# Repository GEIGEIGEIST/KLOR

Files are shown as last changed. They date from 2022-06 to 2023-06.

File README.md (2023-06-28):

<picture>
  <source media="(prefers-color-scheme: dark)" srcset="/docs/images/klor-font-logo-dark.svg">
  <source media="(prefers-color-scheme: light)" srcset="/docs/images/klor-font-logo-bright.svg">
  KLOR logo font
</picture>

# KLOR SPLIT KEYBOARD

KLOR is a 36-42 key column-staggered split keyboard. It supports a per-key RGB matrix, encoders, OLED displays, haptic feedback, speakers, a Pixart Paw3204 trackball, the [SplitKB tenting puck](https://splitkb.com/products/tenting-puck), and four different layouts, through break-off parts.

***

## LAYOUTS

KLOR layouts

***

## IMAGES

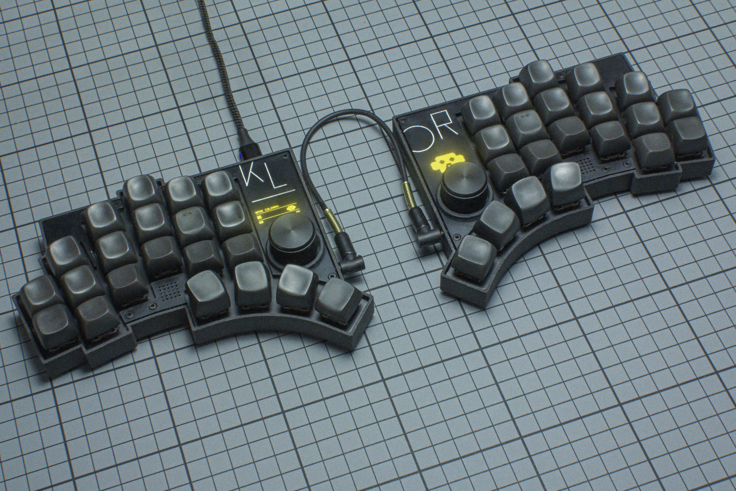
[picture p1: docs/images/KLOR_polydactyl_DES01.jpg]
KLOR polydactyl


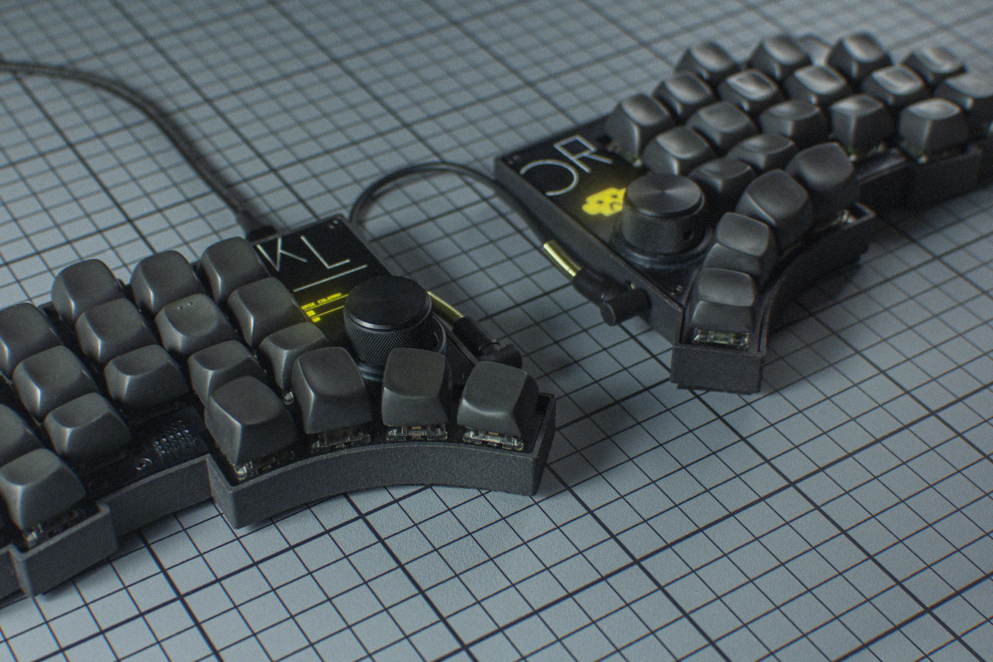
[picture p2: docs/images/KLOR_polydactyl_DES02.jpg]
KLOR polydactyl


▲ KLOR polydactyl with 3DP case and DES keycaps.

***

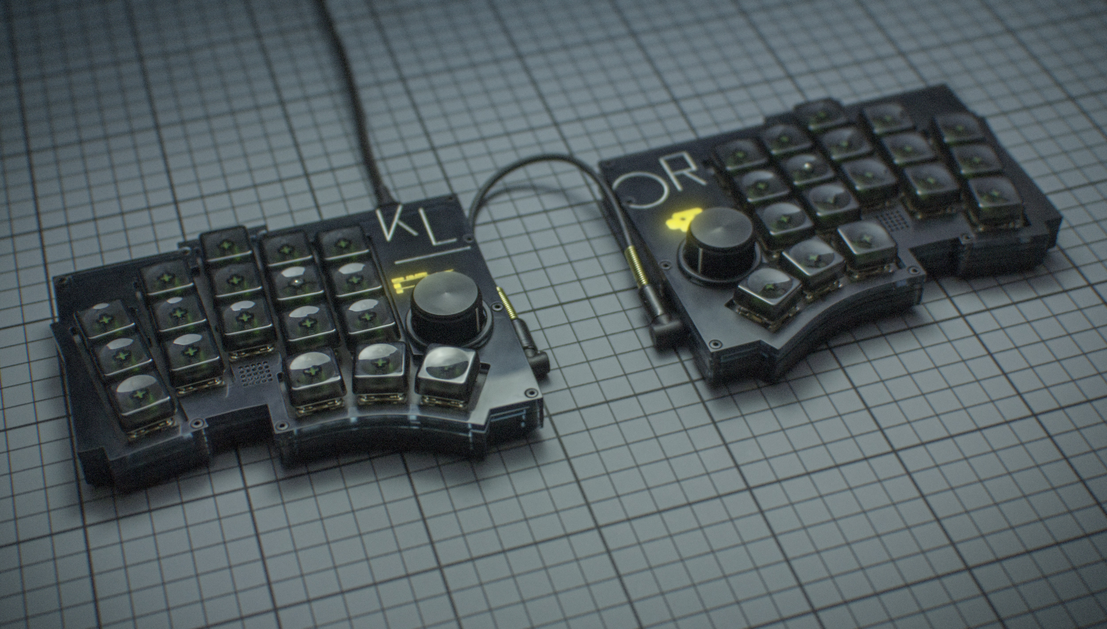
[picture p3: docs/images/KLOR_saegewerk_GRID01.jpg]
KLOR saegewerk


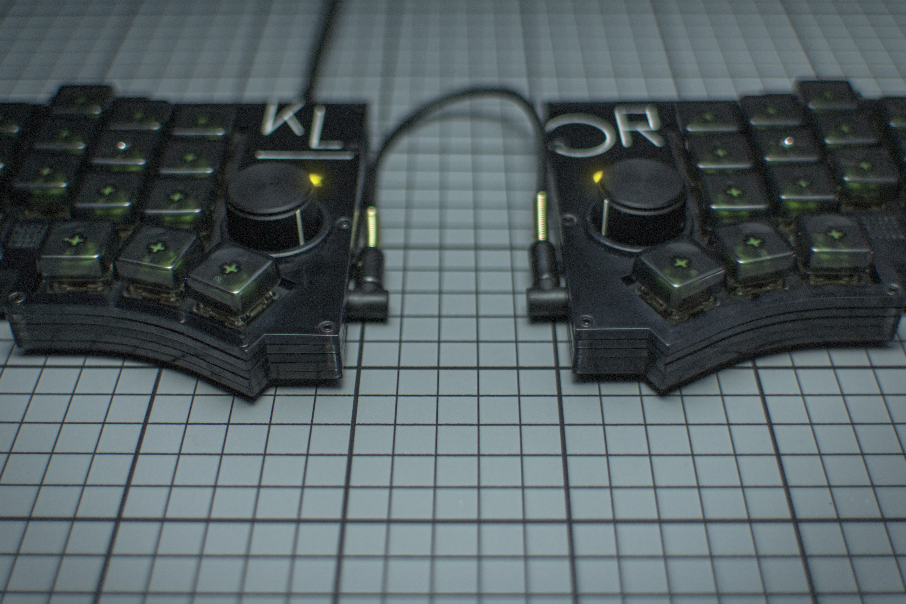
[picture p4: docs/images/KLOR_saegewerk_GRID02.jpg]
KLOR saegewerk


▲ KLOR saegewerk with stacked acrylic case and GRID keycaps.

***

## PCB 

[Here](/PCB/) you can find the KiCad files and Gerbers for the KLOR. 

***

## CASE

[Here](/case/) are the case files for the KLOR. There is an acrylic case and a 3D printed case (which uses acrylic too) for every layout.

***

## SWITCHPLATE

In every case directory you'll find the matching switchplates as **.dxf**, **.svg**, **.stl**, and a **.zip**-file, containing gerber files for a FR4 plate.

***

## KNOB

You can use pretty much any knob, which works with the EC11 encoder, but [here](/knob/) you can find one, I designed for the KLOR.

***

## BUILD GUIDE

Here you can find the build guides for the KLOR.\
[KLOR build guide 3DP case](/docs/buildguide_3DP.md) (QMK)\
[KLOR build guide stacked acrylic case](/docs/buildguide_acrylic.md) (QMK)\
[KLOR BLE build guide 3DP case](/docs/buildguide_3DP_ble.md) (ZMK)\
[KLOR BLE build guide stacked acrylic case](/docs/buildguide_acrylic_ble.md) (ZMK)

***

## FIRMWARE

[QMK config](https://github.com/GEIGEIGEIST/qmk-config-klor) (supports OLED, encoders, LEDs, haptic feedback and speakers)\
[ZMK config](https://github.com/GEIGEIGEIST/zmk-config-klor) (supports OLED, encoder, LEDs and Bluetooth)\
[KMK config](https://github.com/moritz-john/kmk-config-klor) (supports OLED, encoders, LEDs and speakers) made by [Moritz John](https://github.com/moritz-john)\
Thanks to [Manna Harbour](https://github.com/manna-harbour) you can find KLOR in [Miryoku ZMK](https://github.com/manna-harbour/miryoku_zmk)

***

## CHOC/KS27 VERSION

[Sadek Baroudi](https://github.com/sadekbaroudi) did an amazing job in creating a version of the KLOR which supports KS-27 and Choc V1 switches. Including a special case for it.\
[KLOR Sadek KS-27 and Choc V1 mod](https://github.com/sadekbaroudi/KLOR)

***

## CREDITS

The KLORs hardware is based on the [Sofle](https://github.com/josefadamcik/SofleKeyboard) by [Josef Adamcik](https://github.com/josefadamcik).\
Other inspirations are 
- [Kyria](https://splitkb.com/products/kyria-pcb-kit) by [Thomas Baart](https://github.com/splitkb)
- [Yacc46](https://github.com/1m38/keyboards/tree/main/yacc46) by [1m38](https://github.com/1m38)
- [Elephant42](https://github.com/illness072/elephant42) by [illness072](https://github.com/illness072)
- [Torn](https://github.com/rtitmuss/torn) by [Richard Titmuss](https://github.com/rtitmuss)
- [Claw44](https://github.com/yfuku/claw44) by [yfuku](https://github.com/yfuku)

I used the Pimoroni Haptic Buzz Footprint from the [Buzzard](https://github.com/crehmann/Buzzard) by [Christoph Rehmann](https://github.com/crehmann).

***

People who helped me create this board and fix stuff
- [KarlK90](https://github.com/KarlK90)
- [MangoIV](https://github.com/MangoIV)
- [OxCB](https://github.com/0xCB-dev)
- [MicroFortnight](https://github.com/microfortnight)
- [dreipunkteinsvier](https://github.com/dreipunkteinsvier)

If you build a KLOR I would be pretty happy to see some pictures. And if you want to leave me a tip you can do this [here](https://ko-fi.com/geigeigeist) (but please don't feel pressured)

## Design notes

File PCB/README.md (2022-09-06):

# KLOR PCB FILES

## MANUFACTURING
If you want to get the PCB made you need to download the [ZIP](/PCB/klor1_3/KLOR_1-3_gerbers.zip/) and upload it to the website of the manufacture ([JLCPCB](https://jlcpcb.com/) or [PCBway](https://www.pcbway.com/) for example).

- download [the ZIP file](/PCB/klor1_3/KLOR_1-3_gerbers.zip/)
- upload the ZIP file
- sometimes the Gerber preview from JLCPCB can't display the PCB, even when the files are fine. In this case use this dimensions: 159.8 mm* 118 mm
- PCB Thickness 1.6mm
- 2 layers
- PCB Qty as much as you like. But be aware, that you need 2 PCBs for one keyboard
- PCB Color Black
- No impedance control
- Surface Finish HASL(with lead) if you want the easiest soldering experience or LeadFree HASL.
- Remove Order Number Yes

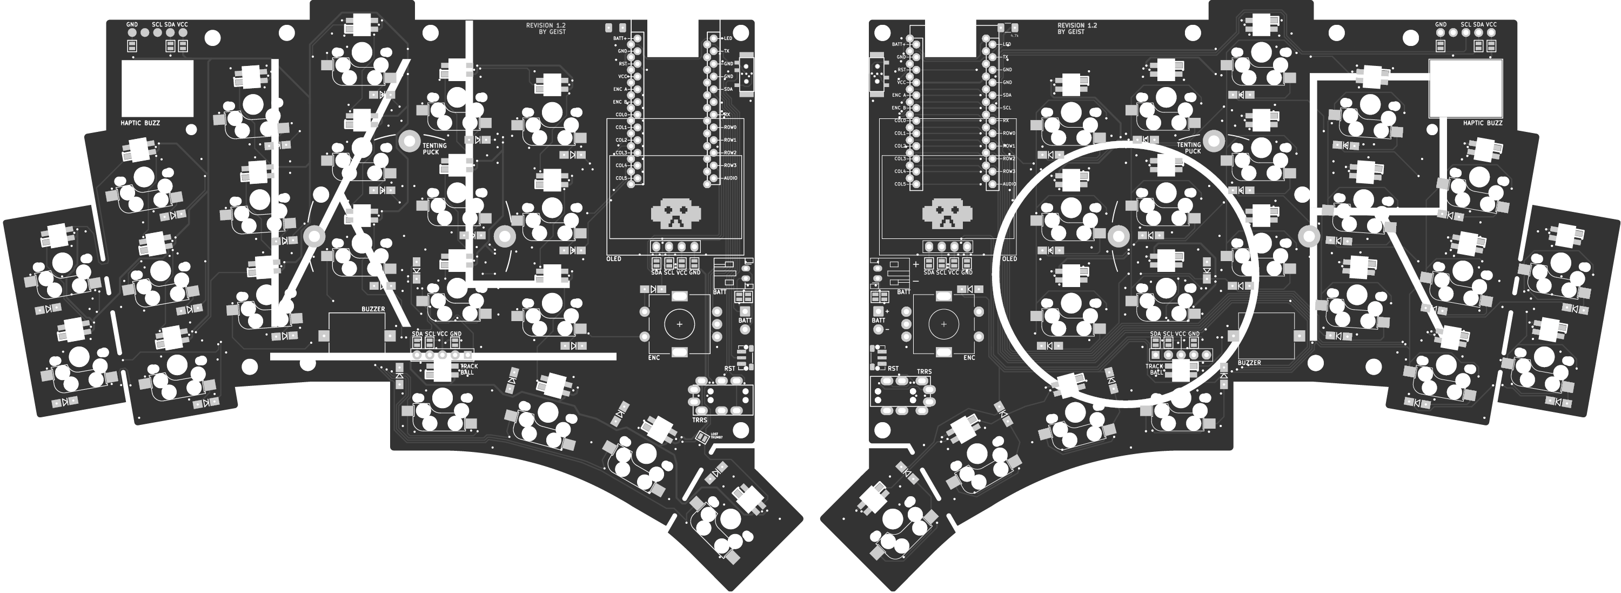
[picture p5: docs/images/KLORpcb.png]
KLOR pcb


## CHECK TRACES OR PINOUT

If you only want to check the traces or see what is connected to which pin you can take a look at these graphics.

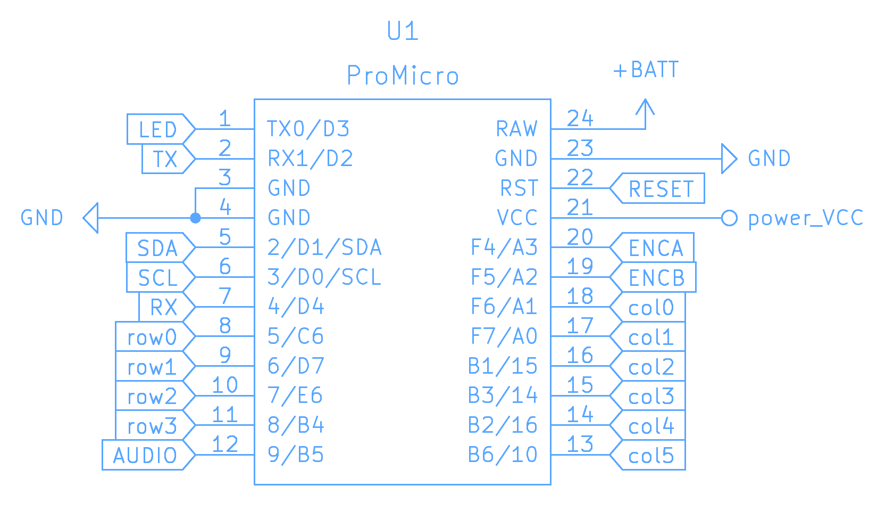
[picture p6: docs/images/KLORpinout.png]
KLOR pinout

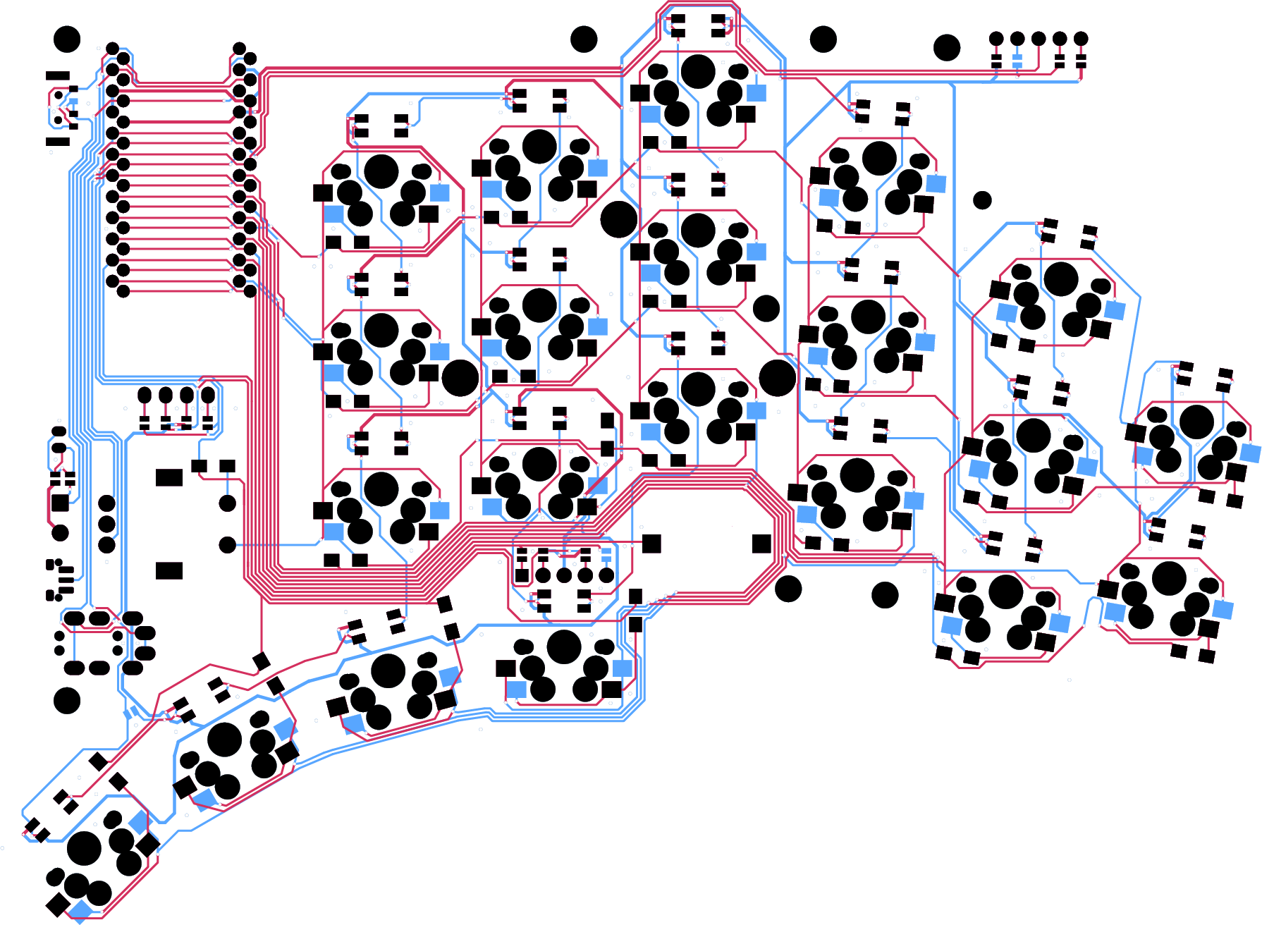
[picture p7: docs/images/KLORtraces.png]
KLOR traces

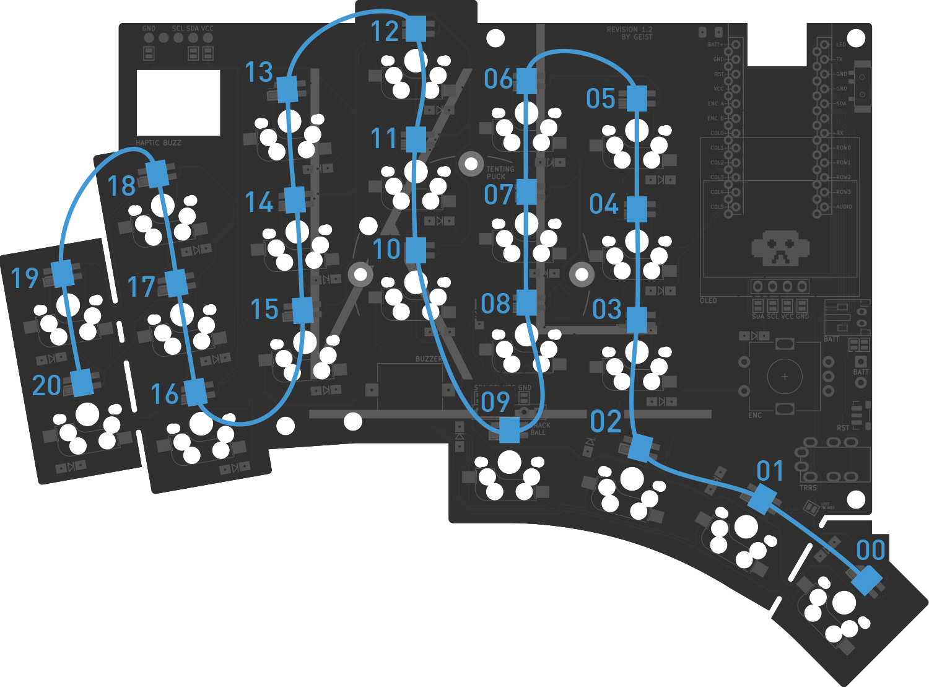
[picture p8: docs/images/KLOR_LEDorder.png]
KLOR LED order


## TAKE A DEEPER LOOK OR MODIFY 

You can download the project if you need to take a deeper look or modify something. You need the Open Source software [KiCad](https://www.kicad.org/) to open it.

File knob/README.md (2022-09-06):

# KLOR KNOB

This is the EC11 encoder knob for the KLOR. You should be able to print it in FDM, but for best results consider to print it in SLA or MJF.\
I can recommend to get it printed at [JLCPCB](https://jlcpcb.com/)

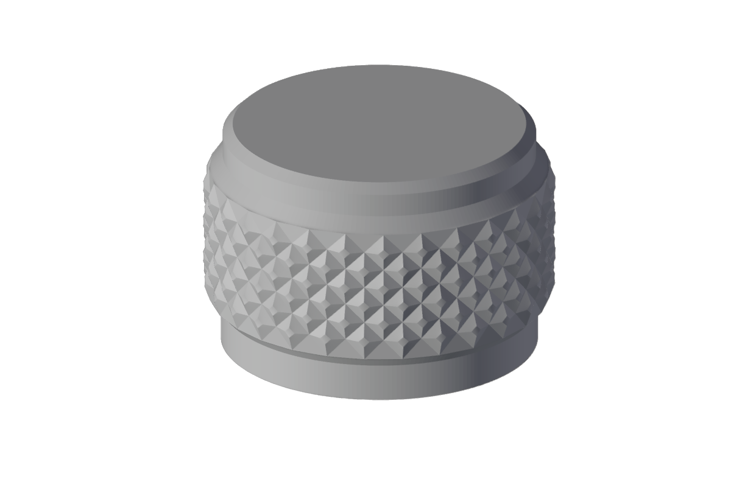
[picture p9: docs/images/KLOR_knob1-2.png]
KLOTZ knob


Here you can see it printed in black resin (left) and MJF nylon (right).

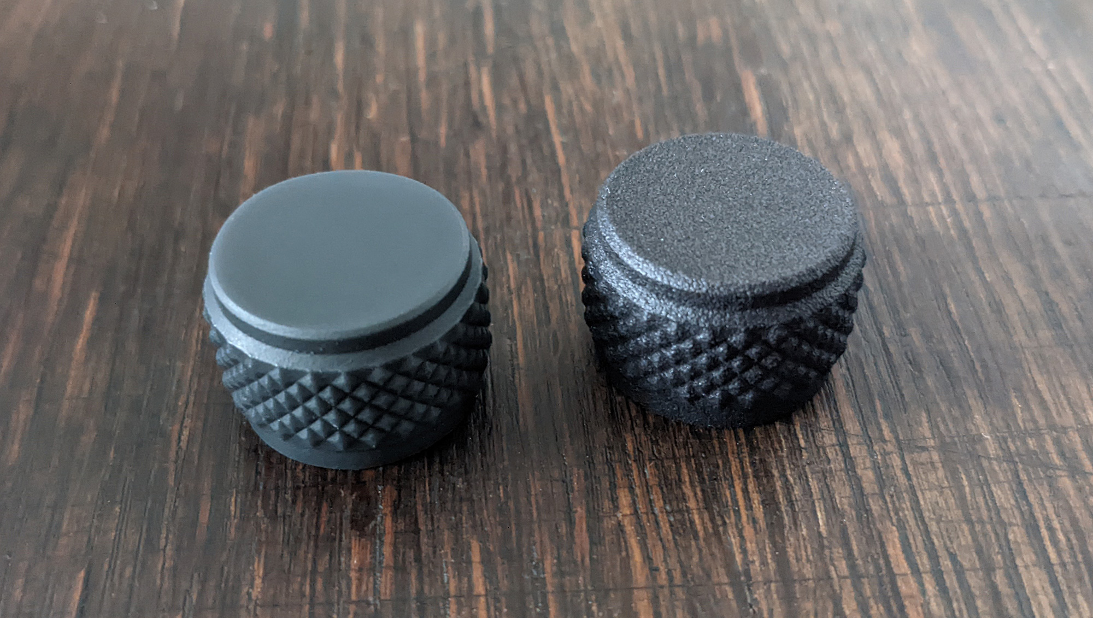
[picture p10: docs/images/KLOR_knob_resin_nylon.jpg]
KLOTZ knob materials


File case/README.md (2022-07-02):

# KLOR CASE FILES

First you need to decide if you plan to use a stacked acrylic case or a 3D printed case (which also contains acrylic parts).\
You can click on the image left for the acrylic case and on the image right for the 3D printed case.

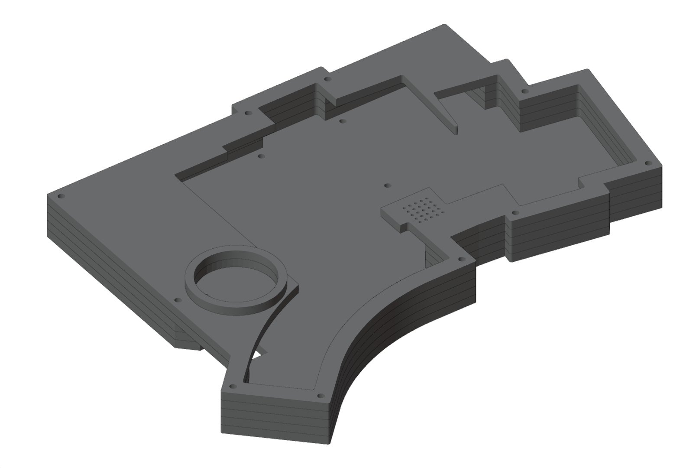
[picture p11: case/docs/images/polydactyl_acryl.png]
stacked acrylic case
[](/case/acrylic/)
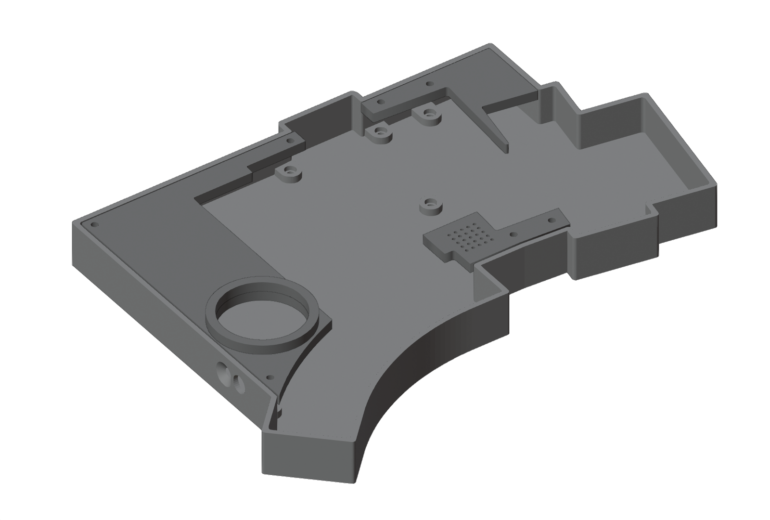
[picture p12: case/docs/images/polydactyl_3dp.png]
3D printed case
[](/case/3DP/)

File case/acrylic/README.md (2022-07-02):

# KLOR ACRYLIC CASE FILES

Next you need to decide which layout you want to use. 

[polydactyl](/case/acrylic/polydactyl/)
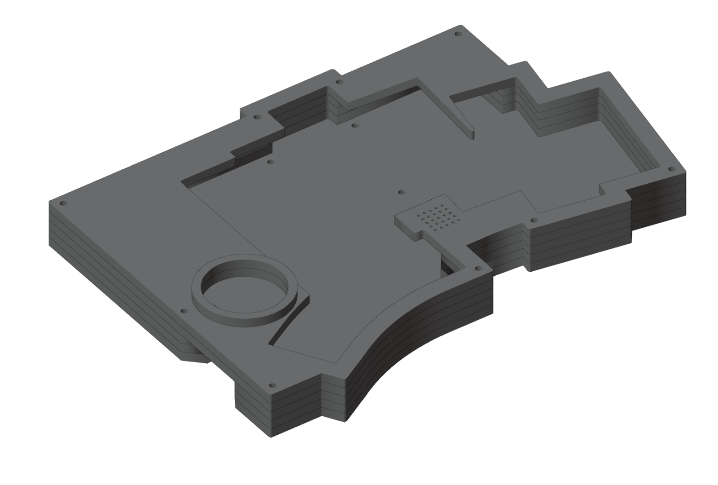
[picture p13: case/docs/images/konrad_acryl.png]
konrad
[](/case/acrylic/konrad/)
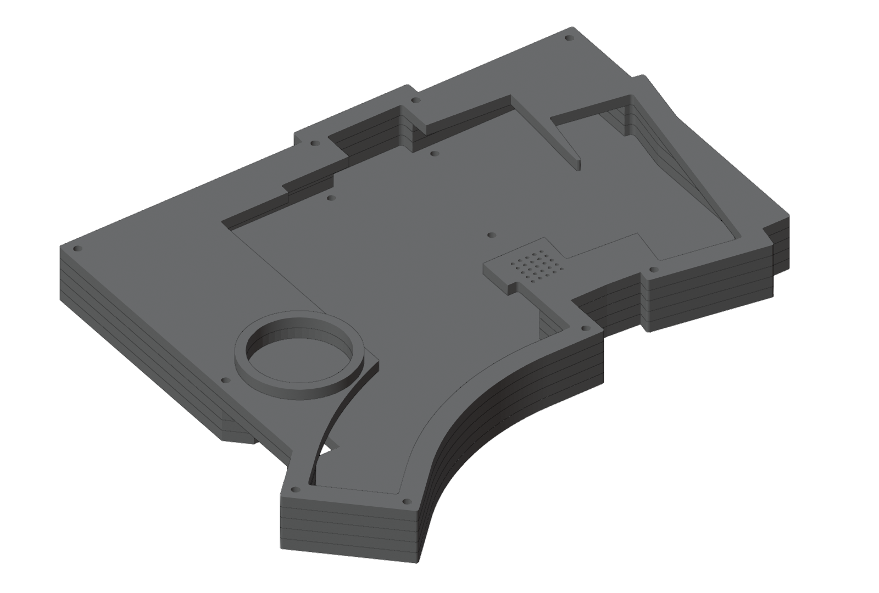
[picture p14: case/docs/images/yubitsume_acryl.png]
yubitsume
[](/case/acrylic/yubitsume/)
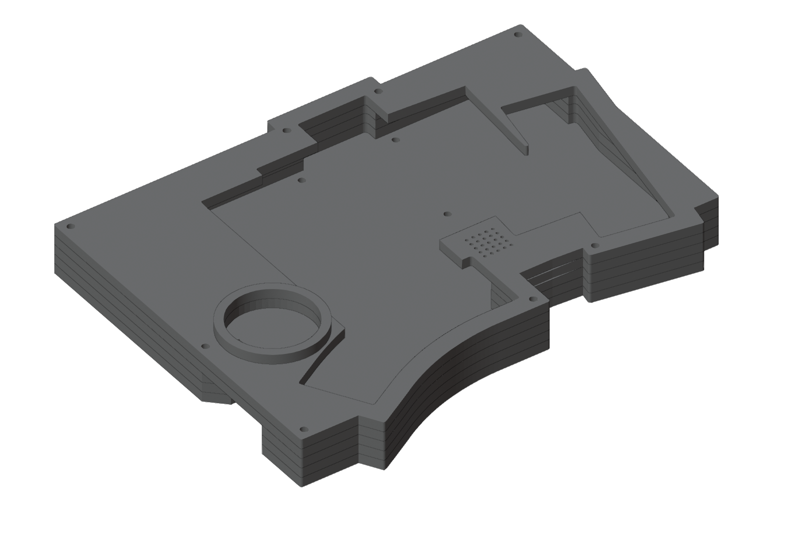
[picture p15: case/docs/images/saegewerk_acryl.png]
saegewerk
[](/case/acrylic/saegewerk/)

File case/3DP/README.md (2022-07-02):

# KLOR 3DP CASE FILES

Next you need to decide which layout you want to use. 

[polydactyl](/case/3DP/polydactyl/)
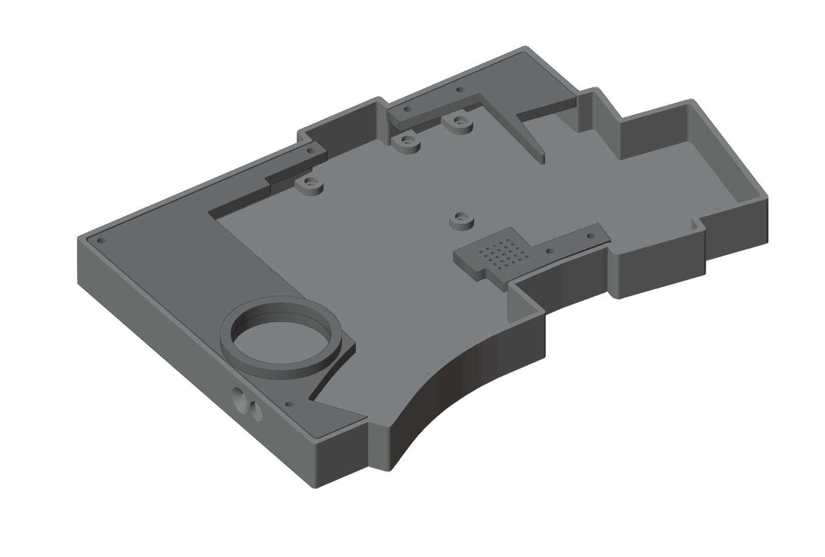
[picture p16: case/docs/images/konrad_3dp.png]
konrad
[](/case/3DP/konrad/)
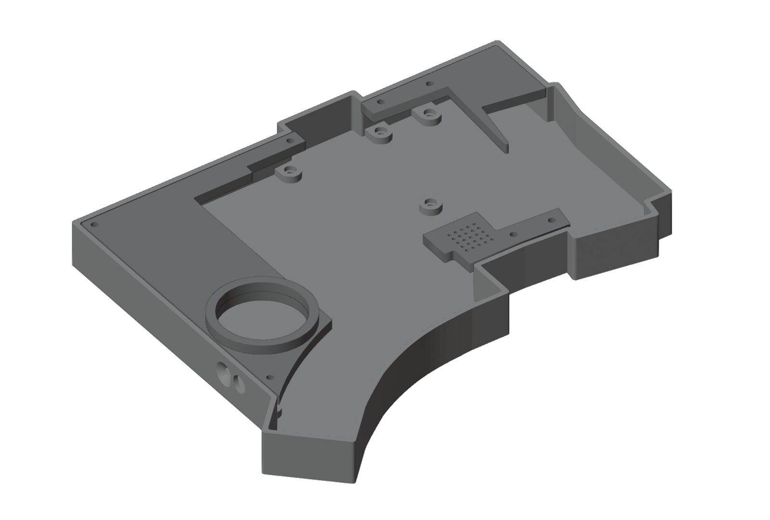
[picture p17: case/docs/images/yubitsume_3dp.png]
yubitsume
[](/case/3DP/yubitsume/)
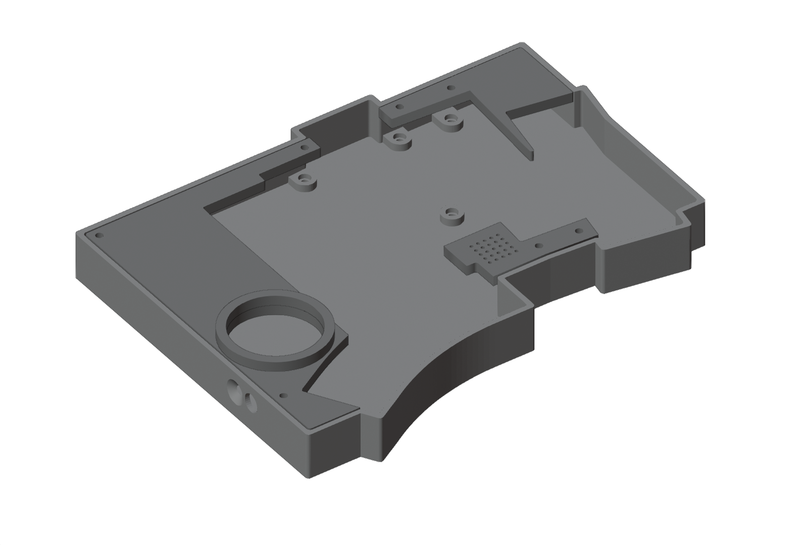
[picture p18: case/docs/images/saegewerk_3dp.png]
saegewerk
[](/case/3DP/saegewerk/)

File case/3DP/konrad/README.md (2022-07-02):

# KLOR KONRAD 3DP CASE FILES 

If you want to use the KLOR wireless (through ZMK) you need to choose the bluetooth case. If you plan on using it wired (through QMK) you should choose the regular case. The differences are a cutout for a JST connector in the bottom plate and another one for the ON/OFF switch in the side of the case.\

> **Note**
> You need a switchplate and the acrylic parts, no matter what case you choose.

[konrad](/case/3DP/konrad/regular/)
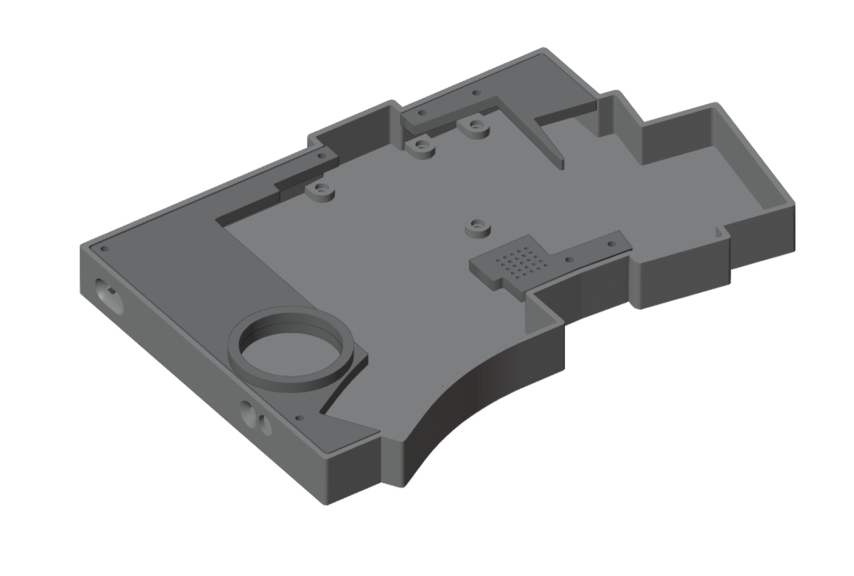
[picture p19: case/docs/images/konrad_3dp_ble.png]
konrad bluetooth
[](/case/3DP/konrad/bluetooth/)

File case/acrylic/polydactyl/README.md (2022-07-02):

# KLOR POLYDACTYL ACRYLIC CASE FILES 

If you want to use the KLOR wireless (through ZMK) you need to choose the bluetooth case. If you plan on using it wired (through QMK) you should choose the regular case. The differences are a cutout for a JST connector in the bottom plate and another one for the ON/OFF switch in the side of the case.\

> **Note**
> You need a switchplate, no matter what case you choose.

[polydactyl](/case/acrylic/polydactyl/regular/)
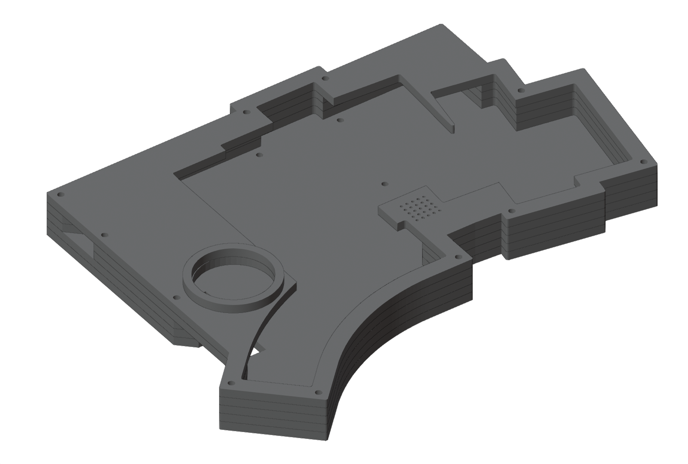
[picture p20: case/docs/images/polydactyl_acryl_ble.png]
polydactyl bluetooth
[](/case/acrylic/polydactyl/bluetooth/)

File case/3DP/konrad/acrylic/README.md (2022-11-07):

# KLOR KONRAD 3DP CASE ACRYLIC PARTS

You should choose a dark smokey acrylic glass like 7C83 from Plexiglass to hide the OLED, while you can still see it's light shine through the top layer.\
The thickness of the acrylic should be 3mm.\

acrylic case parts

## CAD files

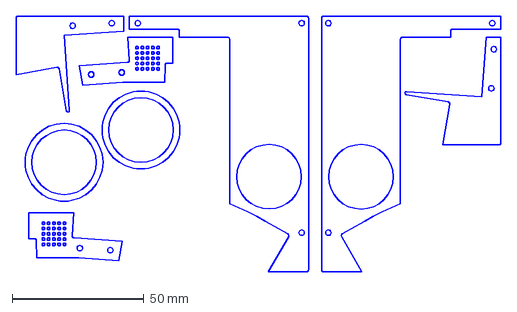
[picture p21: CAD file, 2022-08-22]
case/3DP/konrad/acrylic/KLOR_konrad_3DPcase_acrylic.dxf
183.7 x 96.8 mm

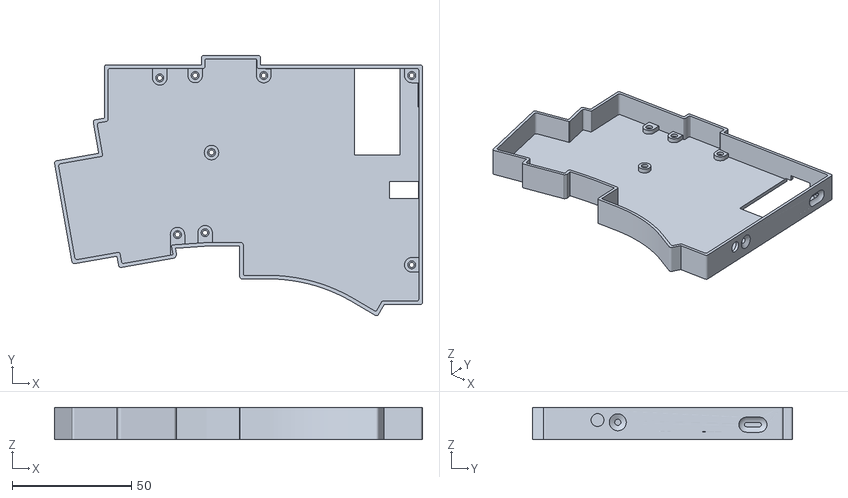
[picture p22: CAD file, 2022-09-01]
case/3DP/konrad/bluetooth/KLOR_konrad_case_ble_L.stl
154.3 x 109.2 x 13.6

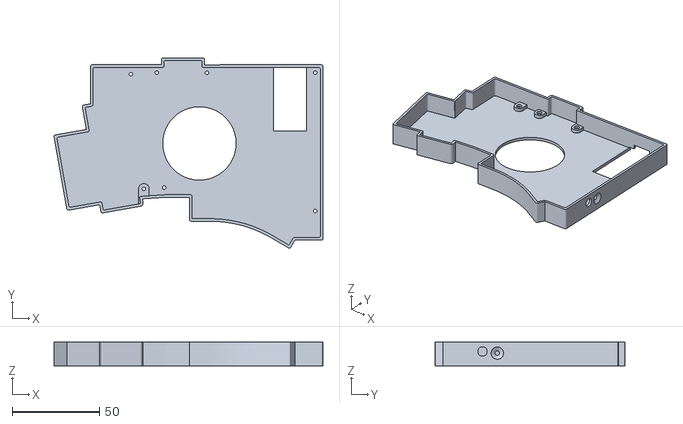
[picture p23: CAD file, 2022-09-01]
case/3DP/konrad/regular/KLOR_konrad_case_puck_L.stl
154.3 x 109.2 x 13.6

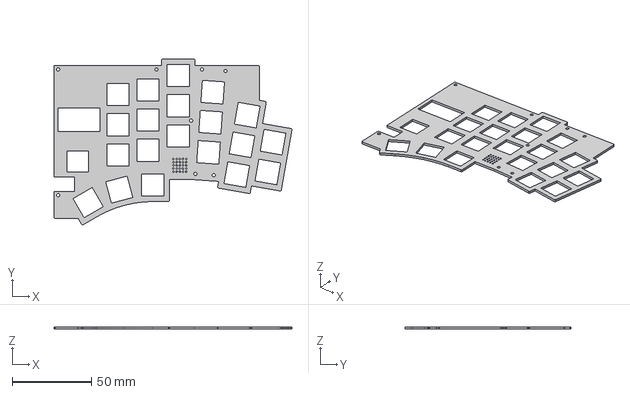
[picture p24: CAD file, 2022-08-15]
case/3DP/konrad/switchplate/KLOR_konrad_3DP_switchplate.step
150.3 x 104.8 x 1.50 mm

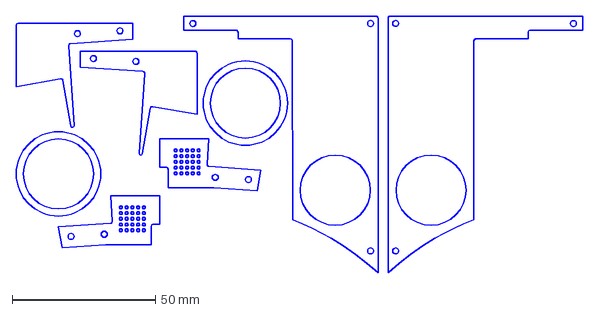
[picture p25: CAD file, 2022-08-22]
case/3DP/polydactyl/acrylic/KLOR_polydactyl_3DPcase_acrylic.dxf
197.8 x 89.7 mm

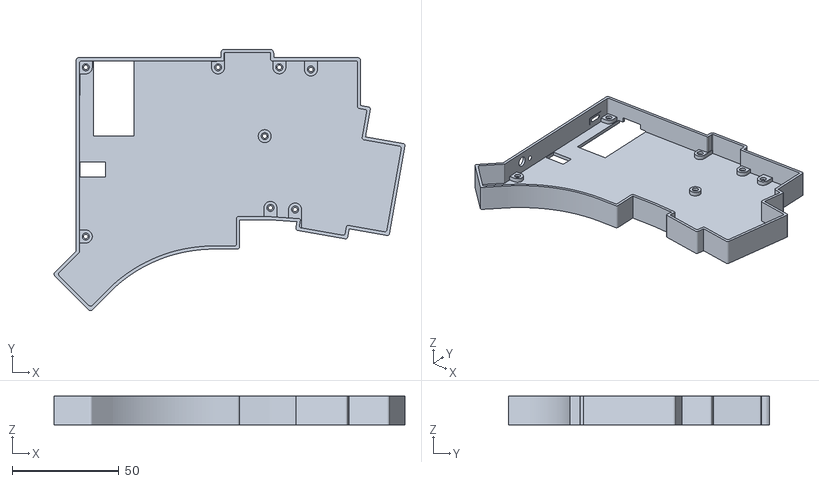
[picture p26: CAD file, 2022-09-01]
case/3DP/polydactyl/bluetooth/KLOR_polydactyl_case_ble_R.stl
164.7 x 122.7 x 13.6

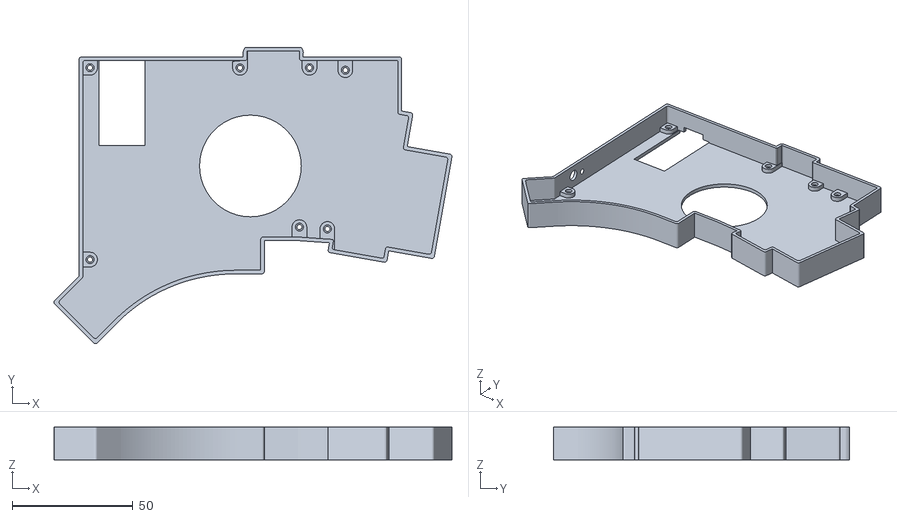
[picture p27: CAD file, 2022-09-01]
case/3DP/polydactyl/regular/KLOR_polydactyl_case_puck_R.stl
164.7 x 122.7 x 13.6

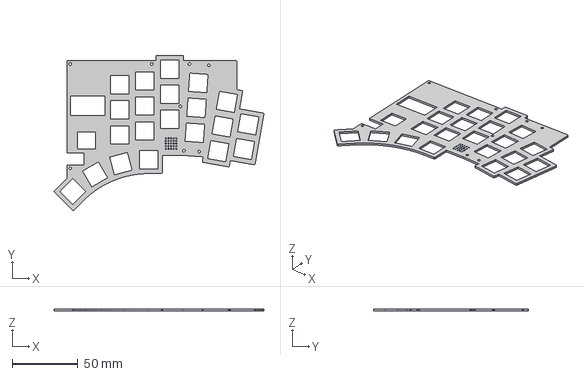
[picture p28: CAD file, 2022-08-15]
case/3DP/polydactyl/switchplate/KLOR_polydactyl_3DP_switchplate.step
160.0 x 118.2 x 1.50 mm

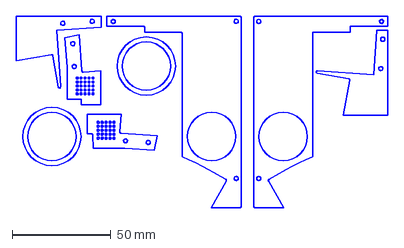
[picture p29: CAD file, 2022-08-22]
case/3DP/saegewerk/acrylic/KLOR_saegewerk_3DPcase_acrylic.dxf
188.1 x 96.8 mm

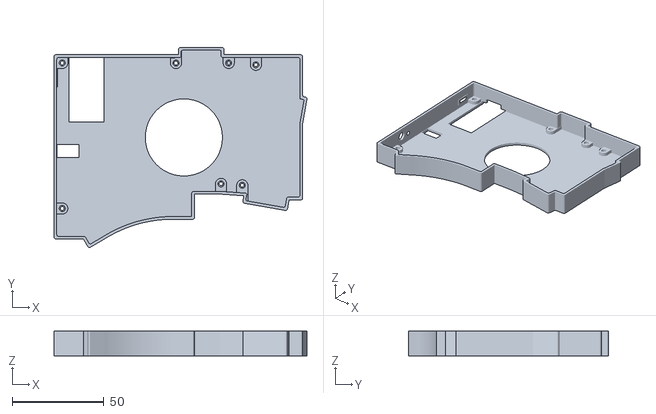
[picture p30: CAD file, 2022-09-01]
case/3DP/saegewerk/bluetooth/KLOR_saegewerk_case_puck_ble_R.stl
138.1 x 109.2 x 13.6

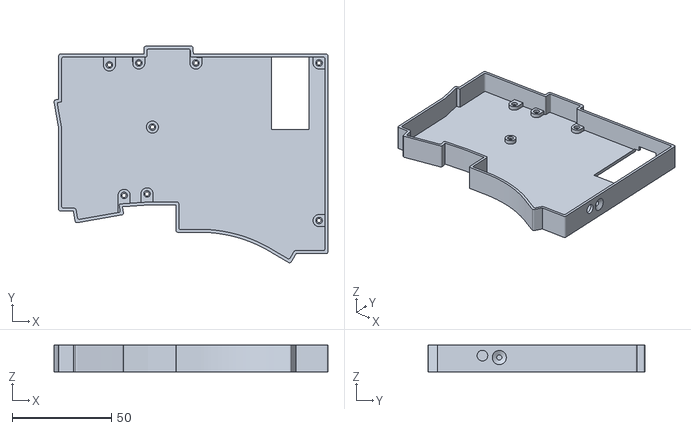
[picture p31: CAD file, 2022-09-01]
case/3DP/saegewerk/regular/KLOR_saegewerk_case_L.stl
138.1 x 109.2 x 13.6

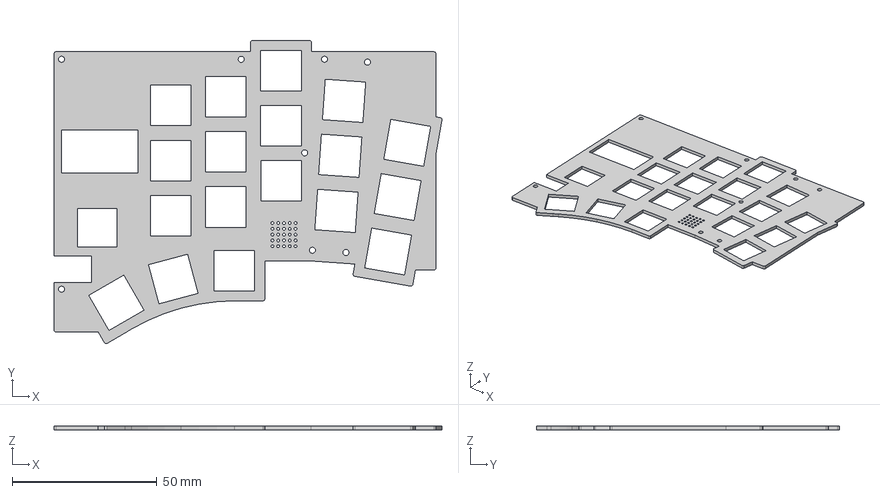
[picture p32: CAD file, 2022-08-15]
case/3DP/saegewerk/switchplate/KLOR_saegewerk_3DP_switchplate.step
134.0 x 104.8 x 1.50 mm

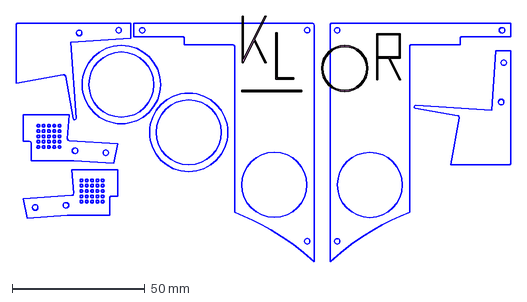
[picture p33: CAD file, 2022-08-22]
case/3DP/yubitsume/acrylic/KLOR_yubitsume_3DPcase_acrylic_logotype.dxf
186.0 x 92.4 mm

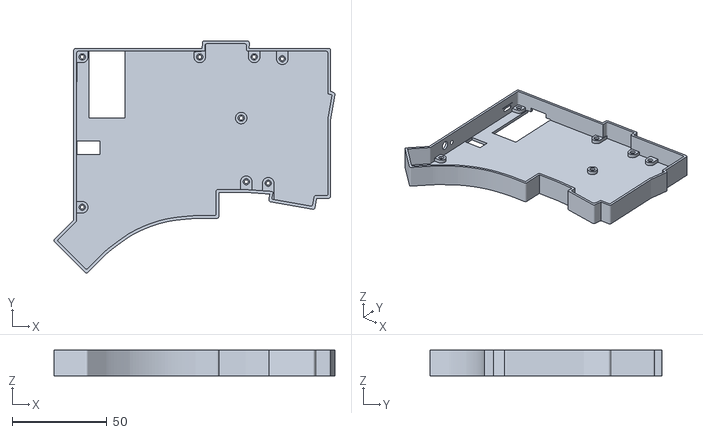
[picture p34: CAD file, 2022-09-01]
case/3DP/yubitsume/bluetooth/KLOR_yubitsume_case_ble_R.stl
148.4 x 122.7 x 13.6

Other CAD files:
case/3DP/yubitsume/regular/KLOR_yubitsume_case_R.stl
case/3DP/yubitsume/switchplate/KLOR_yubitsume_3DP_switchplate.step
case/acrylic/konrad/switchplate/KLOR_konrad_acrylic_case_switchplate.step
case/acrylic/polydactyl/switchplate/KLOR_polydactyl_acrylic_case_switchplate.step
case/3DP/konrad/acrylic/KLOR_konrad_3DPcase_acrylic_logotype.dxf
case/3DP/konrad/bluetooth/KLOR_konrad_case_ble_R.stl
case/3DP/konrad/bluetooth/KLOR_konrad_case_ble_puck_L.stl
case/3DP/konrad/bluetooth/KLOR_konrad_case_ble_puck_R.stl
case/3DP/konrad/regular/KLOR_konrad_case_L.stl
case/3DP/konrad/regular/KLOR_konrad_case_R.stl
case/3DP/konrad/regular/KLOR_konrad_case_puck_R.stl
case/3DP/konrad/switchplate/KLOR_konrad_3DP_switchplate.dxf
case/3DP/konrad/switchplate/KLOR_konrad_3DP_switchplate.stl
case/3DP/polydactyl/acrylic/KLOR_polydactyl_3DPcase_acrylic_logotype.dxf
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

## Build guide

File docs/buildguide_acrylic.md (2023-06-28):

# KLOR BUILD GUIDE (STACKED ACRYLIC CASE) [WIP]

## PART LIST

### REQUIRED PARTS

| Part name | Count | Remarks | 
| :--- | :---: | :--- |
| KLOR PCB | 02 | You can find the files for it [here](/PCB/) |
| ProMicro | 02 | Alternatively, you can use another controller with a similar pinout like the Elite-C, Puchi-C, KB2040 dda. |
| MX Key switch | 42 | 40 switches for Konrad / 38 switches for Yubitsume / 36 switches for Saegewerk |
| switch socket | 42 | 40 sockets for Konrad / 38 sockets for Yubitsume / 36 sockets for Saegewerk |
| diodes 1N4148W| 44 | These are surface mount diodes in SOD123 package. 42 for Konrad / 40 for Yubitsume / 38 for Saegewerk |
| 1u MX keycaps | 42 | 40 keycaps for Konrad / 38 keycaps for Yubitsume / 36 keycaps for Saegewerk |
| OLED module | 02 | SSD1306 128x64 pixel OLED Displays |
| reset button  | 02 | Alps SKRTLAE010 |
| TRRS jack | 02 | MJ-4PP-9 or PJ320A |
| TRRS cable | 01 | Alternatively, you can use a TRS cable for [half-duplex](https://github.com/qmk/qmk_firmware/blob/master/docs/serial_driver.md#usart-half-duplex)|
| EC11 encoder  | 02 | You can use any EC11 encoder, but it will look better if you use a short one, like the EC11N1524402 |
| encoder knob  | 02 | The design works best with a 2,2cm encoder knob. I'd recommend kilo international knobs with a number starting with 90. You could also use the [knob](/knob/) I designed for the KLOR, based on the kilo knob. 
| USB cable | 01 | For connecting the keyboard to your PC |

### OPTIONAL PARTS

| Part name | Count | Remarks | 
| :--- | :---: | :--- |
| MCU sockets | 04 | For socketing your MCU. Highly recommended |
| MCU pins | 48 | In combination with the MCU sockets |
| SK6812 Mini LED (not Mini-E) 3535 size | 42 | 40 LEDs for Konrad / 38 LEDs for Yubitsume / 36 LEDs for Saegewerk |
| [Haptic Feedback Module](https://shop.pimoroni.com/products/drv2605l-linear-actuator-haptic-breakout) | 01 | Pimoroni Haptic Buzz |
| speaker | 01 | Mallory AST1109MLTRQ or Keliking KLJ-1102 |
| [trackball](https://bit-trade-one.co.jp/selfmadekb/adtb7m/) | 01 | Pixart PAW3204OA. Available at [Yushakobo](https://shop.yushakobo.jp/products/adtb7m) |
| [level converter](https://github.com/sekigon-gonnoc/LevelConverterForTrackballModule) | 01 | Needed to use the trackball. You can get it from [Yushakobo](https://shop.yushakobo.jp/products/a0800tl-01-1/) |
| [tenting puck](https://splitkb.com/products/tenting-puck)| 02 | SplitKB Tenting Puck |

### ACRYLIC CASE PARTS

| Part name | Count | Remarks | 
| :--- | :---: | :--- |
| acrylic parts | 02 | Find the case files [here](/case/acrylic/) |
| switch plate | 02 | 1.5mm switch plate |
| 9mm M2 standoffs | 22 | Up to 22 9mm round standoffs for the actual case (check the appropriate puzzle guide) |
| 7mm M2 standoffs | 12 | 7mm round standoffs for holding the PCB in place |
| 6mm M2 screws | 56 | Up to 56 regular 6mm M2 screws (check the appropriate puzzle guide) |
| 5mm M2 wafer head screws | 12 | These screws need a flat head to fit under the acrylic top layer |

## INTRODUCTION

Here is an overview of where and on which side each component needs to be soldered (click on the image to see a larger version).

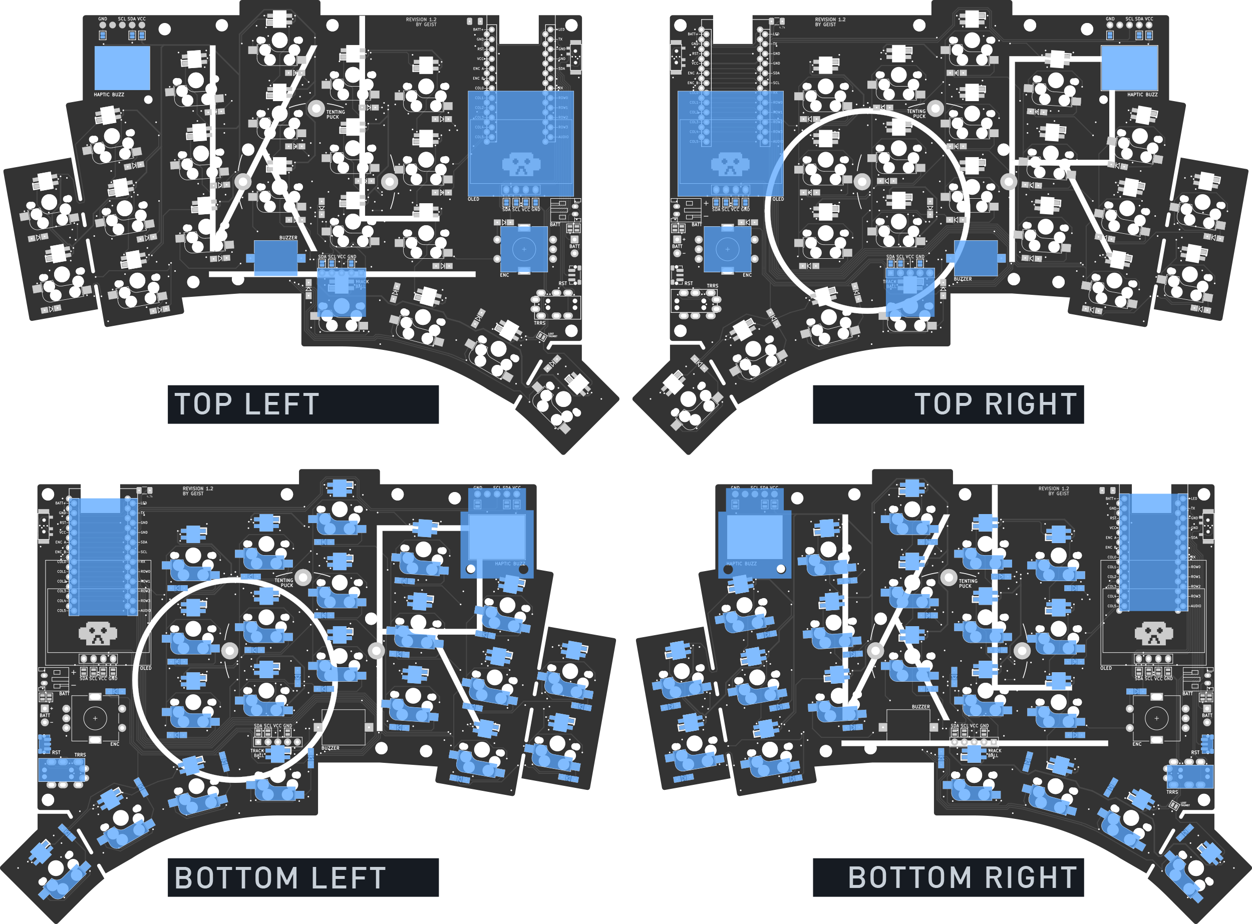
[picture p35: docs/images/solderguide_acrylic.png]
KLOR solder guide


To see what component needs to sit where you can take a look at the [interactive HTML BOM](https://htmlpreview.github.io/?https://github.com/GEIGEIGEIST/KLOR/blob/main/docs/klor_rev1-3_ibom.html).

> **Warning**
> This interactive HTML BOM does show where each component is located, but please still refer to the soldering guide above to see if a component needs to go on the top or bottom of the PCB.

Be aware that for the 3D-printed case, some components need to be soldered on the opposite side.\
Some people mark the top and bottom with tape to keep track of which side is which, as the PCB is reversible.\
Begin with the flat components and progress to the higher ones, ending with the OLEDs and the encoders.

***

## BREAK OFF PARTS (optional)

If you choose a layout [other than](/README.md#layouts) Polydactyl you should remove the unnecessary parts. Use a flush cutter to snip through the support sections. You can also use a boxcutter to carve in grooves, which makes it easier to break on the right spot. 

> **Warning**
> Be very careful with this step, since there is a risk to break the PCB. Probably it would be best to begin with this step, to avoid losing already soldered parts.

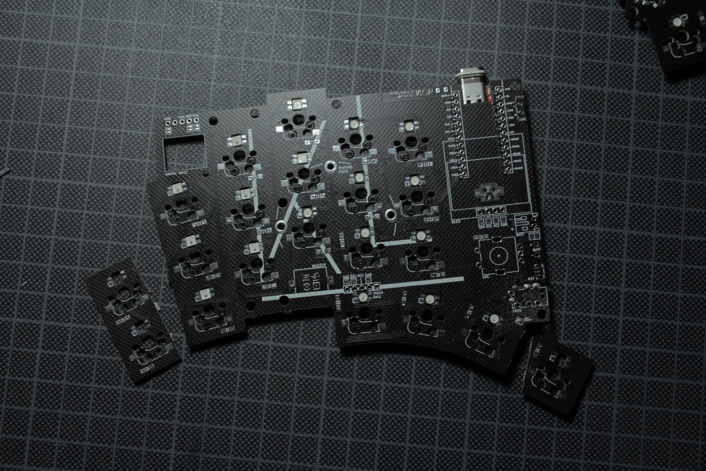
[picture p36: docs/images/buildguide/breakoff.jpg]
break off parts


You can use a file to smooth out the edges, but you should wear a mask while doing this since the FR4 dust is considered to be toxic.

***

## MICROCONTROLLER

> **Warning**
> First flash the microcontroller to make sure it works, before soldering it in.

Unlike most other boards here the microcontroller needs to be mounted on the bottom, with the components facing upwards (to the PCB).\
Feel free to use the included header pins, but it's highly recommended to use MillMax low-profile sockets.\
Place the sockets in the marked spots on the bottom side of the PCB.

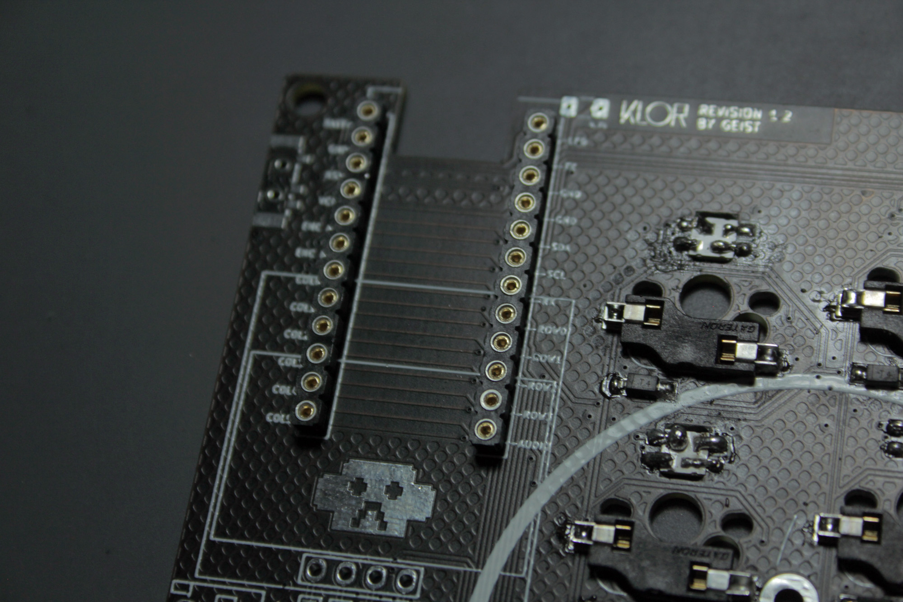
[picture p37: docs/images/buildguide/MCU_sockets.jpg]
MCU sockets


You can keep them in place by using masking tape.

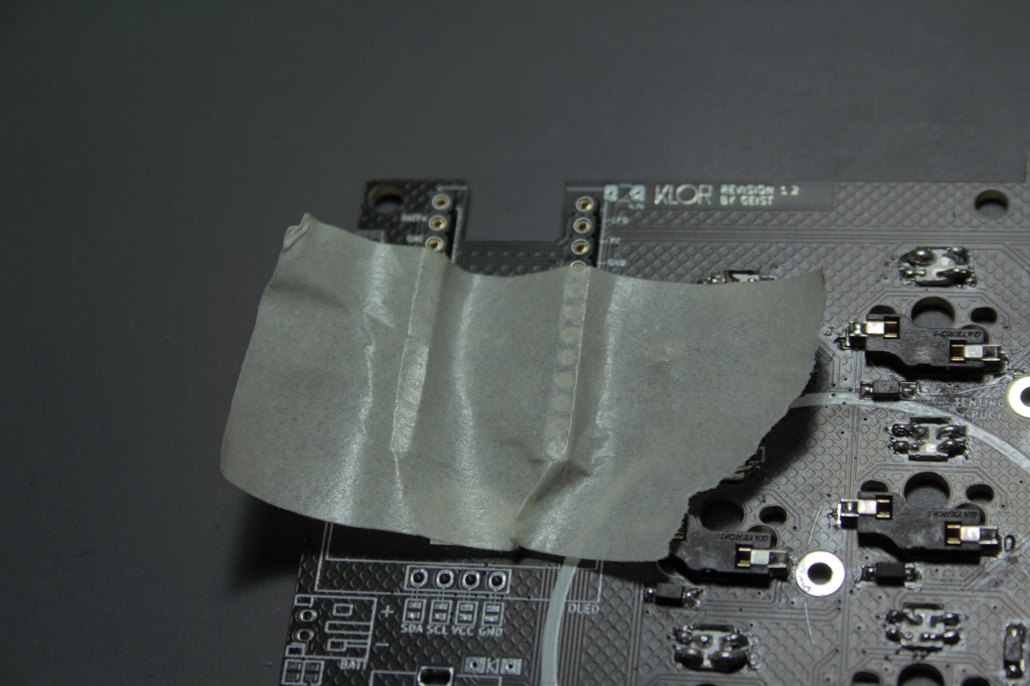
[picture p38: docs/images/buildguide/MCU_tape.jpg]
sockets taped


Then you can flip the board to solder in the sockets from the top.
Flip it again and insert the pins into the sockets.

> **Note**
> Use tweezers to insert them. Don't apply too much force, you will feel them snapping in. After that, you can carefully apply some pressure, using a flat object to make sure they're fully seated. 

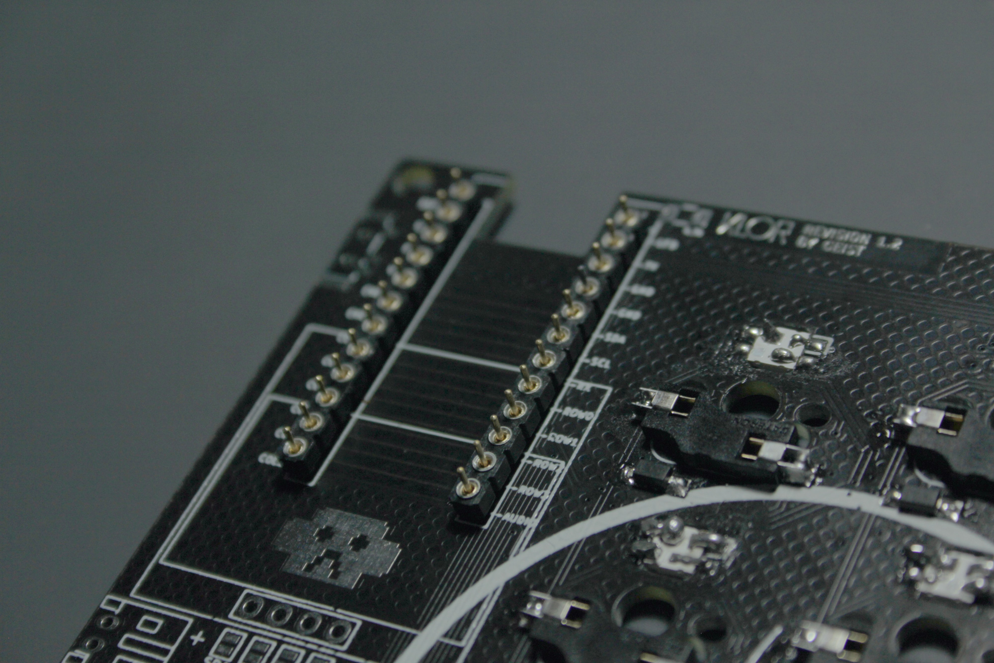
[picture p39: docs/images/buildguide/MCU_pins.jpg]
MCU pins


Now place your microcontroller on the pins (components facing the PCB) and solder it to them.\
You can use flush cutters to trim the header pins.

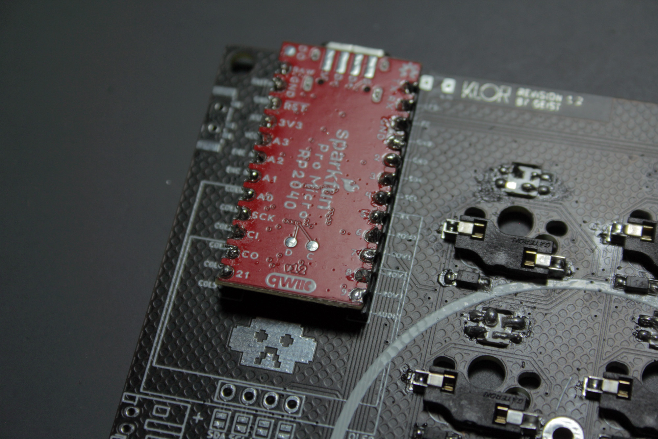
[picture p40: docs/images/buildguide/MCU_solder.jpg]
MCU solder


> **Warning**
> When trimming with flush cutters wear eye protection or hold your hand close above the pins. Otherwise, sharp metal pins flying around might hurt you.

***

## LEDS (optional)

> **Note**
> If you use a layout with three thumbs, instead of four, you need to bridge the 'lost thumb?' jumper below the TRRS sockets on the primary and secondary PCB, since the led chain lost its beginning. 

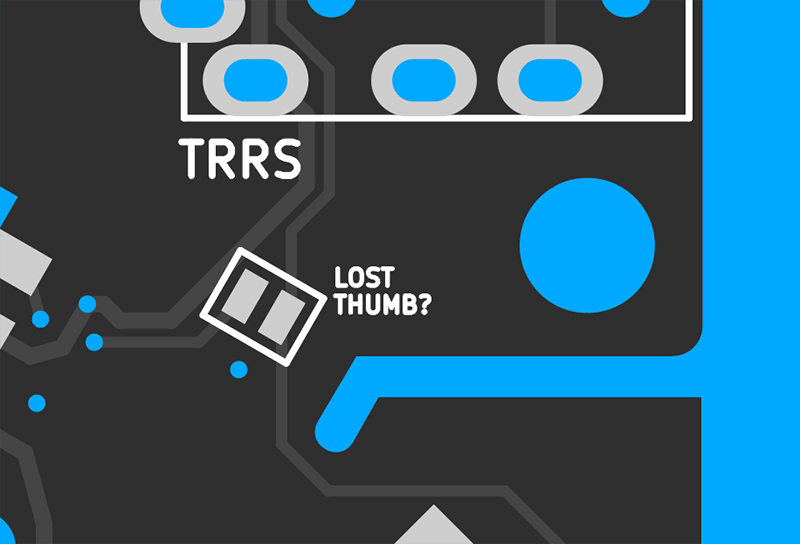
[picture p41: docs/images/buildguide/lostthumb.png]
Lost thumb jumper


LEDs are very heat sensitive. So it's a good idea to solder the pads on the PCB bottom first and then insert the LED.

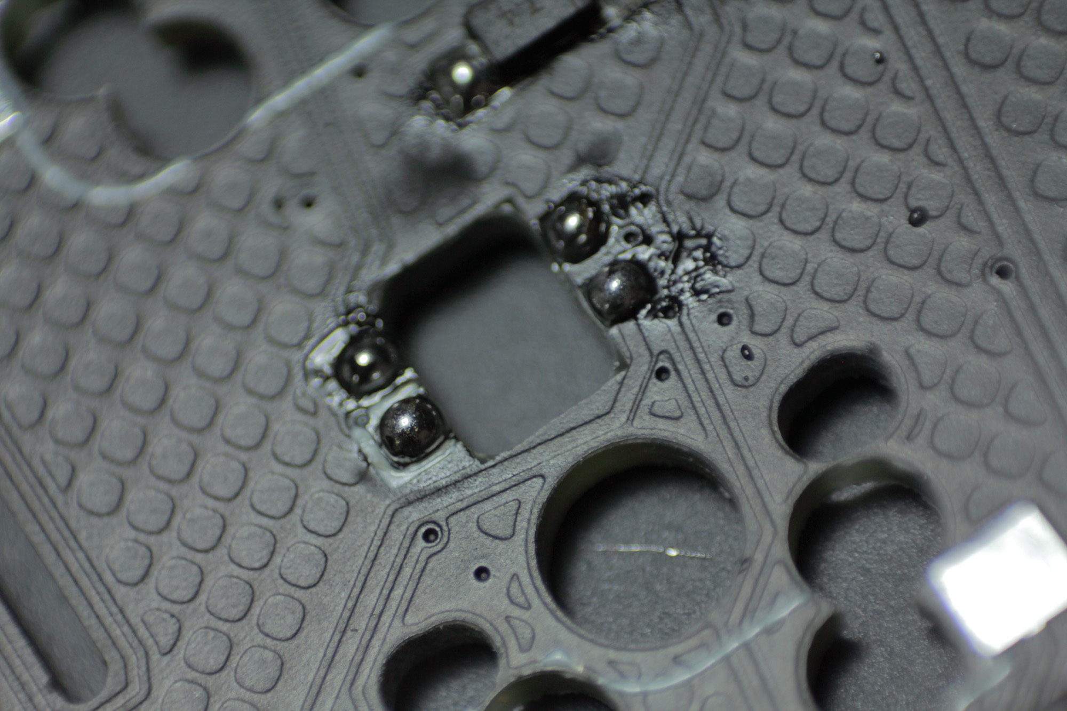
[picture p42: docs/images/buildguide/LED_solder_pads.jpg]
LED solder pads


While the bottom of the PCB is facing you, insert the LEDs in the holes. The lens should face the table.

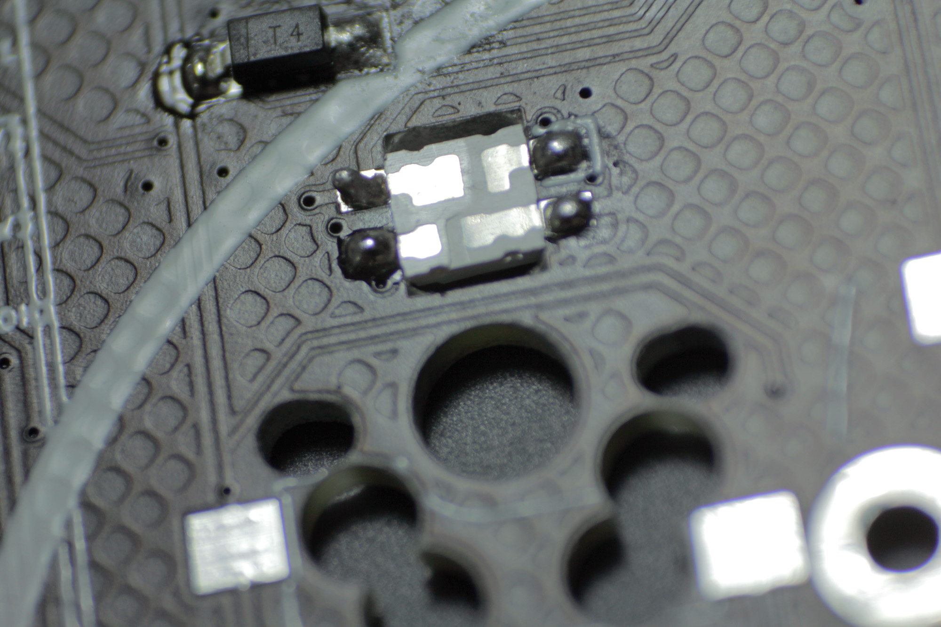
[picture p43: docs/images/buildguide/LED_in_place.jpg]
LED in place


This image depicts the correct orientation.\
The L-shaped pad on the LED needs to be connected to the square-marked pad.

LED orientation1

> **Note**
> While the orientation is uniform within one half, it differs between left and right.

> **Warning**
> It's recommended to solder the LEDs in at 220º, since they're pretty heat sensitive. Personally, I had a hard time keeping it below 270º. So my advice would be while soldering the first pad on every LED, try to be really quick. Then solder the second pad on every LED, starting with the first LED. This way they can cool down in the meantime.

Make sure the solder always builds a strong connection between the pad on the LED and the pad on the PCB. 

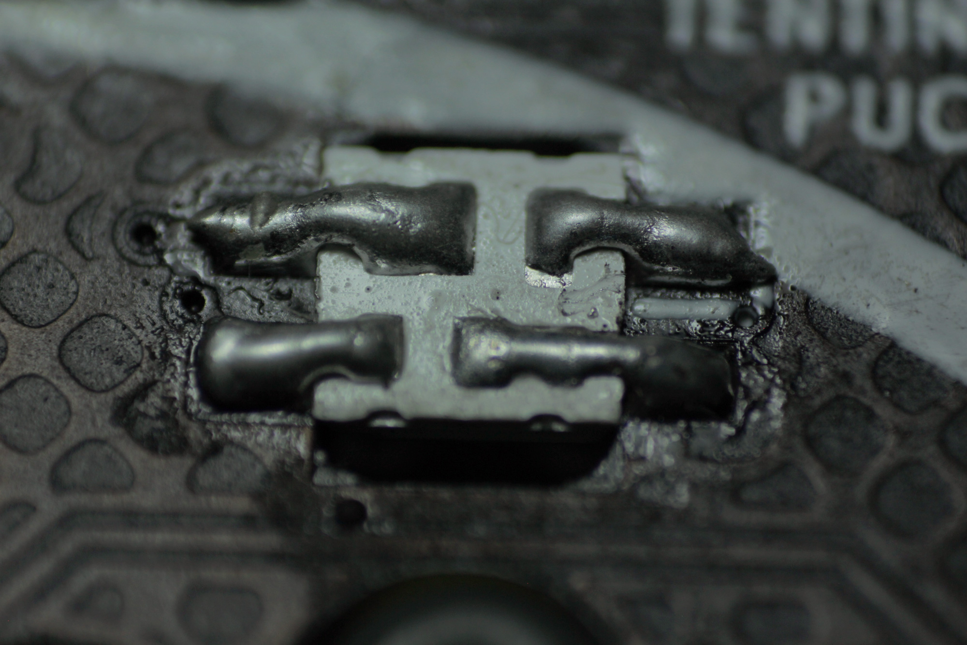
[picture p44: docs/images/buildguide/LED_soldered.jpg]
LED connection


The advantage of soldering in the microcontroller first is that you can occasionally check if all the LEDs work before continuing. 

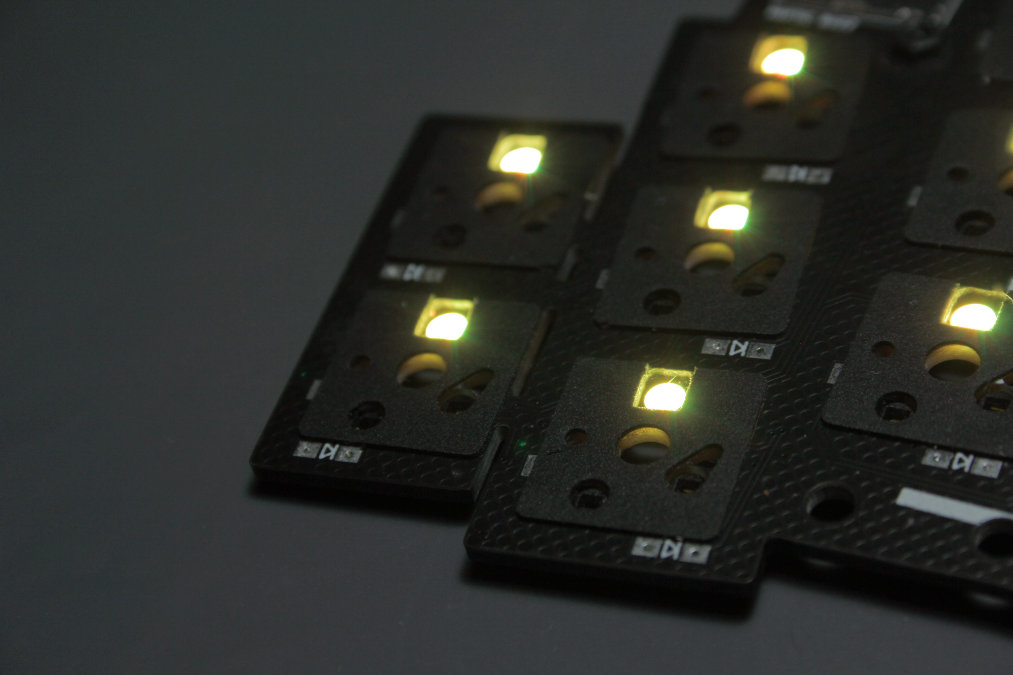
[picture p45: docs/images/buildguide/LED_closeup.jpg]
KLOR LED working


This graphic shows the order in which the LEDs are chained together.

KLOR LED order

***

## DIODES

The diodes need to be soldered on the bottom of the PCB. Pay attention to their orientation:  They have a small line on one side, which should be on the side the arrow on the PCB is facing to.

<p align="center">
<picture>
  <source media="(prefers-color-scheme: dark)" srcset="/docs/images/buildguide/diodes_dark.svg">
  <source media="(prefers-color-scheme: light)" srcset="/docs/images/buildguide/diodes_bright.svg">
  diode orientation
</picture>
</p>

Apply a small amount of solder on one pad.

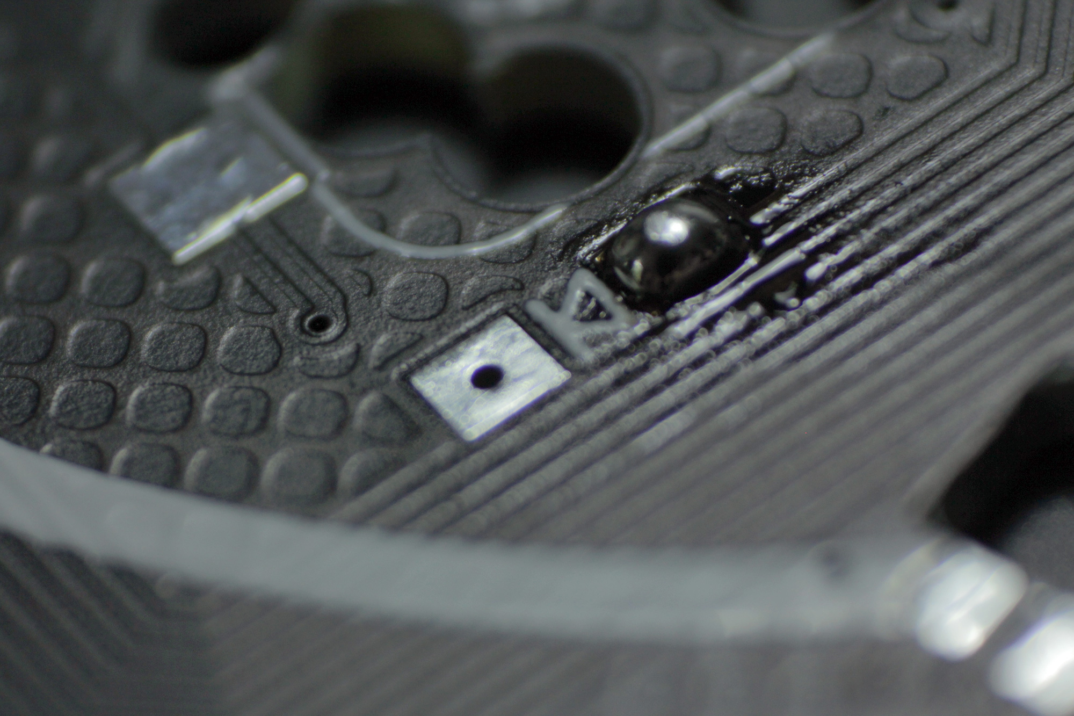
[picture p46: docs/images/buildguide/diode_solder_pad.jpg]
Solder on one pad


Then use tweezers to place the diode on the pads and reheat the solder to secure the diode.

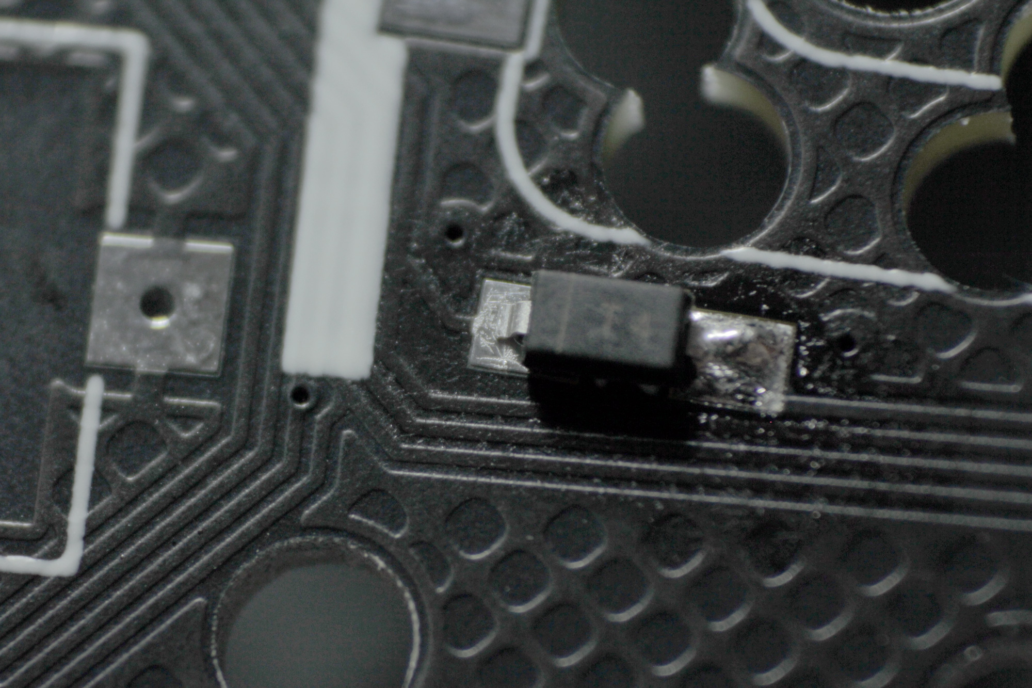
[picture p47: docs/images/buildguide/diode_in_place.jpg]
Solder diode


Now you can solder the second pad.

***

## SWITCH SOCKETS

Here you can apply the same technique as used for the diodes: Apply some solder on one of the pads first.

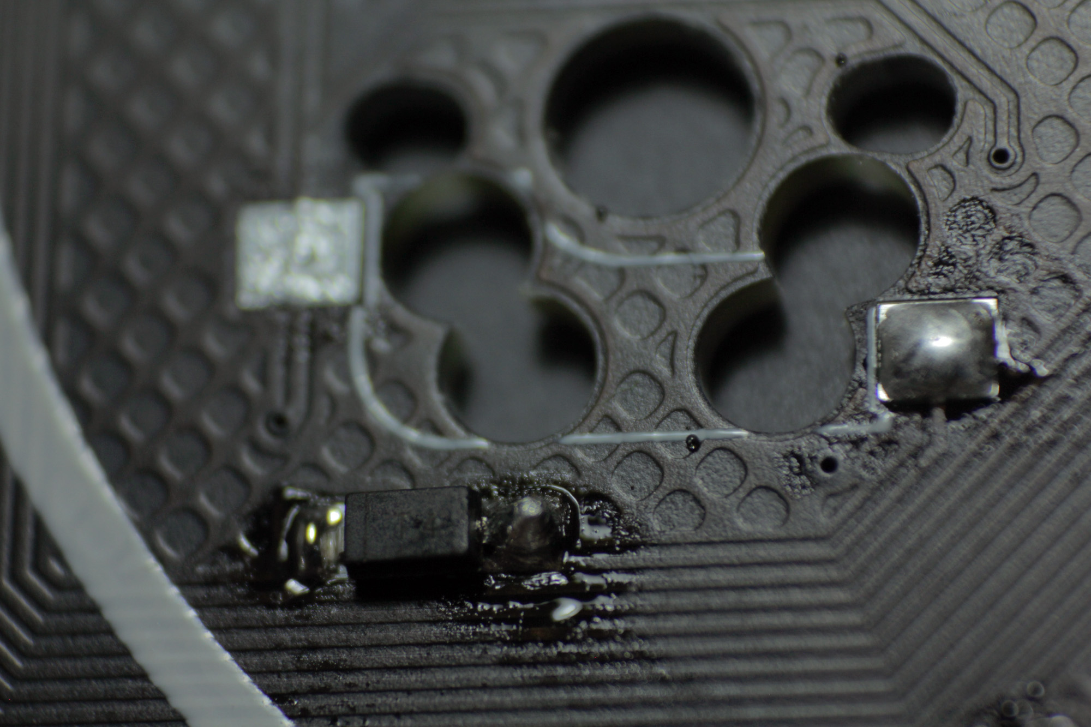
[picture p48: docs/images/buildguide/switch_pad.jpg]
switch sockets pad


Then place the switch socket in the silk screen markings and reheat the solder. Apply some pressure with a pair of tweezers to make sure the socket is fully seated.\
Now solder the second pad.

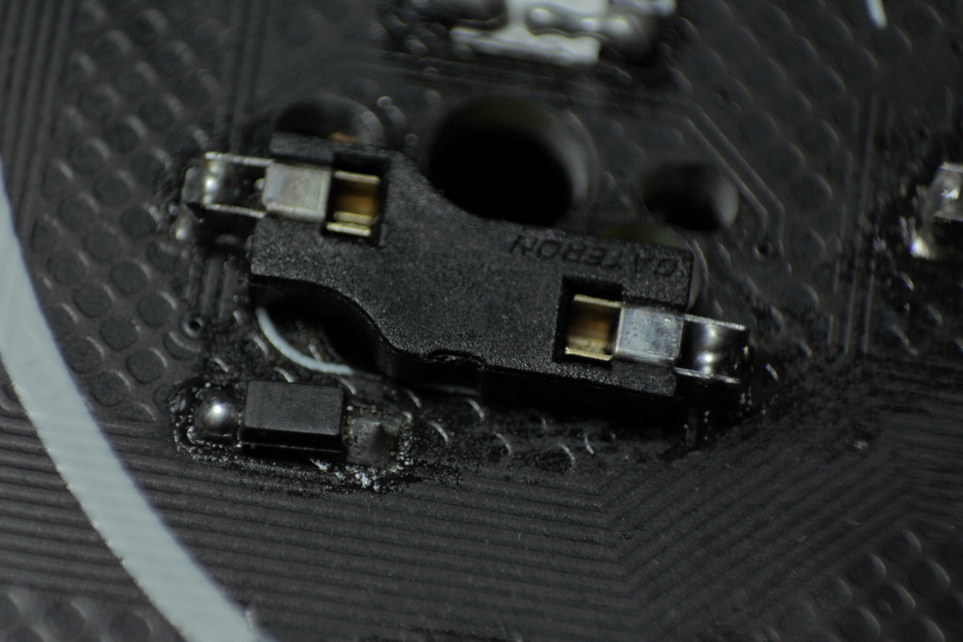
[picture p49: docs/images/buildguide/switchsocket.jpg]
switch socket soldered


***

## RESET SWITCHES

The reset switches are a bit fiddly to solder. It helps to apply a really thin film of solder to the outer pads first. Then hold the switch in place with tweezers and solder the big pads on the left and right of the switch (they do not fulfill any electrical purpose, but serve to hold the switches in place). If the switch is seated correctly flip the PCB and solder the pads in the middle from below.

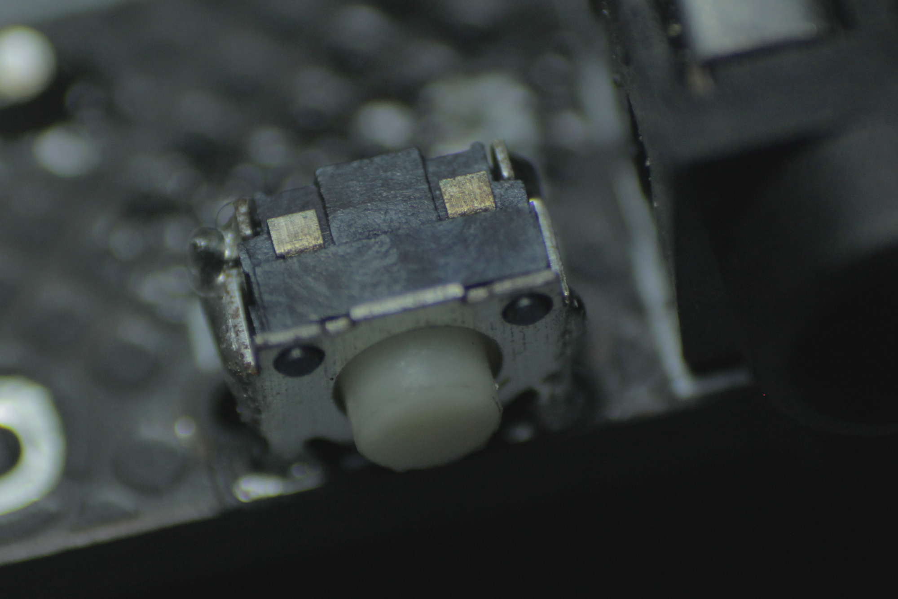
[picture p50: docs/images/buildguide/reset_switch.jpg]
reset switch


***

## TRRS JACKS

Install the TRRS jack on the bottom side of the PCB. The place where you should insert it is marked with a white line.
You may want to use some masking tape to hold it in place since you need to solder it on the bottom.

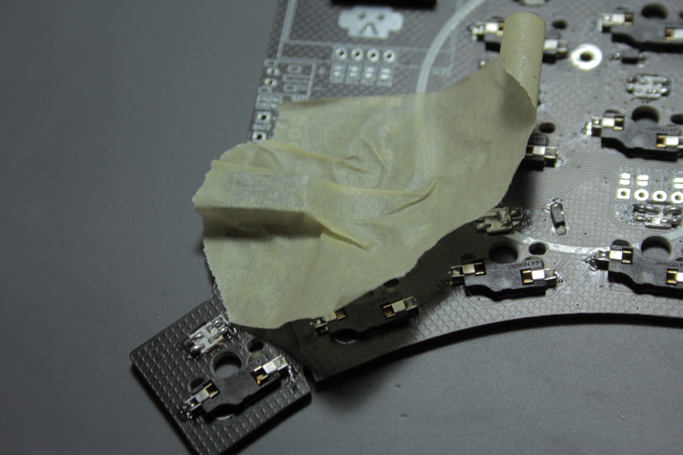
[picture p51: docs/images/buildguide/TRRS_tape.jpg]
TRRS jack taped


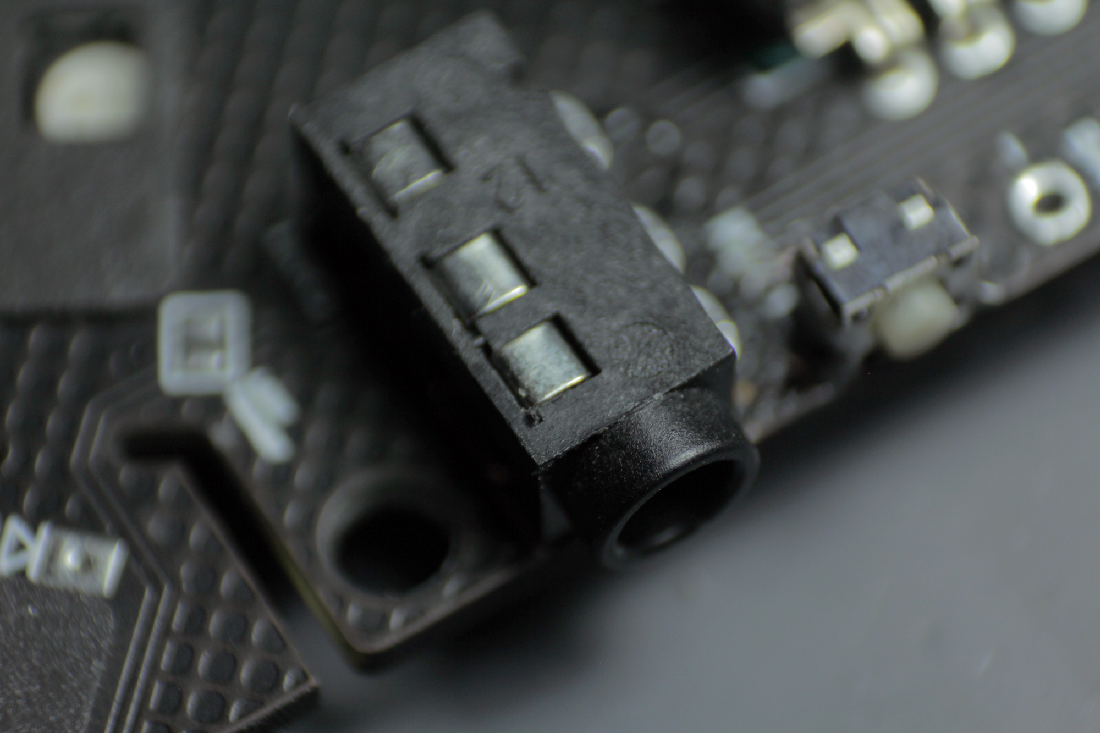
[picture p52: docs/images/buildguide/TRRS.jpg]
TRRS jack soldered


***

## HAPTIC FEEDBACK (optional)

> **Note**
> Currently, haptic feedback only works on the primary side of your keyboard, which is a limitation of QMK.

Apply some solder to the jumpers on the top to bridge them.

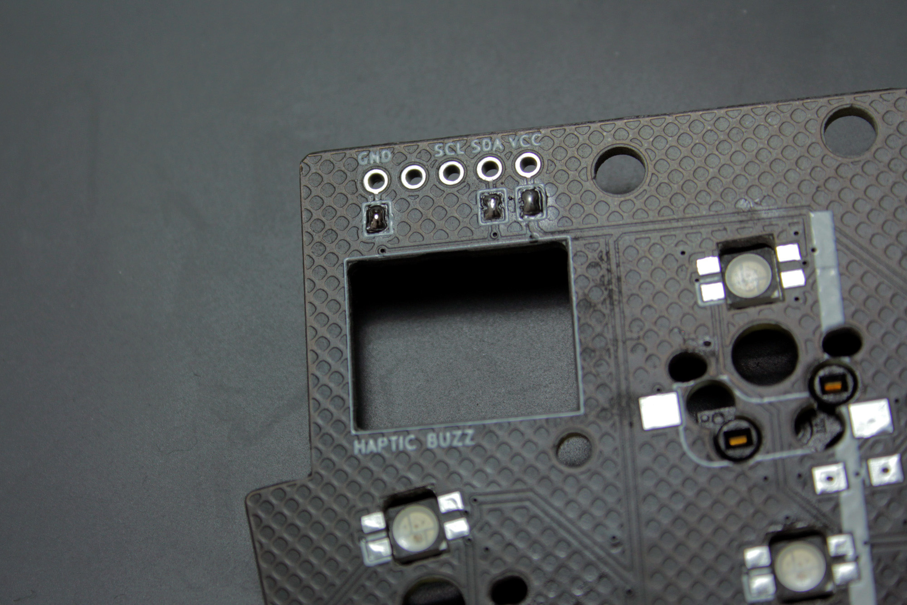
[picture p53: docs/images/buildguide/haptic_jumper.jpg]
haptic feedback Jumper


Insert the module from below with the motor facing upwards. Then insert the pin headers from below.

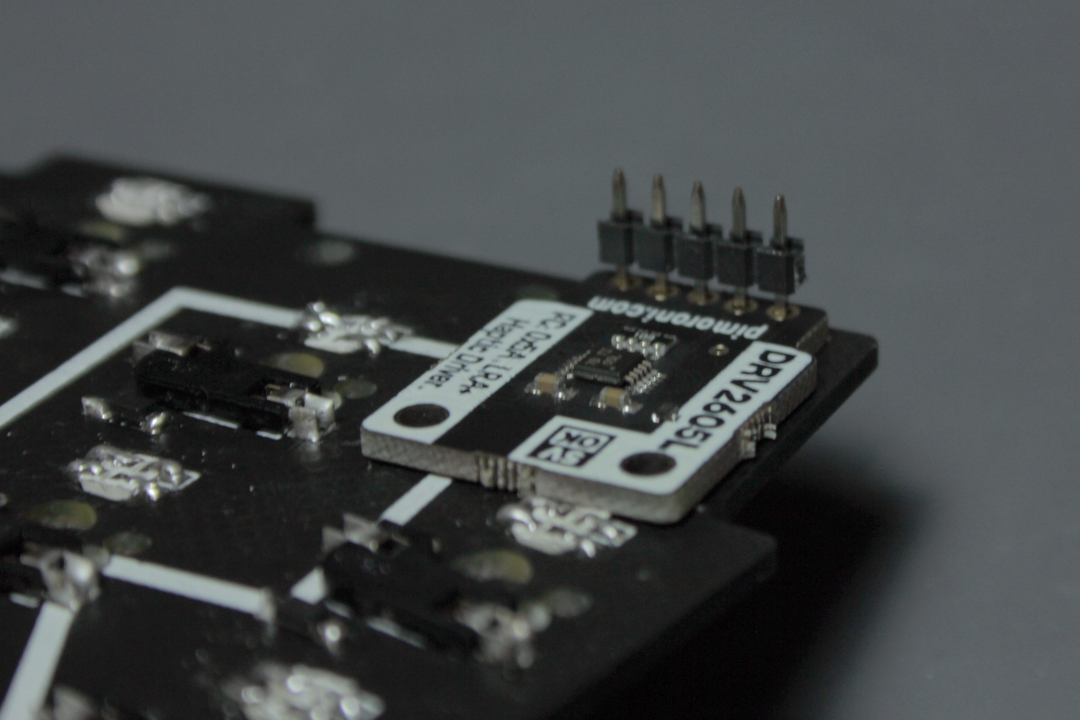
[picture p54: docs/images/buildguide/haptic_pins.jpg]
haptic feedback pins


Now you can solder the pins and use a flush cutter to snap off the excess. Remember to hold your hand above them or wear eye protection while doing so.

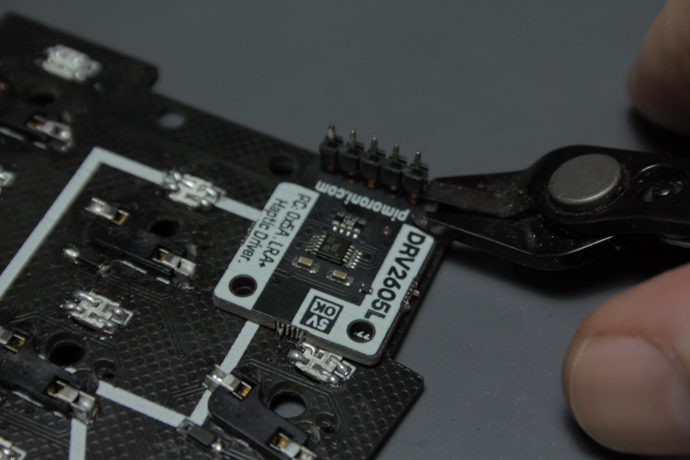
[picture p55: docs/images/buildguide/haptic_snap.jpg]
haptic feedback snap of pins


You can also use a screw and a nut to stabilize the module further. But this step is optional.

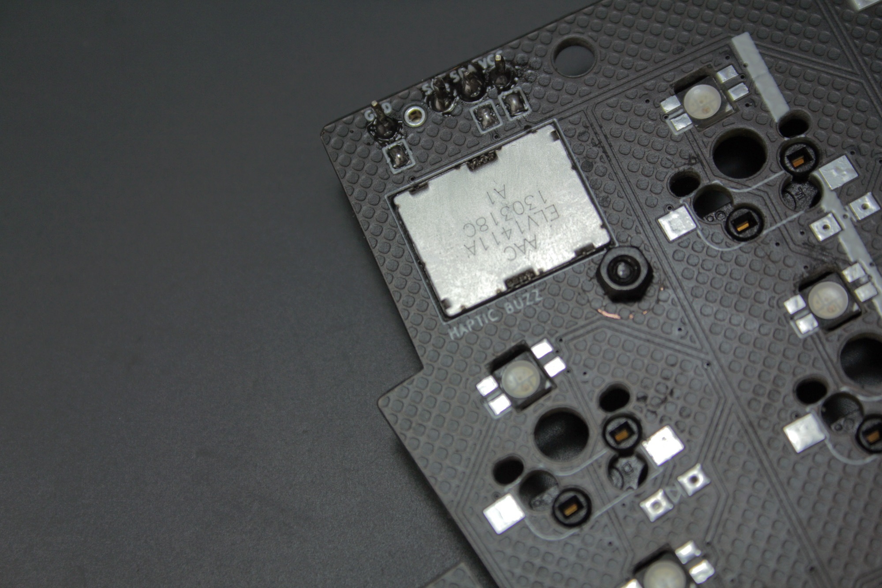
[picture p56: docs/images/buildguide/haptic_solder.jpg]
haptic feedback solder


***

## SPEAKER (optional)

> **Note**
> Currently haptic feedback only works on the primary side of your keyboard, which is a limitation of QMK. Unfortunately, the audio feature of QMK doesn't work yet with the RP2040.

Soldering the speaker is pretty simple. Apply a tiny bit of solder on one of the pads, use tweezers to hold the speaker in place, and reheat the solder. After that apply solder to the other pad.

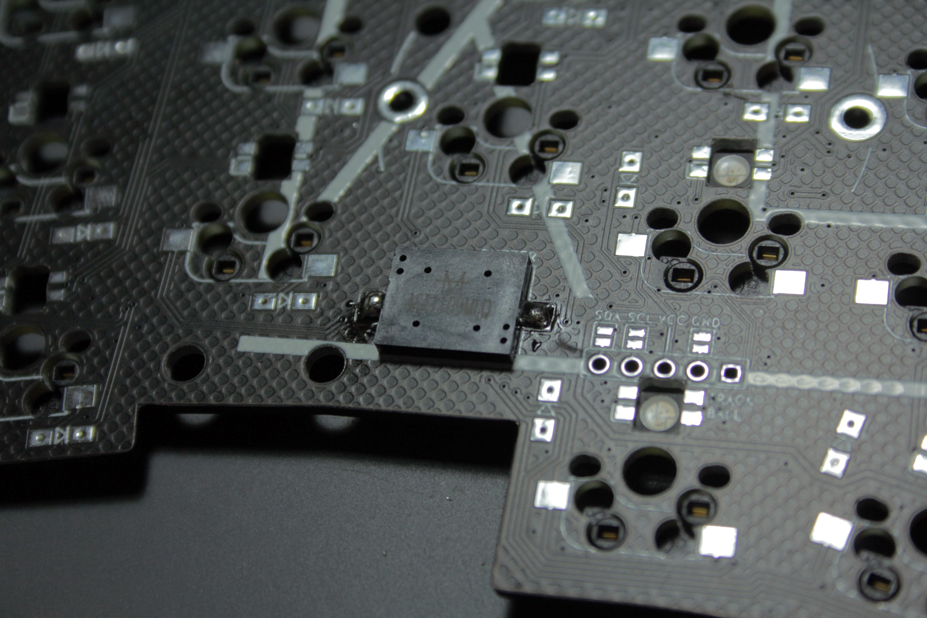
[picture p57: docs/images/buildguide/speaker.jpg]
speaker


***

## TRACKBALL (optional)
> **Note**
> While the hardware side should already work fine, I still need to add the code for the trackball.

TBA

***

## ENCODERS

Mount the rotary encoder on the top side of the PCB. It should click into place maybe requiring a firm press. If it's seated correctly solder the pins on the bottom.

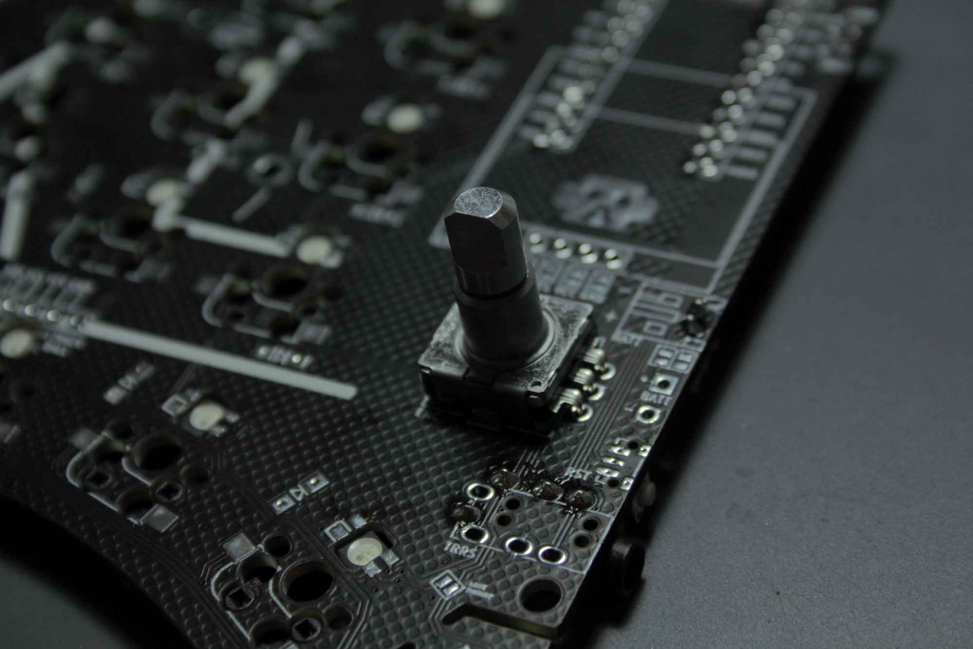
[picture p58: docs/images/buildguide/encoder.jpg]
encoder


***

## OLEDs

> **Warning**
> Make sure the keyboard is fully functional before soldering the OLEDs, since they're the only components that cover pins, you won't be able to access them once they are in place.

The first step should be to bridge the jumpers on the top of the PCB next to the OLED.

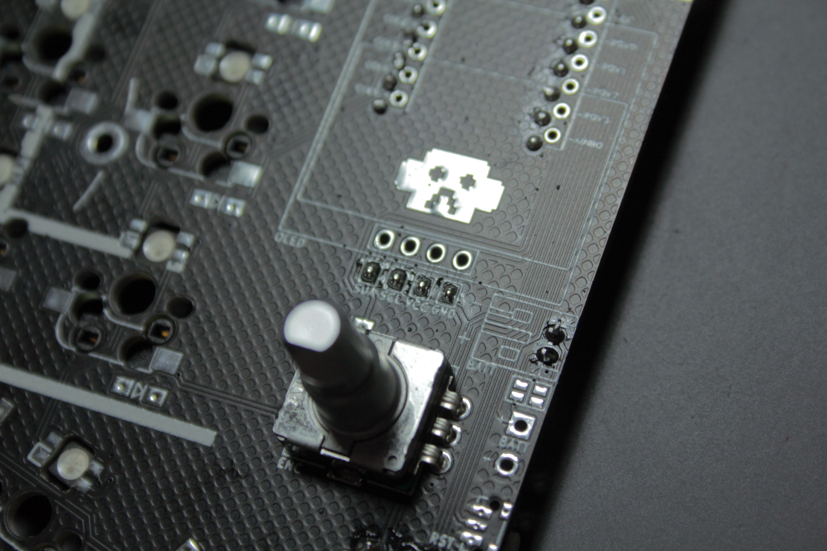
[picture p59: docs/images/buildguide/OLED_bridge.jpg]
OLED bridge jumpers


> **Note**
> The OLED needs to be as flush to the PCB as possible to fit under the switchplate.

You need to remove the plastic part, which is usually attached to the OLED, from the headers, while keeping the pins. For me the easiest way is to use flush cutters to snap the plastic in half, which allows you to remove the parts easily. You probably need to bend the pins back in place after doing this.

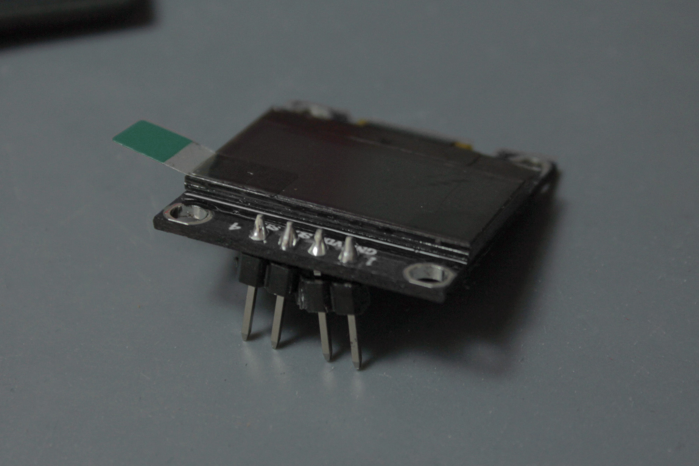
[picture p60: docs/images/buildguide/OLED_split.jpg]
OLED pin split


You also need to cover the back of the OLED with electrical tape, to prevent shorts with the microcontroller pins. Especially the top part with the copper traces is important.

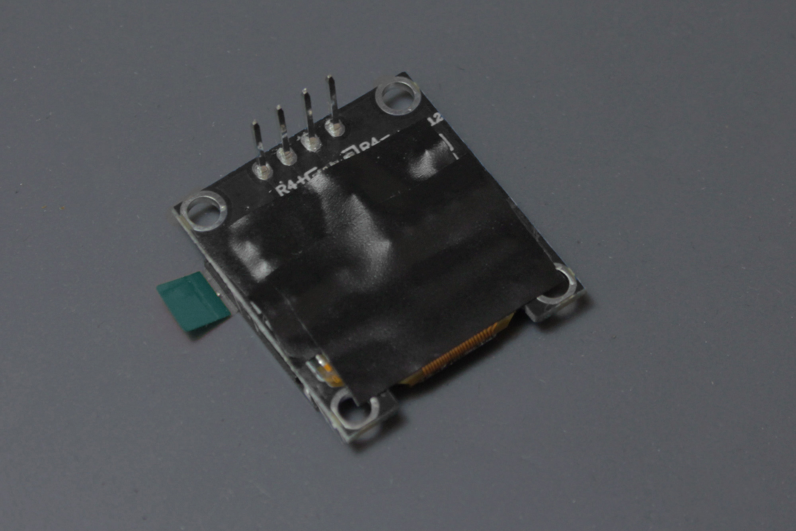
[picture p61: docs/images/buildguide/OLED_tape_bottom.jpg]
OLED tape on bottom


Insert the OLED on the top of the PCB. Make sure it sits as flush with the PCB as possible. Maybe hold it in place with some masking tape.

> **Note**
> You could also temporarily install the switchplate over the OLED, using a few switches. This way you make sure it's exactly in the right spot and rotation.

Solder the OLED into place.

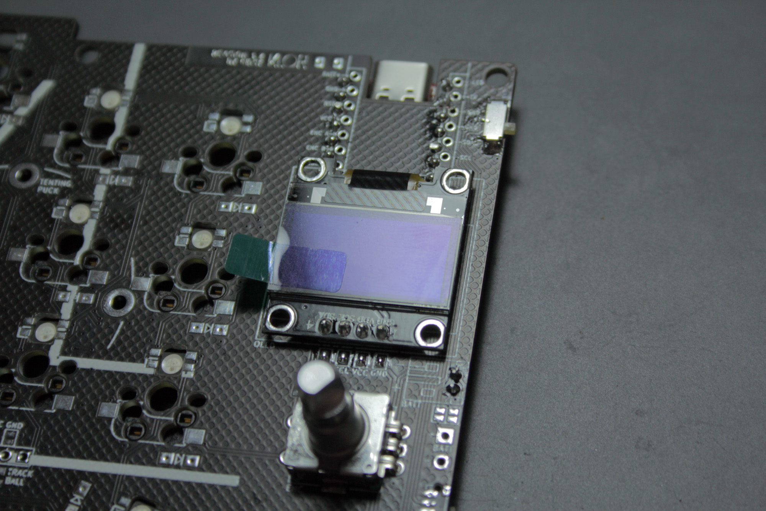
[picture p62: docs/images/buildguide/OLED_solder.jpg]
OLED soldering


Now use flush cutters to trim the top and bottom pins. Especially the top pins should be as short as possible to avoid interference with the switch plate.

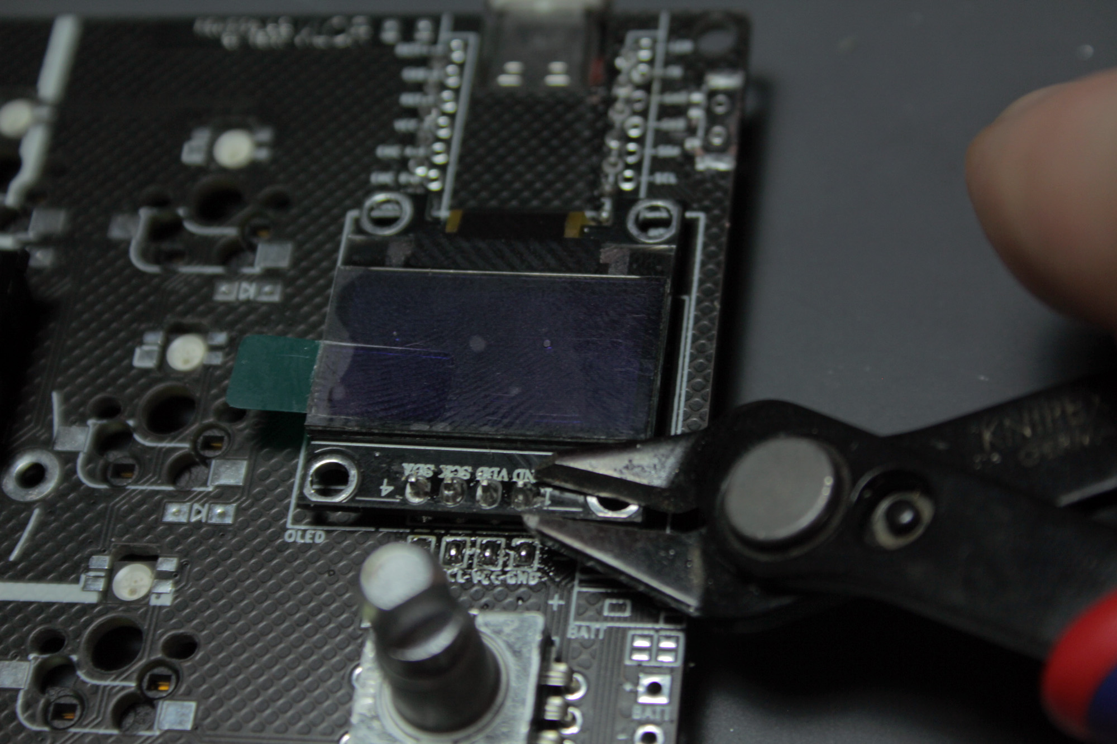
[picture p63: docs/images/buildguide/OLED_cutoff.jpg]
OLED flush cutter


If you use a metal switch plate consider covering them with electrical tape to prevent shorts.

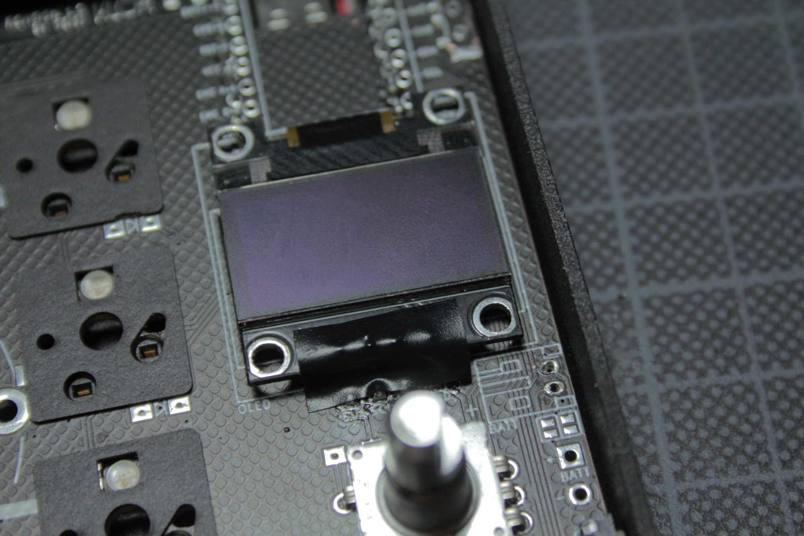
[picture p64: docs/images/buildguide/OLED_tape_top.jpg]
OLED tape on top


> **Note**
> If you need to desolder the OLED or fix its placement just apply a lot of solder to the four pins to connect them. This way you can heat all four pins at once and remove them by gently applying force to the bottom edge of the OLED module. Be really careful not to use too much pressure, since you could rip off a pad or destroy the OLED (which happens pretty fast).

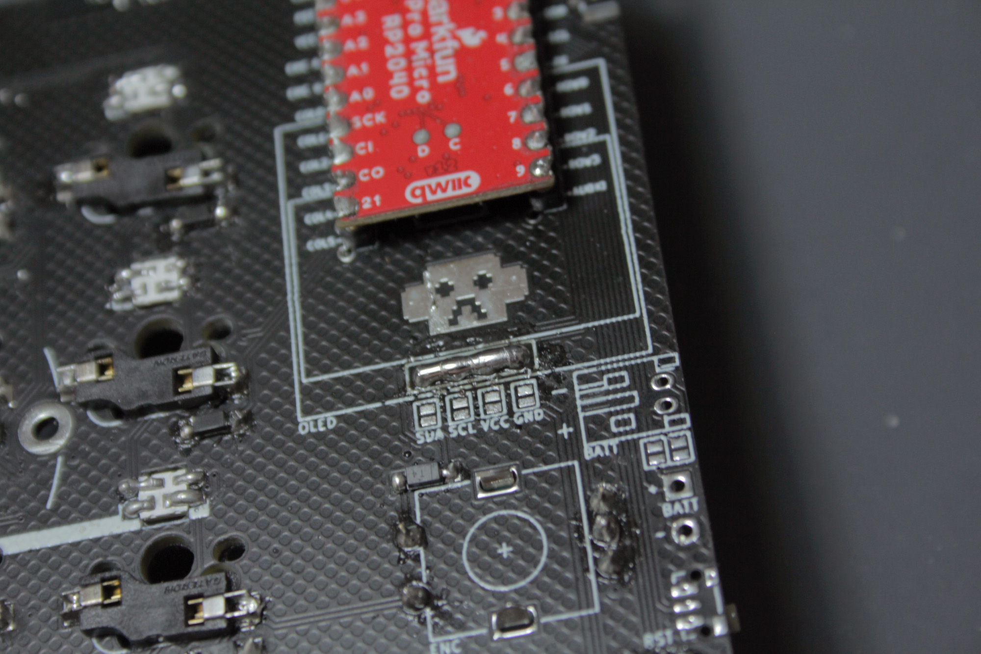
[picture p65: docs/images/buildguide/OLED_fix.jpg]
OLED desolder


***

## CLEANING

This is what your finished PCB probably will look like. You can use an old toothbrush and some isopropanol to clean it from residues. 

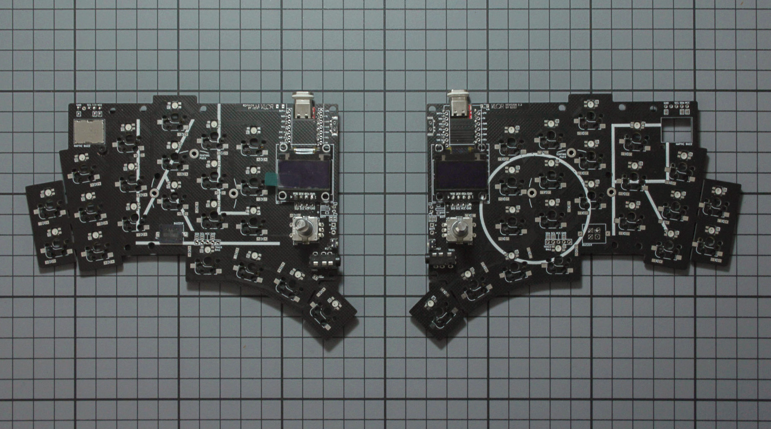
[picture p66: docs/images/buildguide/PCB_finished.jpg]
Finished PCB

***IMAGE***

***

## FIRMWARE

### AVR-based ProMicro 
**e.g. Pro Micro / Elite-C / Puchi-C**

If you have not already flashed the firmware to the microcontroller you should do it now, to make sure everything works, before inserting it into the case.\
[Here](https://github.com/GEIGEIGEIST/qmk-config-klor) you can find the QMK firmware for the KLOR.\
Copy the **klor** folder into the **keyboards** directory of your qmk installation.\
Then use [QMK MSYS](https://msys.qmk.fm/) (or the command line tool of your choice) to compile it with this command:

``qmk compile -kb klor -km default`` 

This will create a file called **klor_default.hex** in your **qmk_firmware** folder.\
Open [QMK Toolbox](https://github.com/qmk/qmk_toolbox) and locate the **klor_default.hex** file.\
Connect the ProMicro/keyboard and press the reset button (or connect the RST and GND pins on the ProMicro). QMK toolbox should show a connected device.\
Press **flash** in QMK toolbox to flash the firmware on your microcontroller.

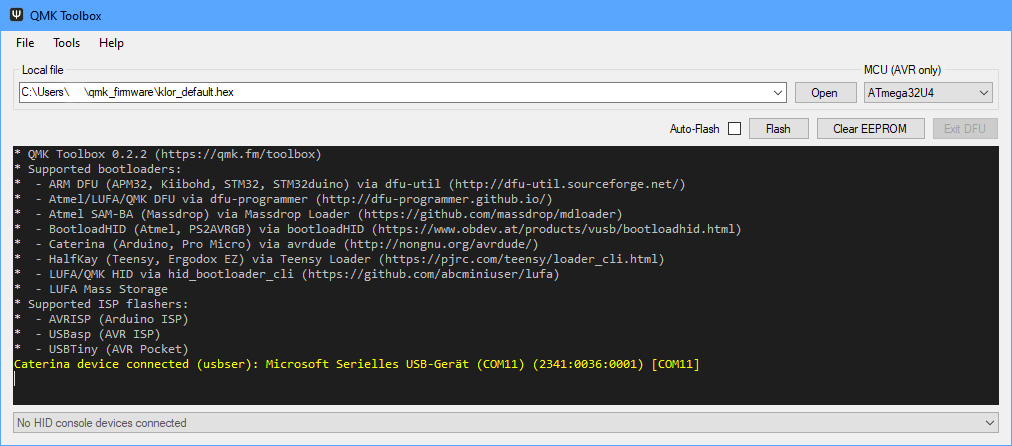
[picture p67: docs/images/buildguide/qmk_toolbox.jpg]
QMK toolbox


### RP2040 ProMicro 
**e.g. Adafruit KB2040 / Sparkfun Pro Micro RP2040 / Boardsource Blok / Elite-Pi / Sea-Picro**

Copy the **klor** folder into the **keyboards** directory of your qmk installation.\
Then use [QMK MSYS](https://msys.qmk.fm/) (or the command line tool of your choice) to compile it with this command:

``qmk compile -kb klor/rp2040 -km default``

This will create a file called **klor_rp2040_default.uf2** in your **qmk_firmware** folder.\
The first time you need to keep boot pressed, then press reset and release boot. This will open the flash memory of your MicroController as a device in your OS.\
Copy the **klor_rp2040_default.uf2** there to flash it. 

> **Note**
> After flashing the firmware the first time you can access the flash memory by double pressing the reset button on your keyboard or define a software reset key by using **QK_boot** as keycode.

***

## STACKED ACRYLIC CASE

> **Note**
> Since there are a lot of different parts please check the 'puzzle guide' which you can find in the same folder as the case files of your layout. 

Screw the standoffs onto the bottom plate. You can find the location of the 7mm standoffs and 9mm standoffs in the 'puzzle guide', but as a rule of thumb, the 9mm standoffs should be on the outside, holding the case parts, while the 7mm standoffs will hold the PCB and switchplate.\
(The dark shapes on the bottom are pieces of deskmat, I use as bumpers.) 

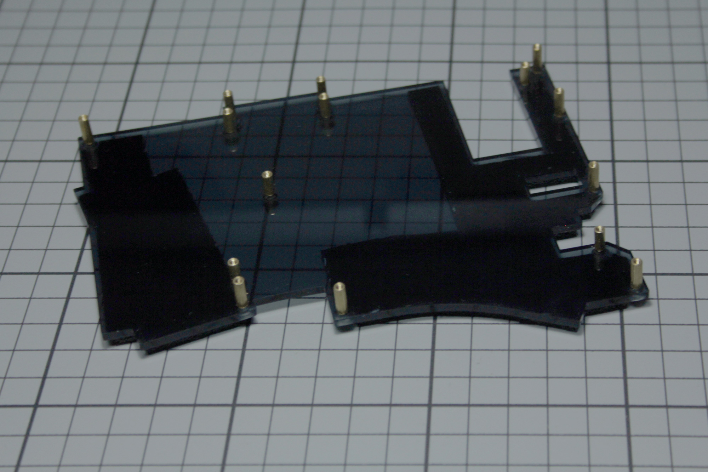
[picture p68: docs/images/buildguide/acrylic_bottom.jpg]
acrylic bottom


Next, you should align the parts of the first layer to the outer standoffs. The parts for the left and right cases are interchangeable.

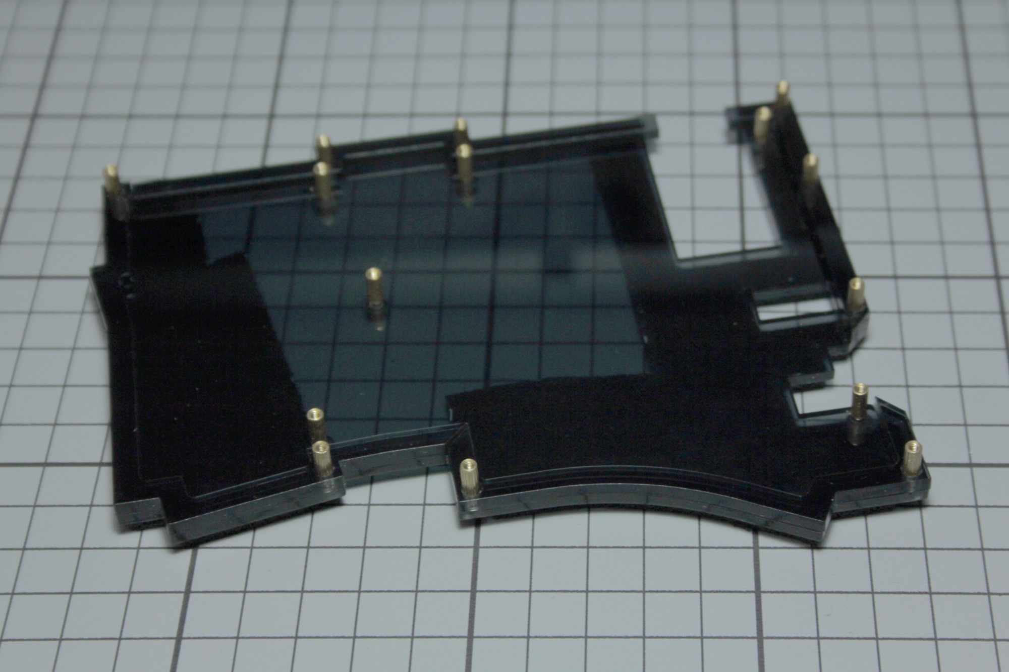
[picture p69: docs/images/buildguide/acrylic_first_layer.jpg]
acrylic first layer


Now you can insert the PCB and add the other layers.

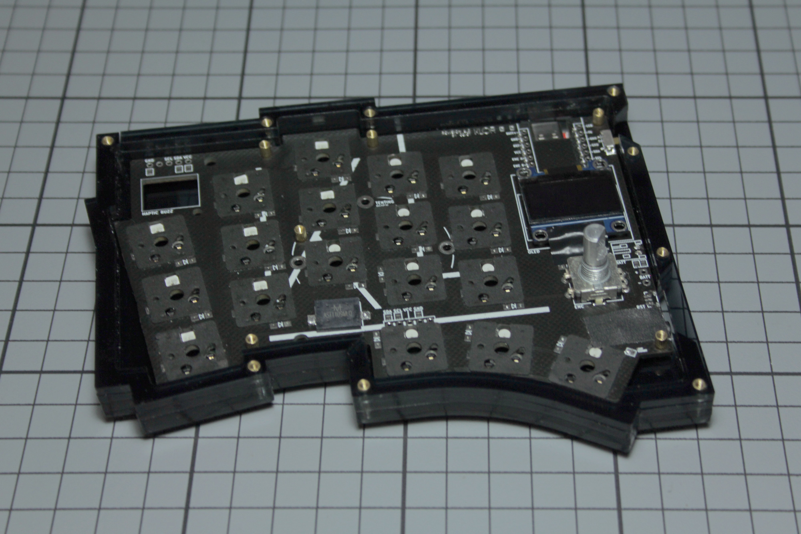
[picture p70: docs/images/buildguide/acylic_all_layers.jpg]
acrylic all layers


 Align the plate and screw them to the center standoffs.

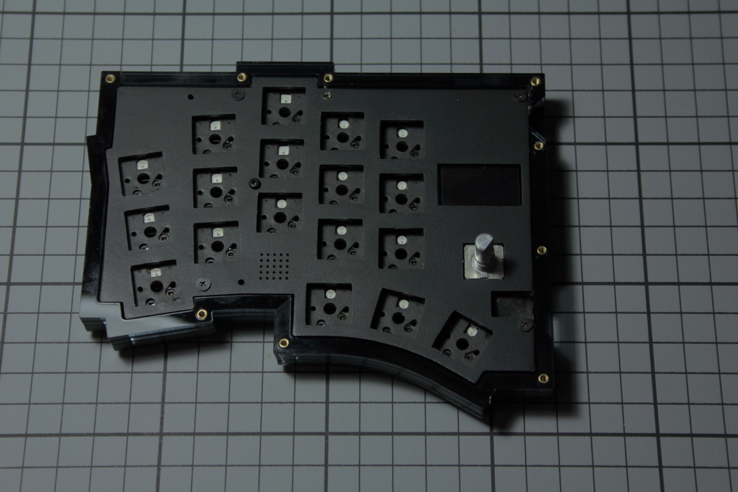
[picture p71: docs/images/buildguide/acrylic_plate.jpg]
acrylic switchplate
 

For this step, you need the 5mm wafer head screws, since other screwheads would intersect with the top layer.

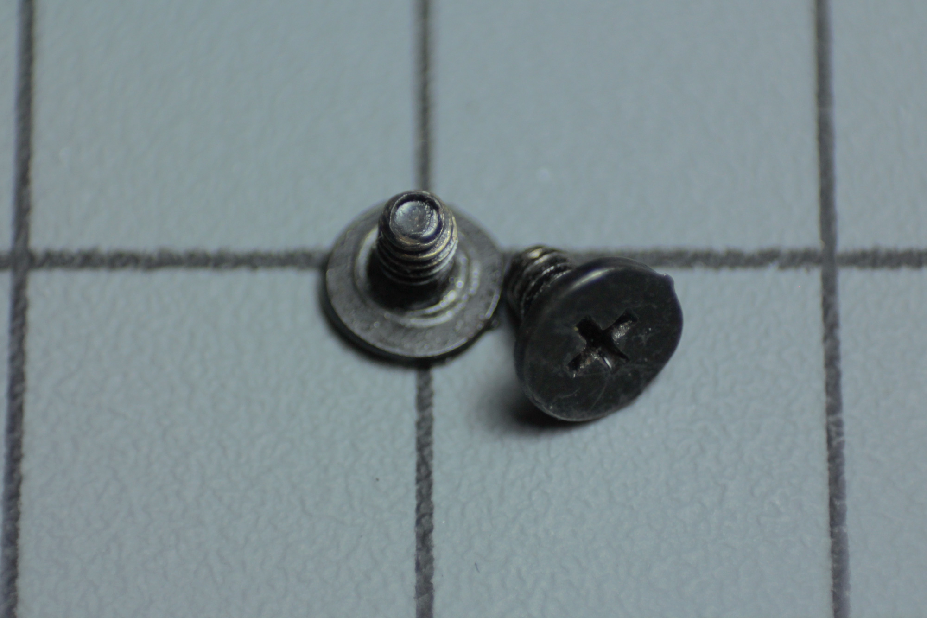
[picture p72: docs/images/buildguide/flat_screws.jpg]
wafer head screws


Finally, attach the top plate and insert the switches into the plate.

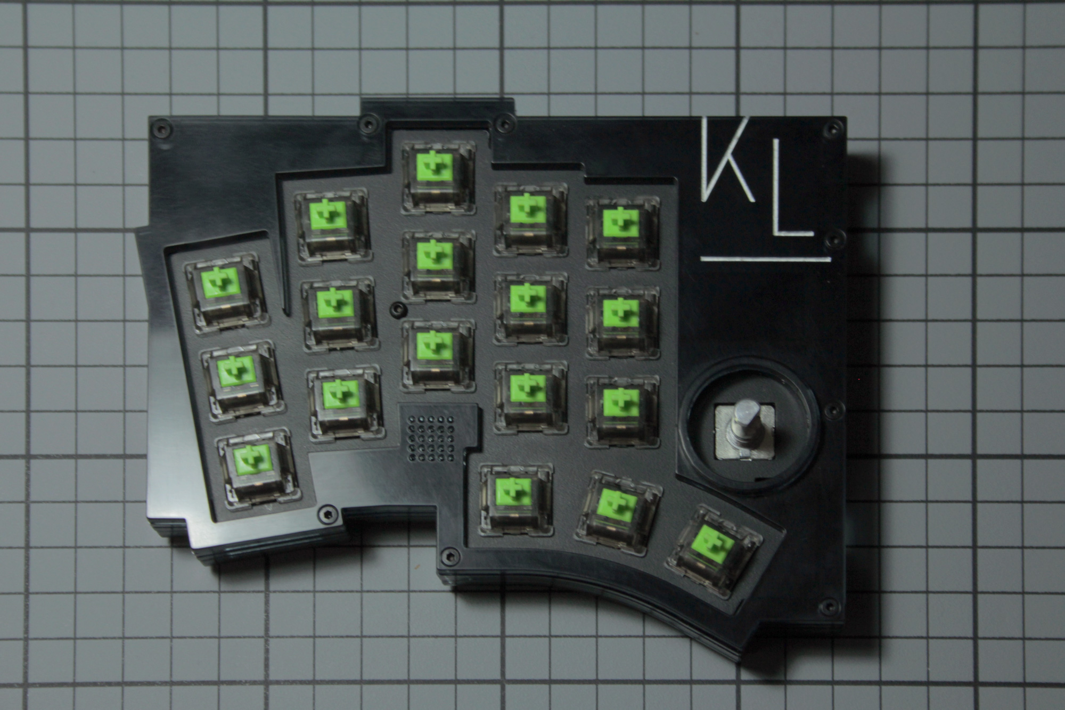
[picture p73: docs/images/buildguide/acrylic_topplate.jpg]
acrylic top plate


***

## KNOBS

The design works best with 23mm (0.9") diameter encoder knobs. My recommendation would be a knob from kilo international with a number beginning with 90 (which means a 0.9" diameter) like the OEDNI-90-4-7 shown here.

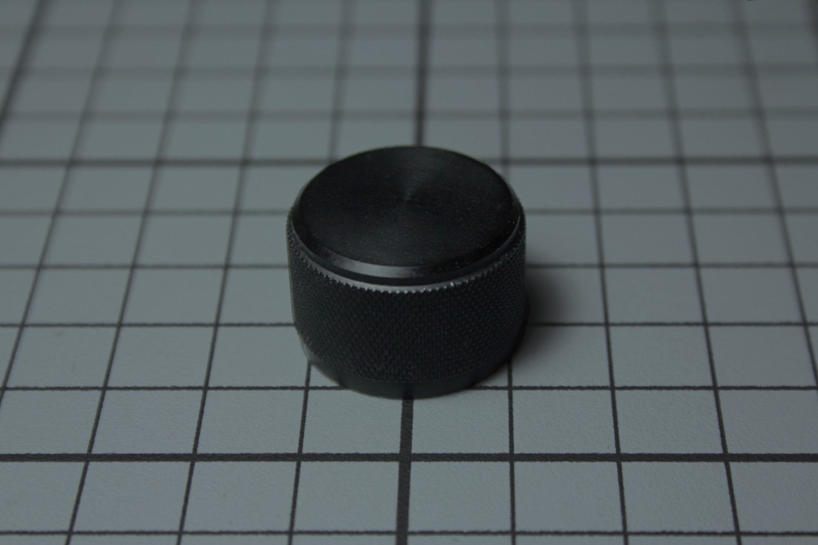
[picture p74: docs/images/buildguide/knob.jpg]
OEDNI-90-4-7


***

## FINAL BUILD

This is how the final keyboard will look like. In this picture you see the KLOR saegewerk, with RAMA Grid keycaps in NOCT.

KLOR acrylic case

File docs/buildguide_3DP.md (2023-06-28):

# KLOR BUILD GUIDE (3DP CASE) [WIP]

## PART LIST

### REQUIRED PARTS

| Part name | Count | Remarks | 
| :--- | :---: | :--- |
| KLOR PCB | 02 | You can find the files for it [here](/PCB/) |
| ProMicro | 02 | Alternatively, you can use another controller with a similar pinout like the Elite-C, Puchi-C, KB2040 dda. |
| MX Key switch | 42 | 40 switches for Konrad / 38 switches for Yubitsume / 36 switches for Saegewerk |
| switch socket | 42 | 40 sockets for Konrad / 38 sockets for Yubitsume / 36 sockets for Saegewerk |
| diodes 1N4148W| 44 | These are surface mount diodes in SOD123 package. 42 for Konrad / 40 for Yubitsume / 38 for Saegewerk |
| 1u MX keycaps | 42 | 40 keycaps for Konrad / 38 keycaps for Yubitsume / 36 keycaps for Saegewerk |
| OLED module | 02 | SSD1306 128x64 pixel OLED Displays |
| reset button  | 02 | Alps SKRTLAE010 |
| TRRS jack | 02 | MJ-4PP-9 or PJ320A |
| TRRS cable | 01 | Alternatively, you can use a TRS cable for [half-duplex](https://github.com/qmk/qmk_firmware/blob/master/docs/serial_driver.md#usart-half-duplex)|
| EC11 encoder  | 02 | You can use any EC11 encoder, but it will look better if you use a short one, like the EC11N1524402 |
| encoder knob  | 02 | The design works best with a 2,2cm encoder knob. I'd recommend kilo international knobs with a number starting with 90. You could also use the [knob](/knob/) I designed for the KLOR, based on the kilo knob. 
| USB cable | 01 | For connecting the keyboard to your PC |

### OPTIONAL PARTS

| Part name | Count | Remarks | 
| :--- | :---: | :--- |
| MCU sockets | 04 | For socketing your MCU. Highly recommended |
| MCU pins | 48 | In combination with the MCU sockets |
| SK6812 Mini LED (not Mini-E) 3535 size | 42 | 40 LEDs for Konrad / 38 LEDs for Yubitsume / 36 LEDs for Saegewerk |
| [Haptic Feedback Module](https://shop.pimoroni.com/products/drv2605l-linear-actuator-haptic-breakout) | 01 | Pimoroni Haptic Buzz |
| speaker | 01 | Mallory AST1109MLTRQ or Keliking KLJ-1102 |
| [trackball](https://bit-trade-one.co.jp/selfmadekb/adtb7m/) | 01 | Pixart PAW3204OA. Available at [Yushakobo](https://shop.yushakobo.jp/products/adtb7m) |
| [level converter](https://github.com/sekigon-gonnoc/LevelConverterForTrackballModule) | 01 | Needed to use the trackball. You can get it from [Yushakobo](https://shop.yushakobo.jp/products/a0800tl-01-1/) |
| [tenting puck](https://splitkb.com/products/tenting-puck)| 02 | SplitKB Tenting Puck |

### 3DP CASE PARTS

| Part name | Count | Remarks | 
| :--- | :---: | :--- |
| 3D printed case | 02 | Find the case files [here](/case/3DP) |
| acrylic parts | 02 | Three parts and one ring per side |
| switch plate | 02 | 1.5mm switch plate |
| 7mm M2 standoffs | 16 | round |
| 6mm M2 screws | 16 | |
| 6mm M2 countersunk screws | 16 | The bottom only supports countersunk screws |

## INTRODUCTION

Here is an overview of where and on which side each component needs to be soldered (click on the image to see a larger version).

KLOR solder guide

To see what component needs to sit where you can take a look at the [interactive HTML BOM](https://htmlpreview.github.io/?https://github.com/GEIGEIGEIST/KLOR/blob/main/docs/klor_rev1-3_ibom.html).

> **Warning**
> This interactive HTML BOM does show where each component is located, but please still refer to the soldering guide above to see if a component needs to go on the top or bottom of the PCB.

Be aware that for the stacked acrylic case some components need to be soldered on the opposite side.\
Some people mark the top and bottom with tape to keep track of which side is which, as the PCB is reversible.\
Begin with the flat components and progress to the higher ones, ending with the OLEDs and the encoders.

***

## BREAK OFF PARTS (optional)

If you choose a layout [other than](/README.md#layouts) Polydactyl you should remove the unnecessary parts. Use a flush cutter to snip through the support sections. You can also use a boxcutter to carve in grooves, which makes it easier to break on the right spot. 

> **Warning**
> Be very careful with this step, since there is a risk to break the PCB. Probably it would be best to begin with this step, to avoid losing already soldered parts.

break off parts

You can use a file to smooth out the edges, but you should wear a mask while doing this since the FR4 dust is considered to be toxic.

***

## MICROCONTROLLER

> **Warning**
> First flash the microcontroller to make sure it works, before soldering it in.

Unlike most other boards here the microcontroller needs to be mounted on the bottom, with the components facing upwards (to the PCB).\
Feel free to use the included header pins, but it's highly recommended to use MillMax low-profile sockets.\
Place the sockets in the marked spots on the bottom side of the PCB.

MCU sockets

You can keep them in place by using masking tape.

sockets taped

Then you can flip the board to solder in the sockets from the top.
Flip it again and insert the pins into the sockets.

> **Note**
> Use tweezers to insert them. Don't apply too much force, you will feel them snap in. After that, you can carefully apply some pressure, using a flat object to make sure they're fully seated. 

MCU pins

Now place your microcontroller on the pins (components facing the PCB) and solder it to them.\
You can use flush cutters to trim the header pins.

MCU solder

> **Warning**
> When trimming with flush cutters wear eye protection or hold your hand close above the pins. Otherwise, sharp metal pins flying around might hurt you.

***

## LEDS (optional)

> **Note**
> If you use a layout with three thumbs, instead of four, you need to bridge the 'lost thumb?' jumper below the TRRS sockets on the primary and secondary PCB, since the led chain lost its beginning. 

Lost thumb jumper

LEDs are very heat sensitive. So it's a good idea to solder the pads on the PCB bottom first and then insert the LED.

LED solder pads

While the bottom of the PCB is facing you, insert the LEDs in the holes. The lens should face the table.

LED in place

This image depicts the correct orientation.\
The L-shaped pad on the LED needs to be connected to the square-marked pad.

LED orientation1

> **Note**
> While the orientation is uniform within a half, it differs between left and right.

> **Warning**
> It's recommended to solder the LEDs in at 220º since they're pretty heat sensitive. Personally, I had a hard time keeping it below 270º. So my advice would be while soldering the first pad on every LED, try to be really quick. Then solder the second pad on every LED, starting with the first LED. This way they can cool down in the meantime.

Make sure the solder always builds a strong connection between the pad on the LED and the pad on the PCB. 

LED connection

The advantage of soldering in the microcontroller first is that you can occasionally check if all the LEDs work before continuing. 

KLOR LED working

This graphic shows the order in which the LEDs are chained together.

KLOR LED order

***

## DIODES

The diodes need to be soldered on the bottom of the PCB. Pay attention to their orientation:  They have a small line on one side, which should be on the side the arrow on the PCB is facing to.

<p align="center">
<picture>
  <source media="(prefers-color-scheme: dark)" srcset="/docs/images/buildguide/diodes_dark.svg">
  <source media="(prefers-color-scheme: light)" srcset="/docs/images/buildguide/diodes_bright.svg">
  diode orientation
</picture>
</p>

Apply a small amount of solder on one pad.

Solder on one pad

Then use tweezers to place the diode on the pads and reheat the solder to secure the diode.

Solder diode

Now you can solder the second pad.

***

## SWITCH SOCKETS

Here you can apply the same technique as used for the diodes: Apply some solder on one of the pads first.

switch sockets pad

Then place the switch socket in the silk screen markings and reheat the solder. Apply some pressure with a pair of tweezers to make sure the socket is fully seated.\
Now solder the second pad.

switch socket soldered

***

## RESET SWITCHES

The reset switches are a bit fiddly to solder. It helps to apply a really thin film of solder to the outer pads first. Then hold the switch in place with tweezers and solder the big pads on the left and right of the switch (they do not fulfill any electrical purpose, but serve to hold the switches in place). If the switch is seated correctly flip the PCB and solder the pads in the middle from below.

reset switch

***

## TRRS JACKS

Install the TRRS jack on the top side of the PCB. The place where you should insert it is marked with a white line.
You may want to use some masking tape to hold it in place since you need to solder it on the bottom.

TRRS jack soldered

***

## HAPTIC FEEDBACK (optional)

> **Note**
> Currently, haptic feedback only works on the primary side of your keyboard, which is a limitation of QMK.

Apply some solder to the jumpers on the top to bridge them.

haptic feedback Jumper

Insert the module from below with the motor facing upwards. Then insert the pin headers from below.

haptic feedback pins

Now you can solder the pins and use a flush cutter to snap off the excess. Remember to hold your hand above them or wear eye protection while doing so.

haptic feedback snap of pins

You can also use a screw and a nut to stabilize the module further. But this step is optional.

haptic feedback solder

***

## SPEAKER (optional)

> **Note**
> Currently the speaker only works on the primary side of your keyboard, which is a limitation of QMK. Currently, you need to use [this PR](https://github.com/qmk/qmk_firmware/pull/17723) to make the audio feature work with the RP2040.

Soldering the speaker is pretty simple. Apply a tiny bit of solder on one of the pads, use tweezers to hold the speaker in place and reheat the solder. After that apply solder to the other pad.

speaker

***

## TRACKBALL (optional)
> **Note**
> While the hardware side should already work fine, I still need to add the code for the trackball.

TBA

***

## ENCODERS

Mount the rotary encoder on the top side of the PCB. It should click into place maybe requiring a firm press. If it's seated correctly solder the pins on the bottom.

encoder

***

## OLEDs

> **Warning**
> Make sure the keyboard is fully functional before soldering the OLEDs, since they're the only components that cover pins, you won't be able to access them once they are in place.

First step should be to bridge the jumpers on the top of the PCB next to the OLED.

OLED bridge jumpers

> **Note**
> The OLED needs to be as flush to the PCB as possible to fit under the switchplate.

You need to remove the plastic part, which is usually attached to the OLED, from the headers, while keeping the pins. For me, the easiest way is to use flush cutters to snap the plastic in half, which allows you to remove the parts easily. You probably need to bend the pins back in place after doing this.

OLED pin split

You also need to cover the back of the OLED with electrical tape, to prevent shorts with the microcontroller pins. Especially the top part with the copper traces is important.

OLED tape on bottom

Insert the OLED on the top of the PCB. Make sure it sits as flush with the PCB as possible. Maybe hold it in place with some masking tape.

> **Note**
> You could also temporarily install the switchplate over the OLED, using a few switches. This way you make sure it's exactly in the right spot and rotation.

Solder the OLED into place.

OLED soldering

Now use flush cutters to trim the top and bottom pins. Especially the top pins should be as short as possible to avoid interference with the switch plate.

OLED flush cutter

If you use a metal switch plate consider covering them with electrical tape to prevent shorts.

OLED tape on top

> **Note**
> If you need to desolder the OLED or fix its placement just apply a lot of solder to the four pins to connect them. This way you can heat all four pins at once and remove it by gently applying force to the bottom edge of the OLED module. Be really careful not to use too much pressure, since you could rip off a pad or destroy the OLED (which happens pretty fast).

OLED desolder

***

## CLEANING

This is what your finished PCB probably will look like. You can use an old toothbrush and some isopropanol to clean it from residues. 

Finished PCB

***

## FIRMWARE

### AVR-based ProMicro 
**e.g. Pro Micro / Elite-C / Puchi-C**

If you have not already flashed the firmware to the microcontroller you should do it now, to make sure everything works, before inserting it into the case.\
[Here](https://github.com/GEIGEIGEIST/qmk-config-klor) you can find the QMK firmware for the KLOR.\
Copy the **klor** folder into the **keyboards** directory of your qmk installation.\
Then use [QMK MSYS](https://msys.qmk.fm/) (or the command line tool of your choice) to compile it with this command:

``qmk compile -kb klor -km default`` 

This will create a file called **klor_default.hex** in your **qmk_firmware** folder.\
Open [QMK Toolbox](https://github.com/qmk/qmk_toolbox) and locate the **klor_default.hex** file.\
Connect the ProMicro/keyboard and press the reset button (or connect the RST and GND pins on the ProMicro). QMK toolbox should show a connected device.\
Press **flash** in QMK toolbox to flash the firmware on your microcontroller.

QMK toolbox

### RP2040 ProMicro 
**e.g. Adafruit KB2040 / Sparkfun Pro Micro RP2040 / Boardsource Blok / Elite-Pi / Sea-Picro**

Copy the **klor** folder into the **keyboards** directory of your qmk installation.\
Then use [QMK MSYS](https://msys.qmk.fm/) (or the command line tool of your choice) to compile it with this command:

``qmk compile -kb klor/rp2040 -km default``

This will create a file called **klor_rp2040_default.uf2** in your **qmk_firmware** folder.\
The first time you need to keep boot pressed, then press reset and release boot. This will open the flash memory of your MicroController as a device in your OS.\
Copy the **klor_rp2040_default.uf2** there to flash it. 

> **Note**
> After flashing the firmware the first time you can access the flash memory by double pressing the reset button on your keyboard or define a software reset key by using **QK_boot** as keycode.

***

## 3DP CASE

Here you can find the STL files for the case. I got them printed in PA12-HP Nylon (Multi Jet Fusion printing) by [JLCPCB](https://jlcpcb.com/3d-printing), which seemed pretty reasonably priced, for the level of detail.

3DP case

Insert the PCB first. Starting with inserting the microcontroller in the cutout at the top.

3DP case insert MCU

Then lower it into the case. To make it fit, you probably need to bend a bit the part of the case containing the holes for reset switch and TRRS jack.

3DP case bend

The TRRS jack should snap in the provided hole.

3DP case trrs

Insert the standoffs in the PCB and screw them into the bottom of the case using the countersunk screws.

3DP case standoffs

Now you can insert the plate and screw it to the case using the center standoff. 

3DP case plate

***

## ACRYLIC PARTS

Here you can find the files for the acrylic parts. Made from smokey acrylic (by a laser cutting service) it will hide the OLED, while still allowing it  to shine through the top layer. It will look best if you can get a pretty dark type, like 7C83 by PlexiGlas (used by formulor.de for example).\
If you want to get rid of the shine you can carefully sand the parts with some really fine sanding paper (I used a 2000 sanding pad).\
You need to glue the ring to the top right part using acrylic glue (Acrifix for example). Be careful to apply only a really thin layer using a toothpick.\
If you choose a case with the KLOR logotype you can emphasize it by retracing it with some sort of white paint marker. Use turpentine or something similar to get rid of the excess paint.

Screw the acrylic parts on top of the plate.

acrylic parts on top of plate

***

## KNOBS

The design works best with 23mm (0.9") diameter encoder knobs. My recommendation would be a knob from kilo international with a number beginning with 90 (which means a 0.9" diameter) like the OEDNI-90-4-7 shown here.

OEDNI-90-4-7

***

## FINAL BUILD

This is how the final keyboard will look like. In this picture, I use RAMA Grid keycaps in NOCT.

final KLOR build

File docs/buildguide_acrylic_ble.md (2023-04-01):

# KLOR BUILD GUIDE (STACKED ACRYLIC CASE BLE) [WIP]

## PART LIST

### REQUIRED PARTS

| Part name | Count | Remarks | 
| :--- | :---: | :--- |
| KLOR PCB | 02 | You can find the files for it [here](/PCB/) |
| Nice!Nano | 02 | Alternatively, you can use another controller with similar pinout and bluetooth capabilities like the Puchi-BLE |
| MX Key switch | 42 | 40 switches for Konrad / 38 switches for Yubitsume / 36 switches for Saegewerk |
| switch socket | 42 | 40 sockets for Konrad / 38 sockets for Yubitsume / 36 sockets for Saegewerk |
| diodes 1N4148W| 44 | These are surface mount diodes in SOD123 package. 42 for Konrad / 40 for Yubitsume / 38 for Saegewerk |
| 1u MX keycaps | 42 | 40 keycaps for Konrad / 38 keycaps for Yubitsume / 36 keycaps for Saegewerk |
| OLED module | 02 | SSD1306 128x64 pixel OLED Displays |
| reset button  | 02 | Alps SKRTLAE010 |
| power switch  | 02 | MSK12C02 |
| EC11 encoder  | 02 | You can use any EC11 encoder, but it will look better if you use a short one, like the EC11N1524402 |
| encoder knob  | 02 | The design works best with a 2,2cm encoder knob. I'd recommend kilo international knobs with a number starting with 90. You could also use the [knob](/knob/) I designed for the KLOR, based on the kilo knob. 
| Lipo battery  | 02 | 
| USB cable | 01 | For connecting the keyboard with your PC |

### OPTIONAL PARTS

| Part name | Count | Remarks | 
| :--- | :---: | :--- |
| MCU sockets | 04 | For socketing your MCU. Highly recommended |
| MCU pins | 48 | In combinatin with the MCU sockets |
| JST Jack | 02 | JST PH |
| SK6812 Mini LED (not Mini-E) 3535 size | 42 | 40 LEDs for Konrad / 38 LEDs for Yubitsume / 36 LEDs for Saegewerk |
| TRRS jack | 02 | MJ-4PP-9 or PJ320A You can add TRRS jacks, so you can swap out the Microcontroller to make it a wired board |
| TRRS cable | 01 | See TRRS jack |
| [trackball](https://bit-trade-one.co.jp/selfmadekb/adtb7m/) | 01 | Pixart PAW3204OA. Available at [Yushakobo](https://shop.yushakobo.jp/products/adtb7m) |
| [level converter](https://github.com/sekigon-gonnoc/LevelConverterForTrackballModule) | 01 | Needed to use the trackball. You can get it from [Yushakobo](https://shop.yushakobo.jp/products/a0800tl-01-1/) |
| [tenting puck](https://splitkb.com/products/tenting-puck)| 02 | SplitKB Tenting Puck |

### ACRYLIC CASE PARTS

| Part name | Count | Remarks | 
| :--- | :---: | :--- |
| acrylic parts | 02 | Find the case files [here](/case/acrylic/) |
| switch plate | 02 | 1.5mm switch plate |
| 9mm M2 standoffs | 22 | Up to 22 9mm round standoffs for the actual case (check the appropiate puzzleguide) |
| 7mm M2 standoffs | 12 | 7mm round standoffs for holding the PCB in place |
| 6mm M2 screws | 56 | Up to 56 regular 6mm M2 screws (check the appropiate puzzleguide) |
| 5mm M2 wafer head screws | 12 | These screws need a flat head to fit under the acrylic top layer |

## INTRODUCTION

Here is an overview of where and on which side each component needs to be soldered (click on the image to see a larger version).

KLOR solder guide

To see what component needs to sit where you can take a look at the [interactive HTML BOM](https://htmlpreview.github.io/?https://github.com/GEIGEIGEIST/KLOR/blob/main/docs/klor_rev1-3_ibom.html).

> **Warning**
> This interactive HTML BOM does show where each component is located, but please still refer to the solder guide above to see if a component needs to go on the top or bottom of the PCB.

Be aware that for the 3D printed case some components need to be soldered on the opposite side.\
Some people mark the top and bottom with tape to keep track of which side is which, as the PCB is reversible.\
Beginn with the flat components and progress to the higher ones, ending with the OLEDs and the encoders.

***

## BREAK OFF PARTS (optional)

If you choose a layout [other than](/README.md#layouts) Polydactyl you should remove the unnecessary parts. Use a flush cutter to snip through the support sections. You can also use a boxcutter to carve in grooves, which makes it easier to break on the right spot. 

> **Warning**
> Be very careful with this step, since there is a risk to break the PCB. Probably it would be best to beginn with this step, to avoid loosing already soldered parts.

break off parts

You can use a file to smooth out the edges, but you should wear a mask while doing this, since the FR4 dust is considered to be toxic.

***

## MICROCONTROLLER

> **Warning**
> First flash the microcontroller to make sure it works, before soldering it in.

Unlike most other boards here the microcontroller needs to be mounted on the bottom, with the components facing upwards (to the PCB).\
Feel free to use the included header pins, but it's highly recommended to use MillMax low profile sockets.\
Place the sockets in the marked spots on the bottom side of the PCB.

MCU sockets

You can keep them in place by using masking tape.

sockets taped

Then you can flip the board to solder in the sockets from the top.
Flip it again and insert the pins into the sockets.

> **Note**
> Use tweezers to insert them. Don't apply too much force, you will feel them snap in. After that, you can carefully apply some pressure, using a flat object to make sure they're fully seated. 

MCU pins

Now place your microcontroller on the pins (components facing the PCB) and solder it to them.\
You can use flush cutters to trim the header pins.

MCU solder

> **Warning**
> When trimming with flush cutters wear eye protection or hold your hand close above the pins. Otherwise sharp metal pins flying around might hurt you.

***

## LEDS (optional)

> **Note**
> If you use a layout with three thumbs, instead of four, you need to bridge the 'lost thumb?' jumper below the TRRS sockets on the primary and secondary PCB, since the led chain lost its beginning. 

Lost thumb jumper

LEDs are very heat sensitive. So it's a good idea to solder the pads on the PCB bottom first and then insert the LED.

LED solder pads

While the bottom of the PCB is facing you, insert the LEDs in the holes. The lens should face the table.

LED in place

This image depicts the correct orientation.\
The L shaped pad on the LED need to be connected to the square marked pad.

LED orientation1

> **Note**
> While the orientation is uniform within a half, it differs between left and right.

> **Warning**
> It's recommended to solder the LEDs in at 220º, since they're pretty heat sensitive. Personally, I had a hard time keeping it below 270º. So my advice would be while soldering the first pad on every LED, try to be really quick. Then solder the second pad on every LED, starting with the first LED. This way they can cool down in the meantime.

Make sure the solder always builds a strong connection between the pad on the LED and the pad on the PCB. 

LED connection

The advantage of soldering in the microcontroller first is that you can occasionally check if all the LEDs work before continuing. 

KLOR LED working

This graphic shows the order in which the LEDs are chained together.

KLOR LED order

> **Note**
> While it's possible to use LEDs in a BLE board be aware that this will hugely decrease your battery life. 

***

## DIODES

The diodes needs to be soldered on the bottomm of the PCB. Pay attention to their orientation:  They have a small line on one side, which should be on the side the arrow on the PCB is facing to.

<p align="center">
<picture>
  <source media="(prefers-color-scheme: dark)" srcset="/docs/images/buildguide/diodes_dark.svg">
  <source media="(prefers-color-scheme: light)" srcset="/docs/images/buildguide/diodes_bright.svg">
  diode orientation
</picture>
</p>

Apply a small amount of solder on one pad.

Solder on one pad

Then use tweezers to place the diode on the pads and reheat the solder to secure the diode.

Solder diode

Now you can solder the second pad.

***

## SWITCH SOCKETS

Here you can apply the same technique as used for the diodes: Apply some solder on one of the pads first.

switch sockets pad

Then place the switch socket in the silk screen markings and reheat the solder. Apply some pressure with a pair of tweezers to make sure the socket is fully seated.\
Now solder the second pad.

switch socket soldered

***

## POWER SWITCHES

Apply a tiny bit of solder on one of the bigger, outer pads on top of the PCB. The power switch has some tiny knobs on its bottom, which fits into the PCB holes. Hold it in place with tweezers and than reheat the solder on the pad. After this you can solder the other pad and the three pins.

power switch

***

## JST JACKS (optional)

Insert the legs of the JST jack into the bottom of the PCB with the open side facing inwards

JST jack

Now use some masking tape to keep it in place, since you need to solder it from the top.

JST tape

You also need to bridge the jumpers next to the connector to make it work.

JST brigded jumpers

> **Note**
> While it's easier to swap out batteries if they already got a JST-PH connector you can also solder the battery to the **+ RED** and **- BLACK** pinholes. This way you don't need to bridge the jumpers.

battery connector

***

## RESET SWITCHES

The reset switches are a bit fiddly to solder. It helps to apply a really thin film of solder to the outer pads first. Then hold the switch in place with tweezers and solder the big pads on the left and right of the switch (they do not fulfill any electrical purpose, but serve to hold the switches in place). If the switch is seated corretly flip the PCB and solder the pads in the middle from below.

reset switch

***

## TRRS JACKS (optional)

> **Warning**
> You don't need the TRRS jacks for running the KLOR with ZMK. Actually you can damage your board when connecting it through TRRS, while also connected to a battery.

Install the TRRS jack on the bottom side of the PCB. The place where you should insert it is marked with a white line.
You may want to use some masking tape to hold it in place, since you need to solder it on the bottom.

TRRS jack taped

TRRS jack soldered

***

## TRACKBALL (optional)

> **Note**
> While the hardware side should already work fine, I still need to add the code for the trackball.

TBA

***

## ENCODERS

> **Note**
> Currently ZMK only supports encoders on the primary side of split keyboards. 

Mount the rotary encoder on the top side of the PCB. It should click into place maybe requiring a firm press. If it's seated correctly solder the pins on the bottom.

encoder

***

## OLEDs

> **Warning**
> Make sure the keyboard is fully functional before soldering the OLEDs, since they're the only components which cover pins, you won't be able to access once they are in place.

First step should be to bridge the jumpers on the top of the PCB next to the OLED.

OLED bridge jumpers

> **Note**
> The OLED needs to be as flush to the PCB as possible to fit under the switchplate.

You need to remove the plastic part, which is usually attached to the OLED, from the headers, while keeping the pins. For me the easiest way is to use flush cutters to snap the plastic in half, which allows you to remove the parts easily. You probably need to bend the pins back in place after doing this.

OLED pin split

You also need to cover the back of the OLED with electrical tape, to prevent shorts with the microcontroller pins. Especially the top part with the copper traces is important.

OLED tape on bottom

Insert the OLED on the top of the PCB. Make sure it sits as flush to the PCB as possible. Maybe hold it in place with some masking tape.

> **Note**
> You could also temporarily install the switchplate over the OLED, using a few switches. This way you make sure it's exactly in the right spot and rotation.

Solder the OLED into place.

OLED soldering

Now use flush cutters to trim the top and bottom pins. Especially the top pins should be as short as possible to avoid interference with the switch plate.

OLED flush cutter

If you use a metal switch plate consider to cover them with electrical tape to prevent shorts.

OLED tape on top

> **Note**
> If you need to desolder the OLED or fix its placement just apply a lot of solder to the four pins to connect them. This way you can heat all four pins at once and remove it by gently applying force to the bottom edge of the OLED module. Be really carefull not to use too much pressure, since you could rip off a pad or destroy the OLED (which happens pretty fast).

OLED desolder

***

## CLEANING

This is how your finished PCB probably will look like. You can use an old toothbrush and some isopropanol to clean it from residues. 

Finished PCB

***

## FIRMWARE

If you have not already flashed the firmware to the microcontroller you should do it now, to make sure everything works, before inserting it into the case.\
[Here](https://github.com/GEIGEIGEIST/zmk-config-klor) you can find the ZMK firmware for the KLOR.\
You need to create an own fork of it. In this fork you can edit the keymap to trigger an Github action, which will create your firmware. 

***

## STACKED ACRYLIC CASE

> **Note**
> Since there are a lot of different parts please check the 'puzzle guide' which you can find in the same folder than the case files of your layout. 

Screw the standoffs onto the bottom plate. You can find the locastion of the 7mm standoffs and 9mm standoffs in the 'puzzle guide', but as a rule of thumb the 9mm standoffs should be on the outside, holding the case parts, while the 7mm standoffs will hold the PCB and switchplate.\
(The dark shapes on the bottom are pieces of deskmat, I use as bumpers.) 

acrylic bottom

Next you should align the parts of the first layer to the outer standoffs. The parts for the left and right case are interchangeable.

acrylic first layer

Now you can insert the PCB and add the other layers.

acrylic all layers

 Align the plate and screw them to the center standoffs.

 acrylic switchplate

For this step you need the 5mm wafer head screws, since other screwheads would intersect with the top layer.

wafer head screws

Finally attach the top plate and insert the switches into the plate.

acrylic top plate

***

## KNOBS

The design works best with 23mm (0.9") diameter encoder knobs. My recomendation would be a knob from kilo internationl with a number beginning with 90 (which means a 0.9" diameter) like the OEDNI-90-4-7 shown here.

OEDNI-90-4-7

***

## FINAL BUILD

This is how the final keyboard will look like. In this picture you see the KLOR saegewerk, with RAMA Grid keycaps in NOCT.

KLOR acrylic case

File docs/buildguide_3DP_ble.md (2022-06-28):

# KLOR BUILD GUIDE (3DP CASE BLE) [WIP]

Since the BLE versin of the 3D print case is untested this build guide isn't created yet.

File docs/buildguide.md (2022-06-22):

# KLOR BUILD GUIDE [WIP]

## PART LIST

### REQUIRED PARTS

| Part name | Quantity | Remarks | 
| --- | --- | --- |
| KLOR PCB | 02 | |
| ProMicro | 02 | Alternatively you can use another controller, with a similar pinout like the Elite-C, Puchi-C, KB2040 dda. |
| MX Key switch | 42 | 40 switches for Konrad / 38 switches for Yubitsume / 36 switches for Saegewerk |
| Switch socket | 42 | 40 sockets for Konrad / 38 sockets for Yubitsume / 36 sockets for Saegewerk |
| Diodes 1N4148W| 44 | They are surface mount diodes in SOD123 package. 42 for Konrad / 40 for Yubitsum / 38 for Saegewerk |
| 1u MX Keycaps | 42 | 40 keycaps for Konrad / 38 keycaps for Yubitsume / 36 keycaps for Saegewerk |
| OLED module | 02 | SSD1306 128x64 pixel OLED Displays |
| Reset Button  | 02 | Alps SKRTLAE010 |
| TRRS jack | 02 | |
| TRRS cable | 01 | Alternatively you can use a TRS cable for [half-duplex](https://github.com/qmk/qmk_firmware/blob/master/docs/serial_driver.md#usart-half-duplex)|
| EC11 encoder  | 02 | You can use any EC11 encoder, but it will look better if you use a short one, like the EC11N1524402 |
| encoder knob  | 02 | The design works best with a 2,2cm encoder knob. I recommend kilo international knobs with a number starting with 90. 
| USB cable | 01 | For connecting the keyboard with your PC |

### OPTIONAL PARTS

| Part name | Quantity | Remarks | 
| --- | --- | --- |
| MCU sockets | 04 | For socketing your MCU. Highly recommended |
| MCU pins | 48 | In combinatin with the MCU sockets |
| [Haptic Feedback Module](https://shop.pimoroni.com/products/drv2605l-linear-actuator-haptic-breakout) | 01 | Pimoroni Haptic Buzz |
| speaker | 01 | Mallory AST1109MLTRQ or Keliking KLJ-1102 |
| [trackball](https://bit-trade-one.co.jp/selfmadekb/adtb7m/) | 01 | Pixart PAW3204OA. You can get it from [Yushakobo](https://shop.yushakobo.jp/products/adtb7m) |
| [level converter](https://github.com/sekigon-gonnoc/LevelConverterForTrackballModule) | 01 | Needed to use the trackball. You can get it from [Yushakobo](https://shop.yushakobo.jp/products/a0800tl-01-1/) |
| [tenting puck](https://splitkb.com/products/tenting-puck)| 02 | SplitKB Tenting Puck |

### 3DP CASE PARTS

| Part name | Quantity | Remarks | 
| --- | --- | --- |
| 3D printed case | 02 | |
| acrylic parts | 02 | Three parts and one ring per side |
| switch plate | 02 | 1.5mm switch plate |
| 7mm M2 standoffs | 16 | |
| 6mm M2 screws | 16 | |
| 6mm M2 countersunk screws | 16 | The bottom only supports countersunk screws |

### ACRYLIC CASE PARTS

| Part name | Quantity | Remarks | 
| --- | --- | --- |
| acrylic parts | 02 | |
| switch plate | 02 | 1.5mm switch plate |
| 9mm M2 standoffs | 22 | Up to 22 9mm standoffs for the actual case (check the appropiate puzzleguide) |
| 7mm M2 standoffs | 12 | 7mm standoffs for holding the PCB in place |
| 6mm M2 screws | 56 | Up to 56 regular 6mm M2 screws (check the appropiate puzzleguide) |

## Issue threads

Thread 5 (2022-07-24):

How to set side

rklasen, 2022-07-24:
Hi, thanks for this fantastic project!

I'm currently building one of you KLOR Keyboards, this is my first DIY keyboard. Also my first time using QMK. Everything seems to be working for now, except for one thing.

How do I set the sides? It seems the side with the USB connection is always considered "left", but I'd like to connect the USB cable to the right side.

thanks again, and best wishes!

GEIGEIGEIST, 2022-07-24:
Hi R Klasen,
You should be able to add
`#define MASTER_RIGHT`
to the config.h file of your keymap. (for example klor\keymaps\default\config.h)
Please tell me if this works and I would be happy to see some pictures of it, when you finished it.

rklasen, 2022-07-24:
Hi, thank you for the quick answer! Yep, that worked!

I'll post some photos in this issue when I'm done, but my version won't be nearly as pretty as yours :sweat_smile:

I've just looked though the [qmk docs](https://github.com/qmk/qmk_firmware/blob/master/docs/feature_split_keyboard.md), and it seems one can set the headedness via a pull up o pull down. I'm not familiar enough with your circuit, so I don't know if any µC pin is still left available, but if it is, it should be possible to use `#define SPLIT_HAND_PIN B7` to set the left side during soldering. Either via solder bridge or µC ground. Maybe for v1.4 :smile:

So, thanks again, I really love this project!

GEIGEIGEIST, 2022-07-24:
Great it worked!

Hehe it's not a battle, I'm just really curious to see some people actually build it.

Yea, I know this one, but thank you for mentioning it. Unfortunately I've already used all the available pins for this version. I have some ideas for a next one, which would even use the pins available on MCUs with pins on the bottom.

Closed 2022-08-22.

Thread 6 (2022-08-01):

the stl files abnornal

hackqiang, 2022-08-01:
when I try to print the case via my printer, I found the stl file is abnormal while slicing(both checked in superslicer and Cura).
ex: KLOR_konrad_case_ble_L.stl in case\3DP\konrad\bluetooth:
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
But, It looks good in the windows 3D preview program.
I'm not sure the issue related to the STL or the slicer, So maybe the origin model design file should be helpful for fix this.

hackqiang, 2022-08-01:
I can use the fusion 360 to fix: open stl, fix model and export stl.

GEIGEIGEIST, 2022-08-01:
Thank you for pointing this out. May I ask which fix you applied? (Stitch and Remove/Close Holes/Wrap/Rebuild)
Unfortunately the case was made in Blender, since it was easier to create all the variations for me using Geometry Nodes.

hackqiang, 2022-08-07:
I'm sorry for reply so late, I use "stitch and remove" to fix the STLs:
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

hackqiang, 2022-08-07:
and for case of bluetooth verison, it seems no space for battery

GEIGEIGEIST, 2022-08-22:
I finally fixed all the STLs.

But yea, I still didn't found a good place for the battery other than under the MCU. Originally it was meant to be a QMK only board, but some people asked me for JST and power-switches.

Closed 2022-08-23.

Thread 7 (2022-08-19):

Keys not working with minimum viable example

sommerper, 2022-08-19:
Hi!

Thank you for a great project.

I'm having some trouble getting a minimum viable version to work.
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

As seen in the included image I first tried soldering all the components but that didn't work. No keys, LEDs, knob, nor the LCD worked.

Then I tried making a version where I would solder all the diodes but mount just one key - but that also didn't type anything when I pressed the key.

I've tested all the diodes with a multimeter and they all seem to be mounted correctly.

I've tested with several Pro Micros fresh out of the bag.

The first time I flash I can use USB-C with this command:

```shell
avrdude -v -patmega32u4 -cavr109 -P/dev/ttyACM0 -b57600 -Uflash:w:"/home/xxx/qmk/qmk_firmware/klor_default.hex":i
```

Then subsequently the Pro Micro will not show up on 'ttyACM0' anymore (even when double tapping reset) and I have to flash using an 'Arduino as ISP'. Like so:

```shell
/home/xxx/.arduino15/packages/arduino/tools/avrdude/6.3.0-arduino17/bin/avrdude "-C/home/xxx/.arduino15/packages/arduino/tools/avrdude/6.3.0-arduino17/etc/avrdude.conf" -v -patmega32u4 -cavr109 -P/dev/ttyACM0 -b19200 -cstk500v1 -Ulock:w:0x2F:m -Uflash:w:"/home/xxx/qmk/qmk_firmware/klor_default.hex":i
```

An odity - but in any case - it works and the Pro Micro shows up as `Bus 001 Device 125: ID 3a3c:0001 GEIST KLOR`.

My `keymaps/default/rules.mk` looks like this:

```shell
OLED_ENABLE = no
OLED_DRIVER = SSD1306
ENCODER_ENABLE = yes
EXTRAKEY_ENABLE = yes
AUDIO_ENABLE = no
MUSIC_ENABLE = no
MOUSEKEY_ENABLE = yes

DYNAMIC_MACRO_ENABLE = yes
COMBO_ENABLE = yes
KEY_OVERRIDE_ENABLE = yes

#HAPTIC FEEBACK
HAPTIC_ENABLE = no

#PER KEY RGB
RGB_MATRIX_ENABLE = no
```

I'm kinda at a loss here but I suspect it's a QMK configuration problem since I traced the paths with a multimeter and there where no interruptions from switches to the Pro Micro.

I'm not a complete noob when it comes to soldering keyboards as I've done a few Ferris' and Plancks but I won't leave out the possibility that I've done something wrong while soldering.

Any suggestions as to what could be wrong are greatly appreciated!

sommerper, 2022-08-21:
Out of curiosity I tried flashing a Contra.hex (Planck layout) and I could get some of the keys to work. So I know that at least the soldering works in most places. After flashing the Klor firmware back on the keys where all dead again.

Which, again, makes me think this is a QMK configuration issue.

GEIGEIGEIST, 2022-08-21:
Sorry for answering so late, I'm a little bit busy right now. But if you like to I could send you a working hex file, so you could see if it's a hardware or software issue.
By the way depending on your case the pro micro sockets seem a bit high

sommerper, 2022-08-21:
Thanks for replying and no worries. I'm not in a hurry.
The sockets are just temporary because I ran out of pins.
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

But, yes! If you can find the time to upload a working .hex it would be appreciated!

GEIGEIGEIST, 2022-08-21:
You can find it [here](https://github.com/GEIGEIGEIST/qmk-config-klor)

sommerper, 2022-08-21:
Unfortunately that also didn't work. But thank you for taking the time!

I've double checked all the traces to the pins of the pro micro and all seems fine.

This might be a stupid question but can I check the left keyboard alone without having the right one connected? So far I've only made the left side.

GEIGEIGEIST, 2022-08-21:
Oh than it seems to be an hardware issue.
Unfortunately hard to tell where the problem could be. Do you own a multimeter?

And yes you can check both halves separatly.

sommerper, 2022-08-21:
I do indeed have a multimeter. That's how I tested the traces and diodes earlier.
Since the Vial Contra made some of the keys respond I tried fiddling with the code a little - and it turns out that if I switch the matrix configuration around like this
```
// wiring of each half
// #define MATRIX_ROW_PINS { C6, D7, E6, B4 }
#define MATRIX_ROW_PINS { F6, F7, B1, B3 }
// #define MATRIX_COL_PINS { F6, F7, B1, B3, B2, B6 }
#define MATRIX_COL_PINS { C6, D7, E6, B4, B2, B6 }
```
a lot of keys start working but with a weird layout.
I starting to wonder if I soldered the Pro Micro in the wrong holes.
But judging from the [photo](https://github.com/GEIGEIGEIST/KLOR/blob/main/docs/images/buildguide/breakoff.jpg) I did do it correctly. Basically following the white outlines.
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
I'll see if I can figure out some more.

sommerper, 2022-08-21:
Indeed, following [this guide](https://deskthority.net/wiki/Arduino_Pro_Micro#Pinout) I basically mirrored the default config and got all of the keys working:

```
// wiring of each half
// #define MATRIX_ROW_PINS { C6, D7, E6, B4 }
#define MATRIX_ROW_PINS { F7, B1, B3, B2 }
// #define MATRIX_COL_PINS { F6, F7, B1, B3, B2, B6 }
#define MATRIX_COL_PINS { D4, C6, D7, E6, B4, B5 }
```
I still haven't figured out the settings for the encoder and OLED display.

But I guess it boils down to having soldered the Pro Micro either on the wrong side or in the wrong holes?

GEIGEIGEIST, 2022-08-21:
Sorry I didn't noticed before, but you got it mounted the wrong way. The components needs to face the PCB.

sommerper, 2022-08-22:
Damn, you're absolutely correct. It's even clearly mentioned in the build guide. I knew it was probably something stupid on my part. Still haven't tested OLED and LEDs but all keys and encoders work now.

Sorry for wasting your time :-/

GEIGEIGEIST, 2022-08-22:
Hehe don't worry, stuff like this happens sometimes and I didn't noticed at first either. Glad it's working now.

sommerper, 2022-08-23:
It's looking and working really good!
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

Would you be willing to open the discussions forum? I have a question that is not an issue. Or should I just ask here?

GEIGEIGEIST, 2022-08-23:
Oh just ask here. And by the way it looks really nice!

sommerper, 2022-08-23:
I just wanted to know what the timeline for Vial compatibility looks like. For me, flashing with QMK every time is very time consuming process because I can't get the chip to go into bootloader mode and I have to use an AVR flasher. And with every new keyboard I spend a good amount of time optimizing a layout.

Maybe I can try to make the Sofle template in the repository work somehow.

GEIGEIGEIST, 2022-08-23:
While someone in my main discord channel is doing a VIAL workshop today it probably will take some time to do it right. But you can use this hex in the meantime (which was done by someone who already knows how to handle VIAL
[klor_vial.zip](https://github.com/GEIGEIGEIST/KLOR/files/9401809/klor_vial.zip)
)

sommerper, 2022-08-23:
Thanks! That already works pretty well! Let me know if you need any testing done before releasing it.

GEIGEIGEIST, 2022-08-23:
I maybe will, thank you

Closed 2022-08-22.

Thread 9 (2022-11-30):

Would this diode work with KLOR?

bellascalzi1, 2022-11-30:
Hi, I ordered the PCBs for the KLOR and currently in the process of ordering components. I'm wondering if this diode will work with the KLOR? (https://au.mouser.com/ProductDetail/241-1N4148W_R1_00001). I noticed that on the product page the package says "SOD-123-2" instead of just "SOD-123", does that matter? My knowledge of electronics is quite limited so all the numbers don't really make sense to me haha.
Thanks for your help!

GEIGEIGEIST, 2022-11-30:
Hehe to be honest I don't know either, BUT I recently ordered my first assembled PCB and accidentally chose much smaller 1N1448W diodes. They still fitted the pads, which is the important part, since the SOD-123-2 part only refers to the size, not the conductance.
But you could also just buy [these ones](https://www.mouser.de/ProductDetail/Diodes-Incorporated/1N4148W-7-F?qs=LHX0FizJzg7Ae9ZM8LTAWw%3D%3D).

Closed 2022-12-08.

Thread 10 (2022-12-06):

Keys Z, X and DEL not working on left side

Kimishiba, 2022-12-06:
keys Z X and DEL not working on the left side with the provided firmware, however if plugging in the right side, those keys work indicating an issue with the firmware. probably the pin defintion?

Kimishiba, 2022-12-06:
with the left half plugged in, the keys mapped to matrix Col0 Row2 (DEL), Col1 Row2 (Z), Col2 Row2 (X) are not recognized. shorting the pins on the pro micro also causes no keypress in the key tester

however if the left and right halves are plugged together and the usb cable plugged in the slave side, the keys get recognized as keypresses (just the keymap is inverted), thus proving that there is electrical connection, but a problem in the software side

GEIGEIGEIST, 2022-12-07:
That sounds like a weird error. May I ask which MCU and layout you're using?

Kimishiba, 2022-12-09:
the mcu is a pro micro and the keymap is the vial one

Closed 2022-12-29.

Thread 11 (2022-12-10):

Choc v1 switches?

JeppeKlitgaard, 2022-12-10:
I couldn't seem to gleam from the documentation whether the PCB supports Choc v1 switches or just MX ones.

GEIGEIGEIST, 2022-12-11:
Unfortunately it only supports MX switches.

JeppeKlitgaard, 2022-12-12:
Ah, okay. Thank you for the prompt response! Feel free to close this (or leave it open for others to find)

Closed 2022-12-12.

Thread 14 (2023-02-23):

SK6812 size?

burakkaraceylan, 2023-02-23:
Hello! Thanks for the amazing desing. I am planning to build one and I am looking for parts. I have some smd 6028 leds lying around but I suppose I can't make them work with this pcb. I found [these ](https://www.aliexpress.com/item/33015457082.html?spm=a2g0o.cart.0.0.558c38da9jqpby&mp=1)? Should I order 3535 or 5050 ?

GEIGEIGEIST, 2023-02-23:
Hi. Unfortunately 6028 won't work. But the ones you've linked are fine. You need to use the 3535.

burakkaraceylan, 2023-02-24:
Ok! Thank you very much!

Closed 2023-02-24.

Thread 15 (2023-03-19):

Problem with serial communication

burakkaraceylan, 2023-03-19:
Hello,

I just built a Klor keyboard but there is a weird problem and I need help to fix it. Both split parts work fine when tested separately. However when I connect them using a trrs cable last two keys (shift and ' in the default layout) constantly registers as pressed. I checked the pcb's with a multimeter and there doesn't seem to be any shorts. The thing is if I dont push the trrs jacks all the way in and leave the last bit out then the problem disappears. What could be the reason?

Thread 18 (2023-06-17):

Trackball support

pokeygithub, 2023-06-17:
I was reading your article on Keyboard Builders Digest and saw that you had gotten the trackball working (in a new location).  Could you  point me in the right direction for getting it enabled (in the original location)?  I was looking into maybe swapping it over to the pimoroni but I am absolutely terrible at moving things in kicad (other that messing things up!)

pokeygithub, 2023-06-18:
I think I figured it out!  Would you please validate that my work actually...... worked?
https://github.com/pokeygithub/KLOR/tree/main/PCB/klor1_3

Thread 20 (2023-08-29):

Cant build default keymap

bitsandbyt3, 2023-08-29:
Hallo,

i have finally finished all the soldering and tried to build the default keymap. I get the error in the attached screenshot, can someone help me find a solution.

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

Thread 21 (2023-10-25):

Clarification on Switchplates and Concerns about 3D Printing Warning

sedghi, 2023-10-25:
I read

> You need a switchplate and the acrylic parts, no matter what case you choose.

But I believe you mean two switchplates right?

When I upload the stl file to jlcpb I see the following warning for the 3D printing, any combination of the 3D technology and material I use still shows it. Any idea if this is serious warning?

`The minimum build size for LEDO 6060 Resin is 1.00x1.00x0.20cm, please change the material.`

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

sedghi, 2023-10-25:
Thanks for your reply.
Seems like the FR-4 does not give that error for 3D print, so I will probably do that.

I requested a quote from a local shop around me for the Archlyc. Thanks !

sedghi, 2023-10-25:
@CipherJay Which layout and which version (BLE vs wired) you built out of curiosity

LucaEic, 2023-11-15:
Hi everyone,

I'm also looking into building the Polydactyl.

Regarding 2) It looks like the length x width x heigth dimension are in the wrong order. It say "minimum is 1.00 x 1.00 x 0.2 cm and the given dimension in the sketch are 15.03 x 0.15 x 10.48 cm. Howver, I'm not fond enough to change this issue thats why i looked in the FR-4 switchplat.

This being said, I have a question to the FR-4 switchplate: when uploading the gerber files the preview looks like this:

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

Are the cut outs for the keys present? Or is this just a display issue that it appears to be a solid plate? Furthermore, the 3D printed parts shall be 1.5mm however the FR-4 can only be 1.2 or 1.6mm. Does this have any effect? I would like to use silent tactile switches (like Boba U4t). I have read that for the tiny choc switches 1.2mm should be used.

Thanks and chers
Luca

Vinna152, 2023-11-20:
I'd advise looking at the project files in KiCad to confirm. The exported gerbers should be fine since they're based on those files.

These Gerber previews often aren't 100% representative of the actual file structure.
You can also confirm the exact sizes in KiCad and even if it's just an estimate an engineer on their side will correct it for you.

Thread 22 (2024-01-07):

What’s this part?

ykie-Wang, 2024-01-07:
I am new to github and can I ask what’s the part in this photo? I want buy one! Thank you very much!
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

ykie-Wang, 2024-01-07:
> I found [this](https://a.co/d/3RzSDer) part in America. Geist is German, I think, so I'm not sure where he got his.

Thanks a lot! I have found this too, but I can’t make sure whether it’s the same with the one in the photo either. Thanks again.

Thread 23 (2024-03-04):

Silly question on reset button/switch

danbowles, 2024-03-04:
I want to make sure I am reading the guide correctly:

1.  The outer-most pads at the edge of the PCB for the reset are just for mounting.  Solder those with a thin film to mount the switch.
2. My confusion begins: Do I flip the PCB over then and jumper all the smaller pads together? Not sure I follow

Also, does the switch go one the same side as the hot-swap sockets/promicro, etc?

Many thanks!

danbowles, 2024-03-04:
Neevermind; Sorted it.  I soldered the two outer pads and 2 of the inner pads.

My issue before was when I soldered the 3 pads with too much solder I think and the board was in a "perma-reset" state of sorts :).

Closed 2024-03-04.

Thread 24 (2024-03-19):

Couple Noob questions

psillypsymun, 2024-03-19:
1. I bought a kit on etsy that came with a pair of Sea Picro microcontrollers. I'm assuming that limits me to KMK firmware since its RP2040 based.  And I'm a little concerned about the pinout.  It doesn't look compatable at all.  For example the Sea Picro looks like it has the TX and RX right next to each and the Klor board has them 5 pins apart. And apparently this stupid board only puts out 3v and has a separate pin in the middle to put out 5.  Is it possible to bridge that center pin to somewhere so I can use that power for LEDs down the road?

2. Does anyone have any advice how to set up the displays in KMK? It all looks pretty lame by default.  Just a readout per corner.  I was hoping to display some vector graphics or something.  Is that possible?  I kinda like that sad robot graphic that's printed on the board.  Near as I can tell, you would have to split that into quarters and have it display a piece per corner.  Am I understanding this right?

3. When setting up KMK firmware, I understand the basic idea.  But I have no idea if I have edited all the right stuff aside from the keymap.  I know the folder in this git is mostly preconfigured. I see where you can set the board type, LED, OLED, and speaker. I have no idea where I am supposed to insert code for tap dances and stuff though? And when I'm ready to write it to the board, what do I do with these rename_klor_left and right folders?

4.  There's a behavior I had on a midi controller that I'm wondering is possible with one of these encoders.  On the Novation Nocturn there was a big center knob and when you touched it it would do a left mouse click and hold and when you turned the knob one direction it would move the mouse up and to the right or down and to the left. It's really handy for turning knobs in audio software.  Is it possible in KMK to have a key combo for a mouse click that I can hold and turn a knob to move the mouse cursor?

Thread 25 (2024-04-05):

Consider adding soldered switch support?

Bertie2011, 2024-04-05:
I love the design, but I'm worried that the hotswap components could dislodge if I'd travel with the keyboard lots (to work and back). Would you ever consider making a soldered switch version?

Or maybe there are hybrid footprints out there... I know some allow you to rotate the switch to make that happen but then you'd have problems with the LEDs.

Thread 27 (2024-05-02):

Issues with JLCPCB?

jesseleite, 2024-05-02:
Anyone have trouble getting the KLOR printed with JLCPCB?

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

Seems odd that they would suggest short circuits in the KLOR gerbers? Am I doing something wrong maybe? All settings are default, except that I selected the color black, and 'yes' to remove order number.

jesseleite, 2024-05-03:
Oh they responded to my customer support request. They're saying:

>"The distance from copper to slot should be at least 0.3 mm"

@GEIGEIGEIST By chance have you had any trouble getting these printed at JLCPCB? They attached these pics to the support convo :'(

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

Lefuneste83, 2024-07-05:
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

Hi there. I have bumped into the very same issue today, or at least I noticed something was totally wrong before placing an order with JLCPCB. The problem you encountered does not come from "shorted tracks" but rather from the routing around the LED cutouts. When I imported the gerbers I noticed many LED cutouts were missing, and reading your post I made the connection...

As you may have noticed this PCB design is reversible and thus both layouts for Left and Right boards have to share the same vertical space.
On first analysis this approach may sound clever, but considering the added routing complexity and the rather low cost of manufacturing a set of PCB, it may be better to implement a dedicated PCB for Left and Right boards rather than to attempt cramming everything into one board.
Anyway, I have reviewed the design and indeed many traces are not clearing the LED cutouts enough to be able to manufacture them.
If I may give my opinion,I find the routing rather weird, and maybe there was some auto routing involved at some point. From my experience in designing PCB and being as OCD as possible about trace clearance and proper routing, I think there may be room for improvement with  this PCB design.  I wish to emphasis that this does NOT relate to the quality of the overall project. It just makes it a little bit more difficult to tame. I haven't been as far as to check DRC yet using JLCPCB set of rules, so there may be other pending issues.
I will try to fork the repo and update the most daring issues. In the meantime let me know if you need updated gerbers that will clear JLCPCB review process.

Korkd, 2024-07-08:
> I will try to fork the repo and update the most daring issues. In the meantime let me know if you need updated gerbers that will clear JLCPCB review process.

Any chance you've gotten around to posting these?

Korkd, 2024-07-09:
[KLOR_pcb.zip](https://github.com/user-attachments/files/16140852/KLOR_pcb.zip)

Took a shot at cleaning up the PCB. If anyone more experienced/knowledgeable has a chance to look at it and let me know if there are any issues that'd be great. Haven't done any PCB design before so just a buyer beware if you stumble upon this.

Lefuneste83, 2024-07-09:
Here is my take on the rerouted PCB. If you wish to rework the PCB from the native Kicad files, beware that the various silkscreen can end up on top of the copper pads if you forget to tick the proper box when exporting gerber files.
I have ordered the following file and it was validated by JLCPCB although the DRC (with proper DRU file from JLCPCB) fails with hundreds of warnings and errors due to the nature of the design (cutouts, clearances...). I hope the PCB still is OK but I don't see why it wouldn't. I haven't built it yet so be careful. The native modified files should be on my fork.

https://github.com/Lefuneste83/KLOR/blob/main/PCB/klor1_3/gerbers/gerbers.zip

jesseleite, 2024-08-19:
@Lefuneste83 Curious if you ended up building yours off those gerbers you linked, and how it worked out? 🙏

jesseleite, 2024-08-19:
@Lefuneste83 Curious if you ended up building yours off those gerbers you linked, and how it worked out?

>I have ordered the following file and it was validated by JLCPCB although the DRC (with proper DRU file from JLCPCB) fails with hundreds of warnings and errors due to the nature of the design (cutouts, clearances...)

Oh... So even with your rerouting changes, JLC still gave you warnings and errors around cutouts/clearances like in my original post's screenshots?

Lefuneste83, 2024-08-19:
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

Yes original design 1.3 will give you several kind of DRC errors mainly due to clearances on switch holes and in the way markings are made with mask/copper layers. Design 1.4 being rerouted will not have the same errors. With the included JLCPCB dru file you should only get a minor error due to termination of the LED strip which has a pair of unconnected nodes which is to be expected. Both updated 1.3 and 1.4 on my fork will be built to functional boards by JLCPCB. I have ordered and built both designs. I suggest you get the 1.4 design using SK6812 Mini-e LED package which are way easier and cleaner to build.

jesseleite, 2024-08-19:
I'm not even using LEDs on this build, but if 1.4 is less JLC warnings/errors, that sounds great! I see your commit on the [1.4 gerbers.zip](https://github.com/Lefuneste83/KLOR/blob/main/PCB/klor1_4/gerbers/gerbers.zip) is only from last week. Do you plan on getting them printed and into a build soon? Curious how it goes, and if any issues ❤️

Lefuneste83, 2024-08-19:
I have built my custom 1.3 version (the one found on my fork) and the 1.4 version (the version just before the very last commit) and I am currently using it as my keyboard. Both work perfectly. As explained in the changelog I discovered a small interference of about 0.45 mm between the edge of the stock haptic module PCB (which I currently do not have because I find it too expensive) and the top switch socket. The latest 1.4 commit corrects this by moving the haptic module position and cutout by 0.6 mm up in order to clear the interference. This interference comes from the reversed switch position to allow for south facing of the LED. I have also included a DIY version of the haptic module which I will be validating soon. Just waiting for parts and PCB. All these modifications only concern the haptic module itself. If you don't intend to use it then even the previous commit will be fine. It will only cause a small issue if using the stock Pimoroni module but not the DIY one I designed which will work even on previous commit as it has been shorten by 0.8 mm. Even in the worst case scenario of not using the very latest commit of the 1.4 and the Pimoroni module, the interference is so small you can just file the PCB of the haptic module by a tiny bit to clear it. It may even not be an interference at all depending of various mechanical tolerances. This is just to make the most perfect PCB possible. In case you put LED anyways the new packages are super cheap and really easy to solder. Way easier than WS2812 3535. Even if not using them for "light shows" they are nice to have as they can be programmed to indicate active layer at least if using QMK. If you will never solder any LED then any version 1.3 or 1.4 will be similar for you. The 1.4 will definitely have less DRC errors as I have made sure to correct them and this was not an easy task.

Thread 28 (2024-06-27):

Compile fails.

pokeygithub, 2024-06-27:
☒ Not including data from file: keyboards/klor/info.json
☒       layouts.LAYOUT_yubitsume.layout.20.x: -0.5 is less than the minimum of 0
☒ klor/2040: RGB_DI_PIN in config.h is no longer a valid option and should be replaced with WS2812_DI_PIN or APA102_DI_PIN
☒ Invalid API data: klor/2040: haptic.driver: 'DRV2605L' is not one of ['drv2605l', 'solenoid']

 *                                                                                                     [ERRORS]

builddefs/converters.mk:22: *** Converting to 'promicro_rp2040' not possible!.  Stop.

Manamonk, 2024-07-09:
I've got the same errors did you find the answer?

pokeygithub, 2024-07-10:
What I had to do was abandon the 2040 (folder) command and do qmk make -kb klor -km default -e CONVERT_TO=promicro.
You might need edit the config.h in that folder find and replace RGB_DI_PIN with WS2812_DI_PIN and DRV2607L with drv26505l  it hates all caps for some reason!
You will need to edit the kyboard layout if you are trying to use Colmak layout and if you edit the adjust layer command you can run the make command above with a simple key combination to make and then to reset for flashing.
Please let me know if that works for you!

pokeygithub, 2024-07-11:
[klor2.zip](https://github.com/user-attachments/files/16170307/klor2.zip)

If you extract it as klor2 it won't screw up any of your original files.
Maybe this will help you.  If you use the "pokey" it will get colmak working for you as well.

Manamonk, 2024-07-18:
Hi pokey - I tried running the pokey keymap and got the following :(

[dm@hhhhh QMK_files]$ qmk compile -kb klor -km pokey
Ψ Compiling keymap with make -r -R -f builddefs/build_keyboard.mk -s KEYBOARD=klor KEYMAP=pokey KEYBOARD_FILESAFE=klor TARGET=klor_pokey INTERMEDIATE_OUTPUT=.build/obj_klor_pokey VERBOSE=false COLOR=true SILENT=false QMK_BIN="qmk"

☒ Not including data from file: keyboards/klor/info.json
☒       layouts.LAYOUT_yubitsume.layout.20.x: -0.5 is less than the minimum of 0
⚠ klor: Build marker "keyboard.json" not found.
☒ klor: No LAYOUTs defined! Need at least one layout defined in info.json.
☒ klor: LAYOUT_polydactyl: Layout macro should not be defined within ".h" files.
☒ klor: LAYOUT_konrad: Layout macro should not be defined within ".h" files.
☒ klor: LAYOUT_yubitsume: Layout macro should not be defined within ".h" files.
☒ klor: LAYOUT_saegewerk: Layout macro should not be defined within ".h" files.
Generating: .build/obj_klor_pokey/src/info_deps.d                                                   [OK]
☒ Not including data from file: keyboards/klor/info.json
☒       layouts.LAYOUT_yubitsume.layout.20.x: -0.5 is less than the minimum of 0
⚠ klor: Build marker "keyboard.json" not found.
☒ klor: No LAYOUTs defined! Need at least one layout defined in info.json.
☒ klor: LAYOUT_polydactyl: Layout macro should not be defined within ".h" files.
☒ klor: LAYOUT_konrad: Layout macro should not be defined within ".h" files.
☒ klor: LAYOUT_yubitsume: Layout macro should not be defined within ".h" files.
☒ klor: LAYOUT_saegewerk: Layout macro should not be defined within ".h" files.
avr-gcc.exe (GCC) 12.2.0
Copyright (C) 2022 Free Software Foundation, Inc.
This is free software; see the source for copying conditions.  There is NO
warranty; not even for MERCHANTABILITY or FITNESS FOR A PARTICULAR PURPOSE.

Generating: .build/obj_klor_pokey/src/info_config.h                                                 [WARNINGS]
 |
 | ☒ Not including data from file: keyboards/klor/info.json
 | ☒    layouts.LAYOUT_polydactyl.layout.20.x: -0.5 is less than the minimum of 0
 | ⚠ klor: Build marker "keyboard.json" not found.
 | ☒ klor: No LAYOUTs defined! Need at least one layout defined in info.json.
 | ☒ klor: LAYOUT_polydactyl: Layout macro should not be defined within ".h" files.
 | ☒ klor: LAYOUT_konrad: Layout macro should not be defined within ".h" files.
 | ☒ klor: LAYOUT_yubitsume: Layout macro should not be defined within ".h" files.
 | ☒ klor: LAYOUT_saegewerk: Layout macro should not be defined within ".h" files.
 |
Generating: .build/obj_klor_pokey/src/default_keyboard.c                                            [WARNINGS]
 |
 | ☒ Not including data from file: keyboards/klor/info.json
 | ☒    layouts.LAYOUT_saegewerk.layout.20.x: -0.5 is less than the minimum of 0
 | ⚠ klor: Build marker "keyboard.json" not found.
 | ☒ klor: No LAYOUTs defined! Need at least one layout defined in info.json.
 | ☒ klor: LAYOUT_polydactyl: Layout macro should not be defined within ".h" files.
 | ☒ klor: LAYOUT_konrad: Layout macro should not be defined within ".h" files.
 | ☒ klor: LAYOUT_yubitsume: Layout macro should not be defined within ".h" files.
 | ☒ klor: LAYOUT_saegewerk: Layout macro should not be defined within ".h" files.
 |
Generating: .build/obj_klor_pokey/src/default_keyboard.h                                            [WARNINGS]
 |
 | ☒ Not including data from file: keyboards/klor/info.json
 | ☒    layouts.LAYOUT_saegewerk.layout.20.x: -0.5 is less than the minimum of 0
 | ⚠ klor: Build marker "keyboard.json" not found.
 | ☒ klor: No LAYOUTs defined! Need at least one layout defined in info.json.
 | ☒ klor: LAYOUT_polydactyl: Layout macro should not be defined within ".h" files.
 | ☒ klor: LAYOUT_konrad: Layout macro should not be defined within ".h" files.
 | ☒ klor: LAYOUT_yubitsume: Layout macro should not be defined within ".h" files.
 | ☒ klor: LAYOUT_saegewerk: Layout macro should not be defined within ".h" files.
 |
Compiling: keyboards/klor/klor.c                                                                    [OK]
Compiling: .build/obj_klor_pokey/src/default_keyboard.c                                             [OK]
Compiling: quantum/keymap_introspection.c                                                           [OK]
Compiling: quantum/quantum.c                                                                        [OK]
Compiling: quantum/bitwise.c                                                                        [OK]
Compiling: quantum/led.c                                                                            [OK]
Compiling: quantum/action.c                                                                         [OK]
Compiling: quantum/action_layer.c                                                                   [OK]
Compiling: quantum/action_tapping.c                                                                 [OK]
Compiling: quantum/action_util.c                                                                    [OK]
Compiling: quantum/eeconfig.c                                                                       [OK]
Compiling: quantum/keyboard.c                                                                       [OK]
Compiling: quantum/keymap_common.c                                                                  [OK]
Compiling: quantum/keycode_config.c                                                                 [OK]
Compiling: quantum/sync_timer.c                                                                     [OK]
Compiling: quantum/logging/debug.c                                                                  [OK]
Compiling: quantum/logging/sendchar.c                                                               [OK]
Compiling: quantum/matrix_common.c                                                                  [OK]
Compiling: quantum/matrix.c                                                                         [OK]
Compiling: quantum/debounce/sym_defer_g.c                                                           [OK]
Compiling: quantum/split_common/split_util.c                                                        [OK]
Compiling: quantum/split_common/transport.c                                                         [OK]
Compiling: quantum/split_common/transactions.c                                                      [OK]
Compiling: quantum/main.c                                                                           [OK]
Assembling: platforms/avr/xprintf.S                                                                 [OK]
Compiling: platforms/avr/printf.c                                                                   [OK]
Compiling: drivers/oled/oled_driver.c                                                               [OK]
Compiling: quantum/encoder.c                                                                        [OK]
Compiling: drivers/encoder/encoder_quadrature.c                                                     [OK]
Compiling: quantum/crc.c                                                                            [OK]
Compiling: quantum/send_string/send_string.c                                                        [OK]
Compiling: tmk_core/protocol/host.c                                                                 [OK]
Compiling: tmk_core/protocol/report.c                                                               [OK]
Compiling: tmk_core/protocol/usb_device_state.c                                                     [OK]
Compiling: tmk_core/protocol/usb_util.c                                                             [OK]
Compiling: platforms/suspend.c                                                                      [OK]
Compiling: platforms/synchronization_util.c                                                         [OK]
Compiling: platforms/timer.c                                                                        [OK]
Compiling: platforms/avr/hardware_id.c                                                              [OK]
Compiling: platforms/avr/platform.c                                                                 [OK]
Compiling: platforms/avr/suspend.c                                                                  [OK]
Compiling: platforms/avr/timer.c                                                                    [OK]
Compiling: platforms/avr/bootloaders/dfu.c                                                          [OK]
Compiling: platforms/avr/drivers/i2c_master.c                                                       [OK]
Archiving: .build/obj_klor_pokey/i2c_master.o                                                       [OK]
Compiling: platforms/avr/drivers/i2c_slave.c                                                        [OK]
Archiving: .build/obj_klor_pokey/i2c_slave.o                                                        [OK]
Compiling: platforms/avr/drivers/serial.c                                                           [OK]
Archiving: .build/obj_klor_pokey/serial.o                                                           [OK]
Compiling: tmk_core/protocol/lufa/lufa.c                                                            [OK]
Compiling: tmk_core/protocol/usb_descriptor.c                                                      tmk_core/protocol/usb_descriptor.c:449:35: error: 'VENDOR_ID' undeclared here (not in a function)
  449 |     .VendorID                   = VENDOR_ID,
      |                                   ^~~~~~~~~
tmk_core/protocol/usb_descriptor.c:450:35: error: 'PRODUCT_ID' undeclared here (not in a function); did you mean 'PRODUCT'?
  450 |     .ProductID                  = PRODUCT_ID,
      |                                   ^~~~~~~~~~
      |                                   PRODUCT
tmk_core/protocol/usb_descriptor.c:451:35: error: 'DEVICE_VER' undeclared here (not in a function)
  451 |     .ReleaseNumber              = DEVICE_VER,
      |                                   ^~~~~~~~~~
In file included from tmk_core/protocol/usb_descriptor.c:42:
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
pokeygithub, 2024-07-21:
Hmmm.  Maybe it I forgot that I modified the json?
[info.json](https://github.com/user-attachments/files/16322984/info.json)

Are you running everything as an administrator?  Pretty much have to do the entire process from installing QMK to running the keyboard make commands.

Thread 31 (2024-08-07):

Updated PCB design with South Facing SK6812 Mini-E ARGB

Lefuneste83, 2024-08-07:
Hi there!

For those interested in building a KLOR keyboard you may check [my fork](https://github.com/Lefuneste83/KLOR) of the design including :

- Easier to solder and more suited SK6812 Mini-E ARGB LED modules
- South facing LED configuration
- Easier to solder triangular bridge footprints
- Design passes DRC check for JLCPCB with 0 errors and builds without issues
- Almost complete parts rerouting and various small corrections on grounding issues
- Various corrections of SMD footprints for valid stencils fabrication

**Make sure you read the disclaimers as there is a slight change in the tenting puck mounting position in case you want to use one.**

**Please let me know if you wish to have this design improved one way or another. I'll be glad to help!**

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

psi4j, 2024-08-15:
These are some awesome updates to the boards. Great work, my friend. Will you be adding the trackpad integration that was done for the KLOR as an alternative? If you made an updated version with the trackpad integration I would switch over to your  build real quick. Imagine not struggling with those tiny little LEDs anymore. I have a microscope and I still struggled. Good stuff!

Lefuneste83, 2024-08-19:
Thank you for your feedback. I haven't found a proper solution yet for the pointing device. One of the issues I have found after a little bit of research, is that the original design expects an I2C interface which is not, by far, an "industry standard" for pointing devices. I believe the author went with a Pimoroni trackball as the expected pointing device which is one of the few using an I2C interface to communicate with the MCU. The best solution for this keyboard would be to use a Thinkpad style trackpoint as they are ubiquitous, very small in size and quite precise. Plus many people including myself really appreciate their ergonomics. The problem is that most of the trackpoint modules found on Aliexpress expect some sort of PS/2 style data interface. Also goes the QMK drivers so it is not only an electrical issue. But I will try to do some research again to find a solution.

ux0rial, 2024-08-22:
Wow! This is an awesome update with a lot of QOL improvements. Thanks a lot, boss.

By the way, is this version compatible with KS-27/33?

Lefuneste83, 2024-08-22:
Thank you for your feedback. No as stated in the header comments on my fork  this is currently only for normal full height switches but apart from the 3d printed cases it should be pretty straightforward to convert the design to low profile switches as only the switch composite footprint would require an update followed by some fine grain rerouting of the few pins that would get slightly displaced. From what I can experience with my build you may also be able to use the same enclosure with low profiles switches. We would need to give it a try. Also note there already exists a modded version of the 1.3 with low profile switches support although it may restrict you to KS27 and Choc V1. I believe KS27 have the same pinout compared with latest KS33 and in particular will allow the use of Gateron Banana which are excellent tactile switches. Choc V1 are better avoided as they require specific dual tab keycaps that cannot be sourced in any convenient manner and are either very expensive or of very poor quality. The best target for a modded pcb would be to have compatibility to KS33, Choc V2 and Kailh latest offering which are supposed to be excellent. low profile switches.

ux0rial, 2024-08-22:
Thanks so much for getting back to me!

For now, I’ll build one using your current version (1.4) since I have no experience with PCB design or modding.

I did see a low-profile fork of the Klor, but as you said, it’s only KS-27 and Choc v1. And as you mentioned, I was actually looking for KS-33 compatibility to try the new Gateron Bananas. I do have a Totem with Choc v1, and those switches are pretty meh. I’m totally up for being a guinea pig if you decide to explore the idea of a KS-33/Kailh v2 version though!

Lefuneste83, 2024-08-22:
If you want to spend some time doing a little bit of research around the other low profile modded version, KS27 and KS33 may be pin compatible but make sure the pcb allows for both as it is not only the pin placement but also the cutouts that make the integration possible.

Lefuneste83, 2024-08-27:
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

Hi there. I have made an initial low profile version for Gateron KS33 switches if you want to give it a try.
Please read the Changelog for specific informations regarding this version.
You can find it here : https://github.com/Lefuneste83/KLOR/tree/main/PCB/klor1_4_LP_KS33

Now I have to do the same for Kailh V2 which cannot fit on the same PCB due to hole cutouts.

ux0rial, 2024-08-27:
Awesome! Thanks for taking the time to build this version. I can’t wait to try it out.

By the way, is there any issue using the cases on the KS-27 modded version?

Lefuneste83, 2024-08-27:
The KS27 version seems to have some differences in the way it interacts with the enclosure. You should ask its designer.
Also I believe that some people would prefer a slimer case for a low profile build so it may be the reason for a different enclosure.

For my version which uses KS33 switches I don't see a reason for incompatibility but I have just designed it in the last few days and I haven't ordered or build it yet. Apart from the traces and footprints of the switches I haven't moved anything so I don't see why it wouldn't fit. Also you should check out my fork for cases as I have included a [much nicer case](https://github.com/Lefuneste83/KLOR/tree/main/case/Alternate%20Case%20Design) compared with the stock one. Also the step file is included if you wish to modify it.

Lastly in case you haven't noticed I have validated the haptic module I have designed. I will move the functionality to the main PCB in a coming 1.5 version so it will give us more freedom for other device integration. The optional PCB is nice as it is modular but it brings quite a lot of constraints that we can get rid of. Moving the components footprints directly to the main PCB can free up quite a lot of room to add other I2C supported devices.

joeblackwaslike, 2024-11-20:
@Lefuneste83 I would like to express my sincere appreciation for the improvements you made on the Klor 1.3 PCB.  After several unsuccessful attempts at building it myself, your modifications have me eager to give it another go, this time with the confidence that your changes have resoilved the issues previously encountered.

I recently attempted to order the new Klor 1.4 PCB (full height) using the zip file in your forked repository. However, I encountered an issue with JLCPCB, where they warned me about a minimum hole size of 0.2 mm, with a diameter of 0.4 mm in the file. They recommended a 4-Wire Kelvin Test to ensure the quality of my order, which would incur an additional cost of ~$60.  Alternatively, they suggested modifying the hole size/diameter to 0.2/0.45mm, which would eliminate the need for the test.

Given that my expertise does not lie in PCB design, I am unsure of the implications of this warning. I would be incredibly grateful if you could provide some guidance on this matter. Is this something I should be concerned about? If so, could you possibly assist me in making the necessary modifications?

Thank you once again for your invaluable contribution to improving the Klor PCB. Your expertise and dedication are truly admirable.

Lefuneste83, 2024-11-20:
This is weird, I've never had this issue when ordering on JLCPCB as I use their design rules to validate the design. I'll have a look and let you know.

Lefuneste83, 2024-11-20:
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

Note sure what zip file you tried.

Firstly please submit this kind of issue on my fork directly [here](https://github.com/Lefuneste83/KLOR), as it concerns a design hosted there and this can be confusing for some.

I have just tried ordering a batch of PCB with my latest 1.4 version zip file from my forked repo and I don't get any warning. Let me know at what stage of the ordering process you get this kind of warning.

When ordering you just need to upload the zip file and choose the number and color of the PCB. Nothing else. By default JLCPCB has removed the board markings so there is nothing else that should be modified in the PCB specifications except if you want to improve it for instance having ENIG finish but this will cost you more. Be aware that if you modify other parameters, sometimes the calculated total will not revert back to the previous default price if you revert your specification. There seem to be some bugs in the JLCPCB web page for this.

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

joeblackwaslike, 2024-11-22:
@Lefuneste83 I did everything exactly as you described, I checked out and paid, later that day I got the following email from jlcpcb.

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

I have since cancelled that order, and placed a new one which uses the exact zip file you linked to above, and ensuring I followed all your instructions exactly, will update this thread on what happens.

Lefuneste83, 2024-11-22:
Maybe they changed something in their requirements. Let me know and I'll do the modifications if required.

joeblackwaslike, 2024-11-24:
@Lefuneste83 the second try worked with no issues, for what it's worth.

I noticed the improvements being made in 1.5 and may wait on that to be verified since it seems to address many pain points I experienced with the original 1.3.

Lefuneste83, 2024-11-25:
Keep in mind that the 1.5 version has integrated haptic linear actuator and driver along with several small smd parts. You will thus need extended SMD soldering experience and equipment in order to successfully build one! For hand soldering I recommend sticking to 1.4 version which is good enough in most cases. Just keep an eye on the master MCU temperature.

sQVe, 2025-03-18:
@Lefuneste83 Ouff. I'm finishing my KLOR build with this PCB - and just now noticed that the tenting puck is moved slightly. This information isn't available in the fork, but only here :sad:

Is there any acrylic cutout patterns available for this new placement?

Lefuneste83, 2025-03-18:
> [@Lefuneste83](https://github.com/Lefuneste83) Ouff. I'm finishing my KLOR build with this PCB - and just now noticed that the tenting puck is moved slightly. This information isn't available in the fork, but only here :sad:
>
> Is there any acrylic cutout patterns available for this new placement?

Sorry to hear that, but don't worry it is very easy to solve.

My fork landing page clearly states the following :

_Very slight movement of the puck mounting holes downward (98.57 mm instead of 96.4 mm) by a couple milimeters to catter for reversed switches pad postions. I could not do otherwise without revisiting the switch layouts. I could not solve this by rotating the 3 mounting holes without interfering with other nets. It should not affect the mounting ability of the puck itself, but it WILL interfere with existing back cases using the puck cutout. So we will need specific cutouts for the case. As I don't have access to the original step model the best option would be to use some alternate case design provided with source files in order to lower the cutout by the same amount (2.17 mm)._

So you just have to get the stock svg file for the acrylic back of your choice containing the round cutout for the puck and move this object down by 2.17mm. Any vector based design software can do this operation in one second. Hope this helps !

sQVe, 2025-03-19:
@Lefuneste83 I totally missed that, but yeah 🤷‍♂️

It actually works well to mount the tenting puck with a screw in just one of the holes, since the case itself stabilizes things. I added some electrical tape on the tenting puck legs as a precaution. It's not the most robust solution, but seems to work.

I'll order some new acrylic cutouts later on when I have a larger order.

Also, thank you for this great PCB design (and quick response) 🍻

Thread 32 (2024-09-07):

VIAL QMK support now operational on RP2040 boards

Lefuneste83, 2024-09-07:
For those still struggling with compilation of KLOR QMK firmware, config files for both QMK and ZMK can be [found here](https://github.com/Lefuneste83/KLOR/tree/main/FIRMWARE):

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

For extra convenience if you intend to modify your firmware for a smaller layout, I have also created a link to :

 -  A [full POLYDACTYL layout](http://www.keyboard-layout-editor.com/#/gists/8ff2b448f2ef6c56c2b932e83ebf040f)
 -  A [KONRAD layout](http://www.keyboard-layout-editor.com/#/gists/49ff09e68b46feb39760467424a4601a)
 -  A [YUBITSUME layout](http://www.keyboard-layout-editor.com/#/gists/dc3fdb427b3102ccbf85252e2e278918)
 -  A [SAEGEWERK layout](http://www.keyboard-layout-editor.com/#/gists/b3775d73a84de0d544ea3bf84bafb047)

This can be useful for VIA or VIAL json definitions

****

-  Added support for VIAL firmware for RP2040 boards ONLY. You can now compile :

      the "default" layout using [QMK toolchain](https://github.com/qmk/qmk_firmware) and the command :

            qmk compile -kb electronlab/klor -km default -c

      or "vial" layout using [vial-qmk toolchain](https://github.com/vial-kb/vial-qmk) and the command :

            make clean && make electronlab/klor:vial

-   Also be aware that I have now enabled firmware based handeness definition ([#define EE_HANDS setting](https://docs.qmk.fm/features/split_keyboard)) so you should flash the firmware using the following commands for left and right keyboard sides :
-
   For QMK environment

             qmk flash -kb electronlab/klor -km default -c -bl uf2-split-left
             qmk flash -kb electronlab/klor -km default -c -bl uf2-split-right

  For VIAL-QMK environment

             qmk flash -kb electronlab/klor -km vial -c -bl uf2-split-left
             qmk flash -kb electronlab/klor -km vial -c -bl uf2-split-right

-  Make sure you switch your serial communication to HALF DUPLEX as software pin swap used for full duplex does not seem to work well with firmware based handeness detection. If you always want to plug one side of the keyboard then you can set the master side in config.h and switch to full duplex with software pin swap. This will require a little testing but it will work eventually

                  //Half Duplex communication
                  //#define SERIAL_USART_TX_PIN GP1     // USART TX pin

                  //Full Duplex communication
                  #define SERIAL_USART_TX_PIN GP4     // USART TX pin
                  #define SERIAL_USART_RX_PIN GP1     // USART RX pin
                  #define SERIAL_USART_FULL_DUPLEX
                  #define SERIAL_USART_PIN_SWAP

-  More about this matter [here](https://docs.qmk.fm/drivers/serial)

-  My version of ZMK firmware with Github Actions pipeline is [located here](https://github.com/Lefuneste83/zmk-config-klor):

It has both encoders working, precise pulse per rotation adjustments and RGB enabled by default.

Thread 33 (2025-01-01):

Encoder & Knob dimensions clarification

hoijui, 2025-01-01:
I would like to clarify some things for me, and would offer to then adjust the build-guide accordingly, if you wish so.

You suggest a short EC11 encoder. The one you give as an example has a shaft-height of 15mm.
20mm and 15mm seem to be the most common heights, but there are also 12.5mm and 9.5mm. I imagine those would be pore problematic, to find a good know for, and I don;t know if it makes sense to choose them that short anyway.. could it make sense, or would it maybe be good to recommend 15mm height directly?
The knob you designed, if I saw that right, has a height of 15mm and a diameter of 22mm. Does that mean, the encoders shaft-height and the knob height should be equal?
I would also add that the 22mm you suggest are the diameter.
Is 22mm also the maximum diameter to not block the keys or fingers while one is not using the knob?

Lefuneste83, 2025-04-11:
Hi there. Sorry for the late reply I didn't catch on your post. So the max diameter of the knob is determined by the hole in the provided case design. I measure it to be at around 23mm but I would stick to 22 for safety. For the stem length it depends very much of the knob design you choose. The 3d design knob is not my design so I cannot realy help on this, also because I have used aluminum knobs bought on Aliexpress. What I can say is that you would more likely end up with a too long shaft than a too short one, depending of the knob you pick. With a shaft too long, you would end up with the knob extendind too much which is not good looking but without any impact on functionalities. I would not go above 15mm, 12.5 will work in most cases. The set screw being at the bottom of most knobs, 9.5mm should also work without issues. There is no real definitive answer, it depends of your choice of knob. But I suggest sourcing a nice metal knob, this will improve your overall experience. Also I would recommand a more conical shape knob to minimize interactions while typing. Purely round knobs may be annoying as they may interfere with you fingers when typing fast. Hope this will help.

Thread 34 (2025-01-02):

MCU sockets docu

hoijui, 2025-01-02:
The BoM mentions MCU sockets.
As I am a newb, I was a bit lost with that. After searching quite some, I figured that one possible solution is to look for "DIP 24 wide socket round hole", which should fit the ProMicro, when using diode legs soldered onto the controller board.

I would like to document this in the build-guide, so other newbs don't have to research it.
What do you think?

## Details

important info:

- A Pro micro has 2 rows of 12 pins each -> DIP 24.
- The distance between the legs is 0.1" (2.54mm), which is the standard.
- The distance between the two rows of pins, measured from the center of a pin to the center of a pin on the other row) is 0.6" (15.24mm).
- (redundant but nice to know/check:) distance from the first to the last (12th) pin is 11 * 0.1" = 1.1" (27,94mm)

This is met by "DIP 24 Wide", and the "round hole" sockets work well with the diode legs.

One can find this info sometimes on the site where one can buy the sockets, or looking at [datasheets](https://www.farnell.com/datasheets/217369.pdf) (here specifically the 800 series, page 16 of the PDF, aka page A15).

Lefuneste83, 2025-04-11:
You are right to mention sockets choice as this is definitely the most difficult part of this build. I ended up using low profile round pin sockets but these can be difficult to source. The issue comes mostely from the 3d case design which does not provide enough clearance for a normal Dupont style socket heighth. Make sure you test clearance before soldering if you wish to use socket mount. In most cases I would recommand not using sockets but first builders may end up having problems unsoldering the MCU if something goes wrong so it is a bit of a pain to give a definitive answer. Diode pins is the proposed solution for MCU legs, but a better one IMO is to get some copper or brass wire with the correct diameter to match the low profile sockets. You get a spool for a few dollars and it is more convenient to use compared to getting diode pins with a constant diameter. It is still a bit of a pain to populate all holes of the MCU but not as much as cutting diode legs to proper length. With a spool you have more freedom and have plenty of spare. Hope this helps.

hoijui, 2025-08-14:
today I finally put together the laser-cut plywood case. there is still a lot wrong with it, but now I have an overview/an idea how to finish it.
I did end-up getting a copper wire, but.. it took a few attempts. according to the specs, the diameter of the MCU socket holes is 0.89mm. I tried 0.85mm copper wire first, but that would not go in at all. then I tried 0.8mm, which required a bit of force, but not much. the issue though, is that it is not impossible to remove the board from the socket, because... while it is possible to pull out a single wire from its whole, it is not possible to pull out the board with all its 24 PINs without cracking the board into pieces. so.. my next try will be with 0.7mm copper wire. if that will be too loose, I will maybe use 0.8mm for 4 holes, and 0.7mm for the rest.

hoijui, 2025-08-14:
... ouh, and yes, the socket + MCU sticks out by about 3mm in total from the bottom of the stacked case.

I have no special desire to have the keyboard very thin, so that is Ok for me, but I have to add an other layer to the case now.

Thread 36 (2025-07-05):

Trackball part substitute?

curvedJavelin, 2025-07-05:
I saw from the parts list that there is integrated support for Trackball, I saw as much with the PCBs that I got printed.

It seems that the one listed from Yushakobo has been out of stock?

https://shop.yushakobo.jp/products/adtb7m

Does anyone know any substitute or replacement part for this?

Thank you!

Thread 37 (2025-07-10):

Device input is not detected

MoiMorua, 2025-07-10:
After flashing the keyboard using qmk toolbox, which gave the output:

Caterina device connected: Arduino LLC Arduino Leonardo (2341:0036:0001) [/dev/cu.usbmodem21201]
Attempting to flash, please don't remove device
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
Flash complete
Caterina device disconnected: Arduino LLC Arduino Leonardo (2341:0036:0001) **[/dev/cu.usbmodem21201]

When I connect the device it appears in qmk toolbox as: SB device connected: Geigeigeist Klor (3A3C:0001:0100)

And macos command 'system_profiler SPUSBDataType' gives the output for the device:
Klor:

              Product ID: 0x0001
              Vendor ID: 0x3a3c
              Version: 1.00
              Speed: Up to 12 Mb/s
              Manufacturer: Geigeigeist
              Location ID: 0x02120000 / 4
              Current Available (mA): 500
              Current Required (mA): 500
              Extra Operating Current (mA): 0

But the os does not receive any input.

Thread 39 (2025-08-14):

New Repo!

hoijui, 2025-08-14:
This repo is mostly abandoned, and there are a lot of useful updates on <https://github.com/Lefuneste83/KLOR>. I highly recommend you to use that instead.
If for nothing else, use it because of the new LEDs used there, which are the biggest issue you will face with this build.

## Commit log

2022-06-21 add PCB files
    [klor1_3-B_Mask.gbs, klor1_3-B_Paste.gbp, klor1_3-B_Silkscreen.gbo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]
2022-06-21 add PCB image
2022-06-21 add PCB readme
2022-06-27 add case files
2022-06-27 add case parts
2022-06-27 plates and build guide
2022-06-27 plate and build guide
2022-06-27 dies und das
    [KLOR_konrad_3DP_switchplate.dxf, KLOR_konrad_acrylic_switchplate.dxf, KLOR_polydactyl_3DP_switchplate.dxf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]
2022-06-28 add FR4 switchplates
2022-06-28 update switchplates
    [KLOR_konrad_acrylic_case_switchplate.dxf, KLOR_polydactyl_acrylic_case_switchplate.dxf, KLOR_saegewerk_acrylic_case_switchplate.dxf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]
2022-06-28 add switchplate STLs
    [KLOR_konrad_3DP_switchplate.stl, KLOR_konrad_acrylic_case_switchplate.stl, KLOR_polydactyl_3DP_switchplate.stl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]
2022-06-28 switchplate readmes
2022-07-01 add case 3DP case files
    [KLOR_konrad_case_L.stl, KLOR_konrad_case_R.stl, KLOR_konrad_case_ble_L.stl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]
2022-07-01 update case 3DP case files
    [KLOR_konrad_case_L.stl, KLOR_konrad_case_ble_L.stl, KLOR_polydactyl_case_L.stl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]
2022-07-02 add puck cases
    [KLOR_konrad_case_ble_puck_L.stl, KLOR_konrad_case_ble_puck_R.stl, KLOR_konrad_case_puck_L.stl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]
2022-07-02 add case renders
2022-07-07 update 3DP case files
    [KLOR_konrad_case_L.stl, KLOR_konrad_case_R.stl, KLOR_konrad_case_ble_L.stl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]
2022-07-08 update Gerbers
    [klor1_3-B_Mask.gbs, klor1_3-B_Paste.gbp, klor1_3-B_Silkscreen.gbo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]
2022-07-08 update PCB files and gerbers
    [klor1_3-B_Mask.gbs, klor1_3-B_Paste.gbp, klor1_3-B_Silkscreen.gbo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]
2022-07-20 update acrylic case files for 3DP cases
    [KLOR_konrad_3DPcase_acrylic.dxf, KLOR_konrad_3DPcase_acrylic_logotype.dxf, KLOR_polydactyl_3DPcase_acrylic.dxf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]
2022-08-22 Update 3DP case acrylic files
    [KLOR_konrad_3DPcase_acrylic.dxf, KLOR_konrad_3DPcase_acrylic_logotype.dxf, KLOR_polydactyl_3DPcase_acrylic.dxf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]
2022-08-22 fixed case files
    [KLOR_konrad_case_L.stl, KLOR_konrad_case_R.stl, KLOR_konrad_case_ble_L.stl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]
2022-09-01 Case size fix
    [KLOR_konrad_case_L.stl, KLOR_konrad_case_R.stl, KLOR_konrad_case_ble_L.stl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]
2022-11-13 update standoff informations
2022-12-29 Added OLED as KMK firmware feature
    Added OLED as KMK firmware feature + encoders (plural) are now working
2023-04-01 update BOM and readme
